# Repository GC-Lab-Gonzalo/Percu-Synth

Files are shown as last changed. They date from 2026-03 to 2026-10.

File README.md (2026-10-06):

# PercuSynth

**PercuSynth** es un laboratorio portátil de experimentación con electrónica, programación y síntesis de audio, desarrollado por **GC Lab Chile**.

La percusión y los sintetizadores son la excusa: el arte y la música son la puerta de entrada a un proceso de aprendizaje más amplio, donde explorar electrónica, código y tecnología se vuelve natural, entretenido y con sentido. Es un proyecto diseñado bajo la metodología **STEAM** — donde la ciencia, la tecnología, la ingeniería y las matemáticas se integran con el arte como motor creativo.

<p align="center">
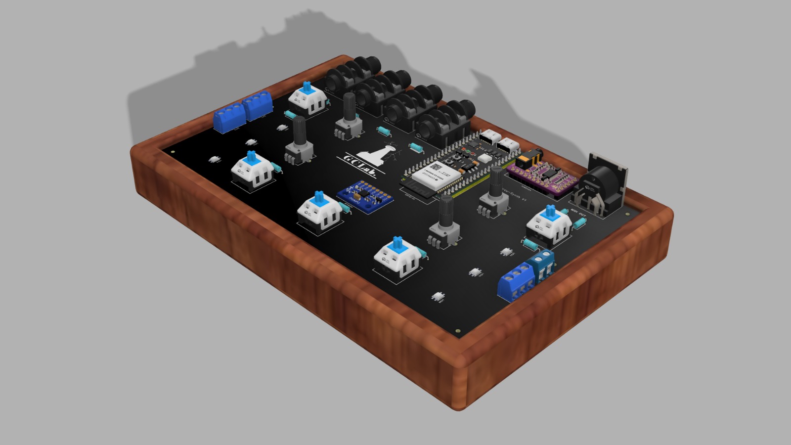
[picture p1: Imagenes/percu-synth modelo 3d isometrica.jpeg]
PercuSynth - modelo 3D
  
</p>

El hardware es compacto, portátil y basado en el microcontrolador **ESP32-S3**. Desde él se puede experimentar con síntesis de sonido, secuenciadores, controladores MIDI, sensores de movimiento, sampleo, luces reactivas y mucho más. Los firmwares y las herramientas web disponibles son solo el punto de partida — **el proyecto está en desarrollo activo** y las posibilidades son abiertas.

---

## ¿Qué se puede hacer con PercuSynth?

El laboratorio permite explorar una amplia variedad de ideas, por ejemplo:

- Sintetizadores y máquinas de ritmo con síntesis de audio en tiempo real
- Controladores MIDI para software de producción musical
- Secuenciadores de pasos con patrones grabables
- Detección de golpes y gestos con sensores piezoeléctricos e IMU
- Instrumentos por impacto y drones por vibración (el equipo apoyado en el piso)
- Reproducción de samples y loops cargados desde el navegador
- Experimentos con filtros, osciladores, envolventes y efectos digitales
- Visuales reactivas en tira o matriz LED WS2812 sincronizadas con sonido o gesto
- Síntesis audiovisual de video y videojuegos controlados por el hardware
- Máquinas generativas que componen solas: canciones, paisajes sonoros y ambientes de película
- Conexión con servicios de IA desde la propia placa: pedir un sonido o una canción hablando
- Integración con software como Ableton, GarageBand, Pure Data, etc.

Los firmwares y herramientas del repositorio son ejemplos concretos de estas posibilidades. El proyecto crece con cada experimento nuevo.

---

## Hardware

<p align="center">
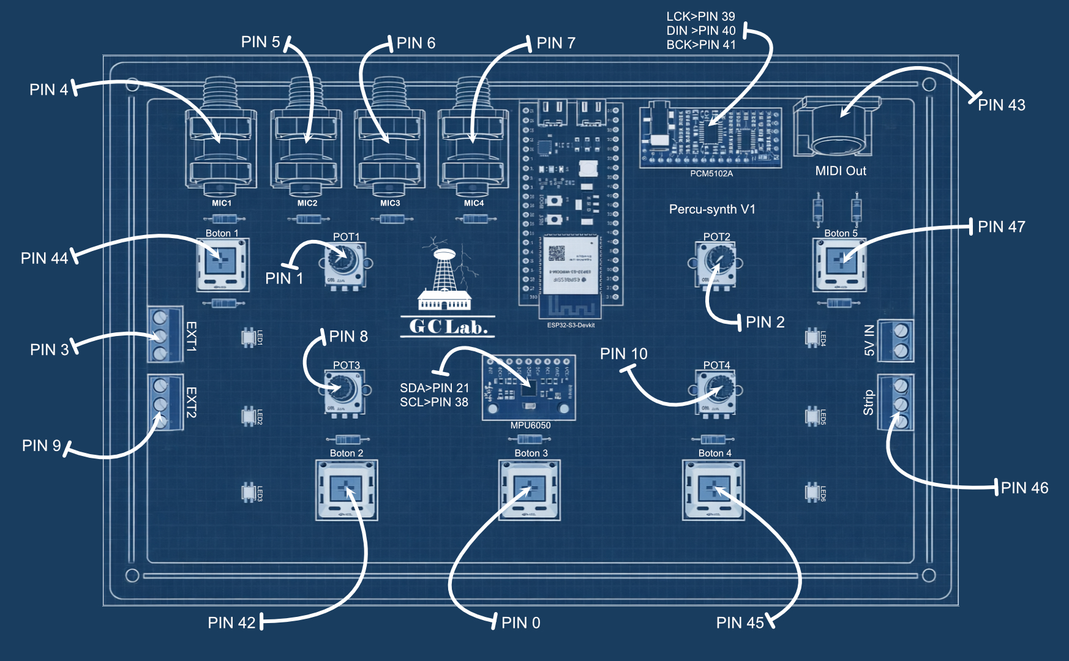
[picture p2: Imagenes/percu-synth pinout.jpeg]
PercuSynth - Pinout
  
</p>

> **Tip para usar con IA:** puedes subir directamente la imagen del pinout a cualquier asistente de IA (Claude, ChatGPT, Gemini, etc.) para que entienda el hardware y te ayude a crear nuevos firmwares. Mejor aún: pásale el [documento de contexto para IA](PROMPT_PARA_LA_IA.md) ([versión PDF](PROMPT_PARA_LA_IA.pdf)) — un documento madre con pinout, settings del Arduino IDE, librerías y patrones de código listos para que la IA genere firmware a la primera.

### Componentes principales

- **Microcontrolador:** ESP32-S3 (USB nativo, WiFi, Bluetooth)
- **DAC de audio:** PCM5102 vía I2S — salida estéreo 44.1 kHz · 16-bit
- **IMU:** MPU6050 — acelerómetro + giroscopio para control gestual (I2C)
- **Entradas:** 5 botones, 4 potenciómetros, 4 sensores piezoeléctricos, 2 sensores analógicos externos
- **Salidas:** Audio I2S · tira/matriz LED WS2812 · MIDI USB nativo · MIDI DIN-5

> **¿Quieres armar el tuyo?** La [lista de materiales](MATERIALES.md) tiene cada componente con su término de búsqueda, los tres caminos para armarlo (PCB fabricada, protoboard o placa perforada) y cómo pedir la placa en JLCPCB. Comprar la PCB es opcional.

### Pinout

| Señal | Pin ESP32-S3 |
|---|---|
| I2S LRCK | 39 |
| I2S DATA | 40 |
| I2S BCLK | 41 |
| Botones | 44, 42, 0, 45, 47 |
| Potenciómetros | ADC 1, 2, 8, 10 |
| Piezos | ADC 4, 5, 6, 7 |
| LED WS2812 (datos) | 46 |
| MIDI DIN-5 TX | 43 |
| I2C SDA (MPU6050) | 21 |
| I2C SCL (MPU6050) | 38 |
| Sensor externo A | ADC 3 |
| Sensor externo B | ADC 9 |

Todos los firmwares de audio generan señal a **44.1 kHz, 16-bit estéreo** a través del DAC PCM5102, con buffers DMA de 128 muestras.

### Archivos de circuito (`Hardware/`)

El diseño electrónico está abierto para que puedas fabricar tu propia placa o estudiar las conexiones:

La versión vigente es la **V2.0** (septiembre 2026): cada entrada de piezo lleva ahora diodo Schottky 1N5817 + 10 nF + 100 kΩ, y la placa trae sitio para el micrófono INMP441 y un conector OLED opcional. La lista de materiales completa está en [`MATERIALES.md`](MATERIALES.md).

- [`Schematic_Percu-synth_V2.0.pdf`](Hardware/Schematic_Percu-synth_V2.0.pdf) — esquemático completo
- [`PCB_1-PCB_PCB_Percu-synth_V2.0.pdf`](Hardware/PCB_1-PCB_PCB_Percu-synth_V2.0.pdf) — vista del PCB (top y bottom) para ubicar componentes
- [`Gerber_Percu-synth_1-PCB_PCB_Percu-synth_V2.0.zip`](Hardware/Gerber_Percu-synth_1-PCB_PCB_Percu-synth_V2.0.zip) — gerbers listos para enviar a fabricar

Los archivos `V1.1` siguen en `Hardware/` sólo como referencia de las placas antiguas.

- [`base_3d/`](Hardware/base_3d/) — **base imprimible en 3D** que reemplaza el marco de madera (STL y 3MF listos, más `generar_base.py` para ajustarla)
- [`LISTA_ALIEXPRESS_Percusynth.txt`](Hardware/LISTA_ALIEXPRESS_Percusynth.txt) — la lista de materiales de la V2.0 con los **links de compra** en AliExpress

---

## Firmwares disponibles

Cada firmware es un sketch Arduino independiente (`.ino`). Se compila y se carga por separado — no hay sistema de build centralizado. Los siguientes son los firmwares desarrollados hasta la fecha; el proyecto está en desarrollo activo y se irán sumando más experimentos con el tiempo.

### Síntesis y secuenciadores de audio

#### `drum_machine_basic` — Drum Machine con Secuenciador
- 10 voces polifónicas: kick, snare, hi-hat, crash, click
- Síntesis por osciladores + ruido LCG + filtros biquad bandpass en cascada
- Secuenciador de 4 pistas × 16 pasos con grabación en tiempo real
- Control de tempo y timbre por potenciómetros

#### `drum_ruido` — Drum machine de timbres ruidosos, salida limpia
- **Ruidoso no es distorsionado:** la suciedad se hace con *síntesis* (parciales inarmónicos, dos envolventes por golpe, saturación por bandas), nunca rompiendo el audio — nada de bit-crush ni diezmado, que solo producen aliasing
- **Los patrones son aleatorios:** no hay ritmos de fábrica. Cada BTN1 sortea 32 pasos nuevos con el "feel" del kit activo
- 5 kits (CYBER · DUBSTEP half-time · GLITCH · INDUSTRIAL · CAOS) y 7 pistas: kick, snare, hats, clank, metal, blast y bajo
- Un botón = una función: BTN1 patrón · BTN2 timbre · BTN3 tap tempo · BTN4 half-time · BTN5 fill. POT4 = beat repeat ×2/×4/×8/×16 sobre un reloj maestro que nunca se desfasa
- No hay play/stop: la máquina siempre corre, POT1 a cero es el mute. Requiere **FastLED**

#### `drum_poder` — Drum machine con peso + reloj MIDI por el DIN-5
- Hermana de `drum_ruido` con el signo cambiado: **acá no hay ruido como estética**. Bombos redondos con pegada de mazo, cajas grandes y afinadas, toms cantados, platos con brillo controlado
- **12 grooves escritos a mano** en el idioma de Sleep Token, Tool y Dream Theater, con compases impares de verdad: 7/8 (3+2+2), 5/8+7/8, 9/8, 13/8, 5/4, 12/8, doble bombo y 4/4 desplazado (3+3+3+3+2+2). Los patrones se escriben **como texto**, un carácter por semicorchea
- **Por el MIDI DIN-5 sale el RELOJ, no notas** (GPIO 43, 31250 baud): MIDI Clock a 24 PPQN + Start, y Stop+Start cada vez que se reubica el "1". La melodía la pone el sinte que lo recibe. Hubo tres versiones con bajo adentro (línea escrita por groove, tabla de ritmos sobre una grilla, patrones derivados del bombo) y las tres se descartaron: elegir el sonido y la secuencia en el sinte es más expresivo que cualquier tabla metida en el firmware, y el único trabajo real de la máquina es dar un pulso que no se mueva. Verificado: el tempo del reloj cae dentro del **0.04 %** del BPM en los 12 grooves
- **Es percusión y nada más**: la melodía la hacen las notas MIDI. Sólo el SUB (abajo de 60 Hz) sigue el acorde; todo lo que vive arriba de 1 kHz es **ruido filtrado** — no tiene nota, así que no puede hacer melodía —, y el decay tiene presupuesto por banda: el peso abajo es largo (sub 2.1 s, bombo 1.3 s) y arriba todo es corto (hat 0.13 s, tick 0.07 s)
- 8 pistas con **su propia banda** cada una (sub, bombo, toms, caja, clap, tick, hats, metal) y cadena de master fija: sidechain → sala corta → saturación de cuerpo → filtro → compresor de bus → limitador **con lookahead** → techo de 13 kHz
- **Exactamente los controles de `drum_ruido`, uno por uno**: BTN1 groove · BTN2 kit · BTN3 tap tempo · BTN4 medio tiempo · BTN5 redoble; POT1 volumen · POT2 filtro · POT3 cuerpo · POT4 beat repeat. Sin paneles, sin combos y sin pots congelados: todo eso existió mientras el firmware generaba las notas del bajo
- **El SUB lleva 2º y 3er armónico**: su fundamental vive en 33–45 Hz, así que en un parlante chico lo que se oye son los armónicos y el oído reconstruye la que falta
- **El audio corre en su propia tarea en el core 1** y los controles en el core 0. El ADC y `FastLED.show()` compartiendo `loop()` con el render eran lo que hacía que el DMA se quedara sin datos en los patrones densos y en los fills: eso era el chasquido. Y por lo mismo **no hay ni un `Serial.print`**. Requiere **FastLED**

#### `synth_basico` — Sintetizador Polifónico
- 5 voces con morphing de forma de onda (senoidal → cuadrada → diente de sierra)
- Vibrato LFO (±1.2%, 0.2–8.2 Hz) y filtro pasa-bajos one-pole controlados por potenciómetro
- Notas mapeadas a los botones: C4, D4, E4, F4, G4

#### `trance_imu` — Secuenciador de Trance Polifónico (IMU)
- Port del secuenciador de trance del **Proto-Synth v2** a I2S 44.1 kHz / 16-bit estéreo (audio de otra liga, buffers DMA no bloqueantes)
- **Polifónico:** cada paso dispara un acorde de 4 voces sobre un pool de 16 voces → textura "pluck de trance" con cola
- Osciladores sierra anti-aliasing (PolyBLEP) + filtro pasa-bajos resonante biquad **controlado en vivo por el IMU** (eje X → cutoff, eje Y → resonancia)
- 3 paneles de control (combos de botones): normal / notas-tonalidad / timbre-síntesis. Sin LEDs ni Serial: todo el CPU va al audio

#### `trance_imu_leds` — Trance Polifónico + 6 LEDs de placa
- Igual que `trance_imu`, pero usa los **6 LEDs WS2812 SMD internos** de la placa como visualizador (VU polifónico + flash al beat + color según el filtro IMU + paleta por panel)

#### `pads_imu` — Pads ambient profundos (sin secuenciador)
- Hermano ambient de `trance_imu`: **mismo motor de audio, pero sin patrones**. Los 5 botones latchean **acordes sostenidos** (attack → sustain → release sobre un pool de 32 voces, estéreo con detune y paneo por voz)
- **5 bancos de 6 acordes** + capa opcional de **arpegio** (6 tipos) sobre el acorde activo
- **Modo AUTO:** progresión diatónica generativa que se repite en 4/4, para dejarlo sonando solo
- 3 paneles de control; el IMU barre el filtro

#### `pads_imu_leds` — pads_imu + 6 LEDs de placa
- Igual que `pads_imu`, con los 6 LEDs SMD como visualizador: paleta por panel, barra de energía del pad y un **punto que avanza con cada nota del arpegio**. También maneja el LED RGB del módulo (GPIO48). Requiere **FastLED**

#### `cancion_aleatoria_leds` — Máquina de canciones aleatorias
- **Autónoma:** un botón de Play/Stop y tres perillas de volumen (pad / melodía / percusión). Nada más
- Cada Play genera **una canción entera y coherente**: sortea tonalidad, modo (7 escalas), progresión diatónica, BPM, voicing, síntesis y ritmo del pad
- Encima corre una **melodía monofónica generativa** organizada en frases (cada frase sortea su propio ritmo, timbre, registro y envolvente) que siempre cae en la escala
- Y una **percusión sintetizada aleatoria** (kick, snare-rim, hats — sin samples) con acentos, ghost notes y un mini-fill cada 4 compases
- 5 arquetipos (AMBIENT / CINEMATIC / PULSE / PLUCK / DRIVE) fijan el carácter global, así que las canciones suenan **categóricamente distintas** entre sí. Stop → Play = canción nueva. Requiere **FastLED**

#### `paisajes_relax_leds` — Paisajes sonoros para relajar
- **10 capas sintetizadas en tiempo real** (sin samples) que se combinan libremente: viento, olas, campanitas, gotas de agua, grillos, fogata, lluvia, cuenco tibetano, arroyo y pájaros
- Cada botón enciende una capa (toque = principal, mantener >0.6 s = alterna). Todo **seco y natural**, sin delay ni reverb
- Dos anillos WS2812 de 30 LEDs (afuera = eventos, adentro = ambiente). Arranca en silencio. Requiere **FastLED**

#### `cyber_kit` — Secuenciador de texturas, FX y leads
- **No es una drum machine:** 4 bancos × 5 sonidos (LEADS / TEXTURAS / FX / BAJOS) — leads neón, campanas FM, hoovers, risers, nubes granulares, drones oscuros, zaps, glitches, reeses, subs
- Los sonidos afinados viven **dentro de una escala seleccionable** (10 escalas, tónica variable)
- **Disparo instantáneo:** los botones suenan en el flanco de presión, y los combos de dos botones *deshacen* la acción individual con un fade de 4 ms. Se toca al tiro y los combos igual funcionan
- 2 modos: PERC (los botones disparan) y SEQ con transporte completo (play/stop, reversa, beat repeat, velocidad, caos)
- 4 paneles de pots, incluido uno de **macros de síntesis** (attack 0.5 ms–0.8 s, decay, textura, pitch global ±12). Requiere **FastLED**

#### `oscilador_escalas` — 4 pots = 4 osciladores por escala
- Port del sketch `Oscilador_4_escalas` del **Proto-Synth v2**, **sin Mozzi**, al motor I2S estéreo de 44.1 kHz del PercuSynth
- La idea original intacta — cada pot es un oscilador cuantizado a la escala activa — pero por debajo: stack de **3 voces en unísono** paneadas + sub-oscilador, formas de onda **PolyBLEP**, portamento de 40 ms y cuantización **con histéresis** (el ruido del ADC ya no hace saltar la nota)
- Controles directos, sin paneles ni combos: BTN1 escala (10) · BTN2 octava · BTN3 intermitencia · BTN4 mantenido + POT1 = tempo · BTN2+BTN4 = menú de 5 modos · BTN5 forma de onda
- Filtro resonante barrido por el eje X del IMU + **delay ping-pong** cuyo tiempo lo fija el tap tempo. Requiere **FastLED**
- Audio en su propia tarea en el **core 1** y controles en el core 0: así los 4 osciladores en cuadrada o pulso ya no vacían el DMA (era el ruido que aparecía al cambiar de onda)

#### `oscilador_escalas_clock` — El mismo dron + reloj MIDI por el DIN-5
- `oscilador_escalas` con **MIDI Clock por el DIN-5** (24 PPQN, sólo reloj, nada de notas) al tempo del tap: **Start al activar la intermitencia, Stop al apagarla, Stop+Start en cada tap** para que el "1" del sinte externo caiga en el mismo corte
- El clock se **cuenta en el audio** con el mismo contador que el corte (cero deriva) y se **manda desde la tarea de control** a 1 kHz. Los ticks salen siempre, aun parado, para que el sinte ya tenga el tempo cuando llegue el Start
- Los **6 LEDs prenden al ritmo de la intermitencia** (siguen la envolvente que corta el audio) y el **LED RGB del módulo muestra el color de la nota** que suena, pasando al siguiente oscilador activo en cada pulso. Requiere **FastLED**

#### `bajo_8_pasos` — Secuenciador de bajo de 8 pasos
- **8 pasos** de un **bajo monofónico lleno de armónicos**: dos sierras PolyBLEP desafinadas + cuadrada una octava abajo, saturación suave y filtro pasa-bajos resonante con **envolvente de filtro**
- Creado en conjunto con los participantes del **taller abierto en Hive Espacios**
- Todas las notas en **La pentatónica menor** (11 notas por pot, 2 octavas; pot al mínimo = paso en silencio)
- BTN1 **play/stop** · BTN2 **panel A** (notas de los pasos 1–4) · BTN3 **panel B** (pasos 5–8) · BTN4 **panel C** (volumen · velocidad · decay · cutoff) · BTN5 **octava**
- Al cambiar de panel un pot **sólo toma el control cuando lo mueves**: saltar de panel nunca pisa las notas del otro
- **Tira WS2812 de 121 LEDs** encadenada a la placa: cada paso dispara una **bala de luz multicolor** que avanza por la tira al ritmo del tempo. Requiere **FastLED**

#### `bajo_8_pasos_fsr_clock` — El bajo de 8 pasos con FSR al filtro y reloj MIDI
- `bajo_8_pasos` con **dos cosas encima y nada más**: el motor de sonido, los controles y las balas de luz son idénticos
- **FSR (sensor de presión) en EXT1 (GPIO 3)**: apretar **abre el filtro** hasta 3 octavas por encima de donde dejó el POT4 — el pot sigue mandando el reposo y la resonancia, el FSR es expresión en vivo encima (como el IMU en `espacio_modular`). Suelto suena **exactamente igual que el original**
- Los dos extremos (`FSR_SUELTO` / `FSR_APRETADO`) son **lecturas medidas, no constantes mágicas**, y el mapeo es una recta entre ellas: la **polaridad del divisor da lo mismo**. Se calibra con `MOSTRAR_ESTADO` en 1 y el monitor serie
- **MIDI Clock por el DIN-5** (24 PPQN, sólo reloj) al tempo del secuenciador: **Start al Play con el "1" en el paso 1**, Stop al parar, y los ticks salen siempre, aun parado. Contado en el audio con el mismo contador de muestras que los pasos (cero deriva) y mandado desde la tarea de control a 1 kHz
- **La tira de 121 LEDs cambió**: en vez de sólo las balas, **8 efectos que se sortean solos** (balas · ondas · VU · chispas · arcoíris · plasma · bandas · serpiente), uno nuevo cada 4 compases y en cada Play, nunca el que estaba, y con paleta/dirección/parámetro sorteados también. Los ocho reaccionan al golpe del paso, a la nota, a la **envolvente real del bajo** (la publica la tarea de audio) y a la **presión del FSR**
- La tira lleva **su propio limitador de corriente** (`TIRA_MAX_MA`, 300 mA): con la tira colgada del 5 V de la placa, un efecto que prende los 121 LEDs pide ~2 A, hunde el riel y **corta el audio**. Está escrito como un limitador de audio — baja al instante y sube despacio, porque lo que hunde el riel es el *escalón* de corriente. Con fuente propia para la tira se sube ese número y vuelven a brillo completo. Requiere **FastLED**

#### `industrial_matriz` — Base de bombo y bajo + fábrica en paralelo + matriz 32×8
- **Base**: bombo de tres bandas a negras y el bajo de `bajo_8_pasos` siguiendo una progresión de 4 acordes en La menor, con 6 líneas escritas para caer siempre entre los bombos; un **arpegiador** recorre el acorde y un **pluck** toca una de 8 melodías escritas en grados del acorde
- **Percusión industrial en paralelo**: 6 pistas (hat · martillo · pistón · clap · hat abierto · tom), sin metales afinados. Cada ciclo dura de 10 a 32 pasos y forma un **polirritmo** contra los 16 de la base, que se realinea cada 4 compases
- BTN1 play/stop · BTN2 patrón industrial · BTN3 tema nuevo (acordes + bajo + melodía) · BTN4 mantenido + POT1 = tempo · BTN2+BTN4 = menú de 5 modos · BTN5 break mientras se mantiene · POT1 volumen · POT2 mezcla base↔fábrica · POT3 corte del bajo · POT4 densidad industrial
- **Matriz WS2812 de 32×8** encadenada a la placa: 8 escenas psicodélicas (túnel · plasma · caleidoscopio · espiral · figuras · moiré · ondas · damero) amarradas al tempo, que se sortean cada 4 compases, prueba de orientación al encender y limitador de corriente propio. Requiere **FastLED**

#### `secuenciador_melodico` — 16 pasos en modos griegos *(por Nicolás Martínez)*
- Secuenciador **monofónico** de 16 pasos: cada paso es un **grado de la escala** o un silencio, en uno de los **7 modos griegos** (BTN2 los recorre)
- BTN1 play/stop · BTN3 reversa · BTN4 al azar · BTN5 borrar; POT1 volumen · POT2 tempo · POT3 transposición ±12 · POT4 envolvente
- Trae una **webapp por Web Serial** para editar los pasos en pantalla. Requiere **ESP32Synth** y **FastLED**

#### `secuenciador_melodico_cromatico` — 16 pasos polifónicos, 12 notas *(por Nicolás Martínez)*
- Secuenciador **polifónico** sobre una octava cromática: cada paso puede tener cualquier combinación de las 12 notas (acordes incluidos), 12 voces
- BTN2 cambia la onda (pulso / sierra / triángulo / seno); el resto de los controles como `secuenciador_melodico`
- Webapp por Web Serial con la grilla de 16 × 12. Requiere **ESP32Synth** y **FastLED**

#### `la_partida` — "La partida" de Víctor Jara en 3 pistas MIDI
- Toca el arreglo desde sus **3 pistas MIDI** a los tiempos exactos del archivo (80 BPM, preciso a la muestra): **melodía** con un lead filtrado con vibrato, **bajo** en sierra + cuadrada levemente desafinadas (una octava abajo) y **arpegio** con un pluck electrónico de filtro que se cierra
- BTN1 **play/stop + panel general** (volumen · velocidad) · BTN2 **melodía** (volumen · vibrato · filtro · resonancia) · BTN3 **bajo** (volumen · filtro · resonancia) · BTN4 **arpegio** (volumen · ataque · decay)
- Diseñado para no hacer clicks: una voz de arpegio por altura, ataques que suben desde donde está la envolvente, stop con cierre de 40 ms. Las notas salen del proyecto de Ableton con `extraer_cancion.py`. Requiere **FastLED**

#### `espacio_modular` — Ambientes de película (monofónico)
- **24 patrones que son TEMAS, no figuras:** un tema se define tanto por su ritmo largo-corto como por sus notas, y **cada nota dura hasta la siguiente** — el espaciado *es* la duración. Por eso suena a música de película y no a un arpegio
- Debajo, un **dron continuo** en la tónica y una **progresión no funcional** de un acorde por ciclo de 4 compases (9–38 s por acorde): eso es lo que lo vuelve ambiente en vez de canción
- 8 modos de paleta cinematográfica (eólico, frigio, NÓRDICO, mixolidio, lidio, ÁRABE, BIZANTINO, menor armónica), todos con tríadas consonantes
- Un solo panel: 5 botones y 4 pots, una función cada uno, sin combos ni páginas escondidas. Play sortea el modo, BTN2 sortea el tema
- Imprime modo/tema/tonalidad por Serial en cada botón, para que puedas identificar un sonido que te gustó

#### `impact_chimes` — Campanas por golpe en el piso
- Instrumento por **impacto**: se apoya el equipo en el piso y el **acelerómetro detecta los golpes** → dispara notas de una escala tipo campanas (eólica por defecto)
- Una escala distinta por cada botón; los potenciómetros controlan la síntesis

#### `impact_chimes_leds` — Campanas por impacto + show de luces
- Hermano de `impact_chimes` con **show WS2812 de 68 LEDs** y **3 timbres** (campana / marimba / guitarra eléctrica), en una sola escala mágica: **C lidio**
- Cada golpe en el piso dispara una nota (caminata melódica) y un efecto de luz reactivo. BTN1/BTN5 recorren 5 efectos (onda, cometa, pulso, chispas, arcoíris); BTN2/3/4 eligen el timbre
- Umbral dinámico anti-doble-disparo; FastLED por RMT para no chocar con el I2S. Requiere **FastLED**

#### `laser_chimes` — Campanas al cortar el haz de un láser
- Hermano de `impact_chimes` con el **sensor de entrada cambiado**: un **LDR + 220 Ω en el sensor externo A (EXT1, GPIO 3)** vigila un **haz de láser**; cada vez que algo lo cruza se dispara una nota de la escala
- Mismo motor de sonido y mismos controles que `impact_chimes` (una escala por botón, pots = ataque/decay/brillo/timbre). El corte más profundo suena más fuerte
- El LDR se muestrea a **1 kHz en el core 0** (el audio se queda con el core 1) y la cola de DMA es corta (≈12 ms): la nota se oye en el acto
- Los **límites de lectura del LDR** (`LDR_LASER` / `LDR_TAPADO`) son variables en el `.ino`; con `MOSTRAR_ESTADO 1` el Monitor Serie imprime `raw` y los `min`/`max` vistos para copiarlos directo. Sin librerías externas

#### `grabador_campo` — Grabadora de campo con efectos en las perillas
- El micrófono INMP441 pasa por **ganancia, filtro (pasa-bajos ↔ pasa-altos en un pot), EQ de color y un efecto** (eco ping-pong, catedral, chorus, flanger, phaser) y se graba a una **microSD** (SPI en GPIO 14–17)
- Cada toma deja dos WAV alineados muestra a muestra: el **procesado** (estéreo 24 bit) y el **crudo** del micrófono (mono 24 bit, sin tocar)
- BTN3 **congela** los últimos ~3 s como una nube de granos que el filtro y el efecto siguen moldeando. Colchón de 8 s en PSRAM: la tarjeta nunca corta el audio. Requiere **PSRAM** y **FastLED**

#### `voz_fx` — Procesador de voz en tiempo real
- Hablas o cantas al **micrófono INMP441** y la voz sale transformada por el DAC, sin grabar (~12 ms de latencia)
- **11 efectos** en BTN1: voz limpia, electro con trémolo al tempo, autotune + vocoder, robot, vocoder de 12 bandas, pitch, armonizador, eco de cinta, catedral y más. POT1–3 modifican el efecto, **POT4 es siempre el volumen**; BTN2 prende/apaga la puerta de ruido
- Usa **audífonos**: con parlante el micro escucha la salida y los efectos largos se acoplan. Requiere **FastLED**

#### `mezclador_pistas` — Una canción en 4 pistas desde la microSD, con visuales
- Toca **batería, bajo, voz y otros** desde un solo WAV intercalado en la microSD (SPI en GPIO 14–17), sincronizados a la muestra y en loop. El audio lo mezcla la placa: el computador no lo toca
- Por **bancos**: BTN1 = banco general (POT1–4 = volumen de bajo, voz, batería y otros; mantener = play/stop, 2,5 s = siguiente canción); BTN2–5 = banco de cada pista (POT1 filtro pasa-bajos ↔ pasa-altos · POT2 resonancia · POT3 efecto rítmico gate/repeat al pulso · POT4 intensidad)
- Detecta los golpes de cada pista (y bombo/caja/platillo en la batería) y los manda por USB a **Resonancia**, donde cada pista mueve su capa visual. `preparar_cancion.py` convierte las pistas de Moises/Demucs. Requiere **PSRAM** y **FastLED**

#### `trance_pistas` — Trance sintetizado en 4 pistas, con visuales (sin microSD)
- El hermano sintetizado de `mezclador_pistas`: **trance con peso** (referencia: Chemical Brothers) con la batería de `drum_poder`, el bajo de `bajo_8_pasos`, un riff que sólo toca notas del acorde y un pad que crece por secciones con stabs rave. 6 temas de 32 compases con ruptura y drop, 128–140 BPM; BTN1 mantenido 2,5 s = siguiente tema
- Los mismos bancos y la misma salida serial que `mezclador_pistas`: Resonancia lo trata igual. Se instala **desde Resonancia** (ESP Web Tools), sin Arduino IDE. Requiere **FastLED**; la PSRAM es opcional

#### `oled_video_techno` — Video vertical en la OLED + techno con bombo
- Un **video vertical** (un short) corre en la **pantalla OLED SSD1306 puesta de lado** (64×128), **amarrado al tempo**: al subir el BPM el video se acelera, con Stop se congela, cada Play lo reinicia con el "1" y en cada bombo la pantalla late (contraste)
- Debajo, un **secuenciador techno**: bombo de tres bandas en negras, línea ácida de 16 pasos (acentos y ligados a la 303) y hats. POT1–4 = corte / resonancia / envolvente / decay del filtro; BTN1 play/stop, BTN2 patrón nuevo, BTN3 tap tempo, BTN4 bombo sí/no, **BTN5 graba a la microSD lo que sale por los audífonos** (WAV estéreo 16 bit, sin micrófono; mismo cableado SPI que `grabador_campo`)
- El video se convierte con `convertir_video.py` (ffmpeg → cuadros de 1 bit ya en el orden de memoria de la SSD1306 → `video.h`). Requiere **FastLED** (LED de estado de la grabación)

#### `seismic_drone` — Drones épicos por vibración de la tierra
- Hermano grave de `impact_chimes`: el MPU6050 en **±2g** detecta la vibración del suelo → genera un **dron épico** (sierra estéreo desafinada + sub-oscilador, filtro resonante que "respira")
- Escalas épicas; los potenciómetros controlan la textura

#### `dub_siren` — *(en desarrollo)*
- Sintetizador "sirena dub" con 3 samples polifónicos + oscilador siren con LFO + delay tape con feedback
- Generación del firmware (con samples embebidos) vía `tools/dub_siren_generator/`
- Plan completo y arquitectura en [`firmwares/dub_siren/PLAN.md`](firmwares/dub_siren/PLAN.md)

### Firmwares con IA (requieren WiFi y claves de API)

Estos seis firmwares llaman a servicios externos (OpenAI, NagaAI, ElevenLabs) desde el propio
ESP32-S3. Necesitan además un **micrófono INMP441** por I2S y, salvo los dos asistentes simples
(`asistente_ia` y `asistente_naga`), un módulo **con PSRAM**.

> **Las claves no están en el repositorio.** Cada uno de estos sketches trae un
> `secretos.example.h`: cópialo a `secretos.h` **en la misma carpeta** y escribe ahí tu WiFi y tus
> API keys. `secretos.h` está en el `.gitignore`, así que nunca se sube por accidente. Si falta,
> el sketch no compila y te avisa con un `#error` claro en vez de fallar recién al encender.

#### `asistente_ia` — Asistente de voz (Whisper → GPT → TTS)
- Mantienes BTN1, hablas, y te responde por el parlante. El más simple de la familia: el que conviene leer primero para entender cómo se conecta el hardware a una API
- Micrófono INMP441 (16 kHz mono) → Whisper → GPT-4o-mini → TTS (PCM 24 kHz) → DAC PCM5102, sin resamplear
- Los 6 LEDs SMD indican el estado: verde listo, rojo grabando, ámbar procesando, cian hablando

#### `asistente_naga` — El mismo asistente, sobre NagaAI (una sola clave, modelos gratis)
- [NagaAI](https://naga.ac/) es un **agregador**: una API compatible con OpenAI que enruta a muchos proveedores con **una sola clave y un solo saldo**. Los endpoints son idénticos; lo que cambia es el host, los **nombres de modelo** y un parámetro
- Ojo con eso último: **`whisper-1`, `tts-1` y `gpt-4o-mini` no existen en Naga** (hay `whisper-large-v3`, `gpt-4o-mini-tts`, `llama-3.3-70b-instruct:free`, voces de ElevenLabs…), y el límite de respuesta es `max_completion_tokens`, no `max_tokens`. Copiar los nombres de OpenAI tal cual da 404 y silencio
- Viene con los tres modelos **`:free`** puestos por defecto: funciona **sin gastar saldo**, que es lo que hace falta en un taller con diez placas
- La reproducción **lee la cabecera WAV** en vez de asumir 24 kHz: frecuencia, canales y bits vienen en el archivo y el I2S se reconfigura en caliente, así cambiar de voz no obliga a tocar ninguna constante. Si llega un MP3 lo detecta y **lo avisa por Serial** en vez de reproducir ruido
- `MOSTRAR_ESTADO` imprime todo el recorrido a 115200: lo que entendió, lo que respondió, los códigos HTTP con el cuerpo del error y el formato de audio recibido

#### `asistente_musical` — Conversas con GPT sobre música que nunca se detiene
- Cruce de la cadena de red de `asistente_ia` con el motor de voces de `pads_imu`: **hablas con GPT mientras un fondo armónico generativo sigue sonando**
- El cambio de arquitectura que lo hace posible: un **único mixer de 44.1 kHz** dueño del I2S corriendo en el **core 1**, y el asistente en el **core 0** junto al stack de WiFi — así los segundos que bloquea el TLS no cortan la música
- El TTS llega a 24 kHz y se **resamplea a 44.1 kHz**, pasa por un pasa-altos con cutoff en un pot (limpio → megáfono) y se suma **después** del filtro del pad
- **Ducking sidechain** real: la voz baja la música. Y BTN1 apaga el pad mientras grabas, porque el micrófono escucha al parlante y Whisper transcribiría la música

#### `sampler_ia` — Pides un sample hablando y lo disparas
- Dices el sonido que quieres → Whisper transcribe → GPT lo convierte en un prompt de efecto en inglés → **ElevenLabs** lo genera → se recorta, normaliza y carga en un slot de PSRAM
- 3 slots: BTN2/3/4 disparan en el flanco de presión; **manteniendo >0.6 s** ese slot pasa a loop sostenido. BTN5 corre un secuenciador de 16 pasos donde puedes **hacer overdub** tocando en vivo
- Los slots vacíos **prestan el último sample transpuesto** (+3 y +7 semitonos = una tríada menor de un solo sonido)
- Pots: BPM, volumen, pitch en vivo (±12) y **stutter granular**; el IMU barre el filtro. Tira de 80 LEDs encadenada a los 6 internos
- El formato `pcm_22050` requiere plan Pro de ElevenLabs: en Starter **cae solo a `ulaw_8000`**, decodificado en línea

#### `oscilador_ia` — El sample de IA *es* el oscilador
- Pides un **sonido** por voz y ese sample se vuelve el oscilador del instrumento. A ElevenLabs se le manda solo el sonido traducido al inglés: **no entiende de notas ni de Hz**, y las coletillas musicales lo confunden
- Al cargar, el firmware **mide la fundamental real por autocorrelación** (con guarda de error de octava y refinamiento parabólico), así que queda afinado al centésimo *donde sea* que haya caído el sample
- Un **loop de sustain con crossfade horneado** deja que las notas suenen para siempre: drones infinitos con el sample como oscilador continuo
- 10 escalas con vocabulario de progresiones por modo. 6 modos: teclado, 4 arpegiadores y una secuencia generativa de 4 compases. Cambiar la escala reinterpreta los mismos grados = recoloreado modal instantáneo

#### `compositor_ia` — Le pides una canción con la voz
- Fusión de `asistente_ia` (mic → Whisper → GPT) con el motor de `cancion_aleatoria_leds`: **GPT responde un JSON de canción** y el PercuSynth la toca
- Bajo con 5 patrones, comping por golpes, 5 gramáticas de melodía, forma con secciones (intro → verso → coro) y **swing real** en todo el grid
- El prompt completo vive en `COMPOSER_PROMPT` dentro del sketch: puedes pedirle el JSON a cualquier IA en el PC y **pegarlo por el Monitor Serie, sin WiFi**

### Controladores MIDI y máquinas audiovisuales

#### `MIDI_Drum` — Controlador MIDI de Percusión
- Convierte golpes físicos y gestos en mensajes MIDI USB (canal 10 / GM drums)
- Tres modalidades de entrada: botones (cola circular), sensores piezoeléctricos (peak-detection 15 ms) e IMU (ventana 20 ms)
- Debounce de 50 ms por piezo y 25 ms por botón
- Compatible con cualquier software o hardware que reciba MIDI

#### `drum_midi_leds` — Drum Machine + MIDI + Luces
- Secuenciador de 16 pasos × 4 drums (kick, snare, hi-hat, crash) sincronizado con efectos full-strip cinematográficos en la tira WS2812
- Salida MIDI USB en canal 10 (notas 36, 38, 42, 49) — el PercuSynth queda como controlador de un DAW
- BTN5 alterna entre modo **GRAB** (grabación en tiempo real) y **PLAYBACK**
- Potes para brillo, tempo (60–240 BPM), color base del fondo y velocity MIDI (60–127)
- Cola de NoteOff diferidos para mantener los gates MIDI limpios

#### `trance_midi_leds` — Trance melódico MIDI + matriz 20×20
- El mismo motor de secuenciador de `trance_imu` pero **monofónico y melódico**: cada paso envía **una sola nota** por MIDI USB a tu DAW/sinte (true mono, sin notas solapadas)
- El IMU se traduce a **MIDI CC** (CC74 filtro / CC71 resonancia) para barrer el filtro del sinte moviendo el aparato
- En paralelo, la matriz 20×20 corre un show estilo **fiesta electrónica** reactivo al beat

#### `laser_midi_wifi` — Nodo sensor que manda MIDI por WiFi *(ESP32-C3)*
- Nació experimentando con **malabarismo**: detectar las **clavas en el aire** y que sus pasos generen música. El sensor va lejos del computador, así que el MIDI viaja por **WiFi con RTP-MIDI**
- Por ahora es la **prueba de enlace**: manda un Do por segundo para comprobar la cadena ESP32-C3 → WiFi → sesión RTP-MIDI → computador o iPhone. Crea su propia red o se une a la tuya
- Las redes y claves van en `secretos.h` (ver *Credenciales*). Requiere la librería **AppleMIDI** (lathoub)

#### `matrix_midi_anyma` — Máquina audiovisual electro (matriz 20×20)
- Máquina **estilo Anyma** que combina tres cosas: **secuenciador interno** de 16 pasos (drums ch10 + bajo *acid* ch1 por USB MIDI), **MIDI Clock Master** (24 PPQ) y un **motor visual 2D** de 5 escenas sobre la matriz WS2812 20×20
- Las visuales reaccionan tanto al secuenciador interno como a **notas MIDI entrantes** (un secuenciador externo también pinta la matriz)
- No genera audio: es controlador MIDI + visualizador

### Pruebas de hardware

Sketches mínimos de diagnóstico para verificar cada periférico. Varios evitan el USB/Serial a propósito (el CDC puede provocar reinicios durante las pruebas):

- **`test_system`** — **Empieza por aquí con una placa recién armada.** Vuelca por el Monitor Serie el estado en vivo de *todos* los componentes en una sola pantalla, y acepta comandos para lanzar auto-tests de audio y de luces
- **`test_leds`** — Test de la tira LED WS2812: 6 modos de animación (sólido, chase, rainbow, twinkle, pulso, meteor). LEDs 0-5 (SMD internos) siempre apagados; del 6 en adelante activos. Requiere **FastLED**
- **`test_imu`** — Comprobación mínima del IMU por **Monitor Serie**: WHO_AM_I, aceleración (g) y giro (°/s) de los 3 ejes
- **`test_imu_led`** — Comprueba el IMU **sin USB ni Serial**; el resultado se ve en la **tira LED**
- **`test_imu_sound`** — Comprueba el IMU por **sonido** (DAC), sin LEDs, USB ni Serial

---

## Herramientas web (`tools/`)

Páginas HTML standalone (sin build, sin npm) que cumplen distintos roles según la herramienta:

1. **Generadores de firmware** — drag & drop de audios → la webapp produce un `.ino` con los samples embebidos en flash como arrays `PROGMEM`. Lo flasheas con Arduino IDE y la web no se usa más hasta que cambies los samples. (`sample_loader`, `loop_loader`, `dub_siren_generator`, `loops/bpm_mono_44100`)
2. **Flasheo desde el navegador** — instala el firmware compilado directo al ESP32-S3 vía **ESP Web Tools**, sin abrir Arduino IDE. (`percu_control`)
3. **Control remoto en vivo** — se conecta al PercuSynth ya flasheado vía **Web MIDI** y edita patrón / FX / transport en tiempo real. (`step_sequencer_loader`)
4. **Instrumento en el navegador** — lee un controlador MIDI USB (**Web MIDI**) y suena al instante con **Web Audio**, además de generar su `.ino`. (`midi_sampler`)
5. **Síntesis audiovisual** — usa la PercuSynth (vía **Web Serial**) como controlador de visuales/sonido en el navegador. (`video_synth`)
6. **Instrumentos y secuenciadores en el navegador** — el PercuSynth como controlador de un motor que suena en la página. (`arp_matrix`, `scale_osc`, `generador_estilos`)

La mayoría requiere **Chrome o Edge** (Firefox/Safari no soportan Web Serial ni Web MIDI). Cada herramienta tiene su propio `README.md` con detalles:

### [`percu_control/`](tools/percu_control/) — Panel de control universal + flasheo
Interfaz visual completa para configurar el PercuSynth: osciladores con 5 formas de onda, octave shift, mixer, ruido (white/pink), drive multimodo (off/soft/fold/bit), filtro, LFO y master. **Incluye un botón "⚡ FLASH FW" que instala el firmware directo al ESP32-S3 desde el navegador** usando ESP Web Tools — no requiere Arduino IDE para usuarios finales.

### [`sample_loader/`](tools/sample_loader/) — Cargador de samples one-shot
Drag & drop de hasta 5 archivos de audio (máx 2 s c/u). **Genera un `.ino` con los samples embebidos en flash como arrays `PROGMEM`**. El firmware generado convierte al PercuSynth en un sampler polifónico con pitch shift cuantizado a escala frigia.

### [`loop_loader/`](tools/loop_loader/) — Cargador de loops + hits con preview
Genera firmware con 3 loops (hasta 8 s, wrap sin click) + 6 hits one-shot (hasta 3 s, polifonía 3 voces). Preview en navegador con sliders que simulan los pots y el IMU.

### [`step_sequencer_loader/`](tools/step_sequencer_loader/) — Secuenciador remoto en vivo
Doble personalidad: **(1)** genera firmware con 6 samples embebidos y secuenciador 6×16; **(2)** una vez flasheado, controla el PercuSynth en vivo vía **Web MIDI** — editar patrón, FX y transport sin re-flashear. El PercuSynth queda como MIDI Clock Master.

### [`dub_siren_generator/`](tools/dub_siren_generator/) — Generador de dub siren
Genera firmware con 3 samples polifónicos + oscilador siren con LFO modulado por POT + delay tape con feedback (hasta auto-oscilación) + pitch global por IMU. Sample rate seleccionable (44.1 kHz / 22 kHz lo-fi).

### [`midi_sampler/`](tools/midi_sampler/) — Sampler MIDI USB (1 sample · 4 pots)
Lee un controlador MIDI USB vía **Web MIDI** y reproduce **un solo sample** (ej. una campana) según la nota MIDI que entra, transpuesto desde una nota base configurable. 4 potenciómetros: volumen/attack/decay/cutoff (también por CC MIDI). Suena en el navegador con **Web Audio** (testeable sin hardware: teclado en pantalla + teclas del PC) y, sin sample cargado, usa un seno afinado. Pestaña aparte para **generar el `.ino`** que convierte al PercuSynth en un sampler MIDI físico de 1 sample.

### [`video_synth/`](tools/video_synth/) — Sintetizador audiovisual de video
Webapp de una página que **importa un video y lo sintetiza en imagen Y sonido** en tiempo real, controlado por la PercuSynth vía **Web Serial** (o el micrófono del PC). Minimalista: cada control hace una sola cosa obvia.

### [`arp_matrix/`](tools/arp_matrix/) — Arpegiador polifónico + matriz 64×32
Proyecto colectivo nacido en el taller del PercuSynth. Arpegiador polifónico con una **matriz LED horizontal de 64×32** reactiva al sonido: 8 modos griegos, 6 patrones, ADSR y 3 paneles de control. Suena en el navegador (**Web Audio**), se controla con el hardware (**Web Serial**) y también **genera el `.ino`**.

### [`scale_osc/`](tools/scale_osc/) — Motor de tono cuantizado
Cada potenciómetro es un **oscilador cuantizado a una escala**: la versión de navegador del firmware `oscilador_escalas`. Sirve para probar el concepto sin flashear nada, o como instrumento en vivo con el PercuSynth de controlador (**Web Serial** + **Web MIDI**, con el TILT del IMU barriendo el filtro).

### [`generador_estilos/`](tools/generador_estilos/) — Motor de estilos musicales *(en desarrollo)*
Un estilo musical entendido como **datos, no como código**: blues, techno, synthwave y grunge descritos en JSON que el motor toca con Web Audio. El diseño completo está en [`PLAN.md`](tools/generador_estilos/PLAN.md) y el prompt para pedirle canciones a una IA en [`PROMPT_IA.md`](tools/generador_estilos/PROMPT_IA.md).

### [`loops/bpm_mono_44100/`](tools/loops/bpm_mono_44100/) — Editor BPM-aware de loops
Variante avanzada de `loop_loader` con tap-tempo, transporte master con beat dots, snap a compás y mono-switcher (un solo loop activo a la vez) + sampler polifónico paralelo. Para sesiones donde los loops tienen que estar sincronizados en BPM.

---

## Videojuegos (`videogame/`)

Los tres se controlan con el PercuSynth vía **Web Serial** (mismo protocolo y mismo firmware de control) y los tres son **totalmente jugables con mouse y teclado** cuando no hay hardware conectado.

### [`cyber_flight/`](videogame/cyber_flight/) — NEON STRIKE
**Shooter cyberpunk en primera persona** sobre una megaciudad distópica: pilotas un caza y derribas naves enemigas. Los **2 ejes del IMU** apuntan la mira, **BTN5/BTN1** disparan desde cada lado y **BTN2+BTN4** juntos sueltan una bomba. Canvas 2D synthwave con efectos de sonido en Web Audio y sistema de oleadas, puntaje y multiplicador.

### [`nebula_gp/`](videogame/nebula_gp/) — NEBULA GP
**Simulador de carreras FPV de drones:** 3 vueltas contra 4 bots en un circuito neón cerrado con lomas y 16 puertas, bajo un cielo galáctico. Proyección 3D hecha a mano sobre Canvas 2D, sin WebGL. El **IMU** da giro y cabeceo, **BTN5** acelera, **BTN1** frena, **BTN2/BTN4** desplazan de lado y **BTN3** recentra el IMU.

### [`tilt_maze/`](videogame/tilt_maze/) — Tilt Maze
Laberinto de bola que se controla **inclinando el PercuSynth**, como los juguetes de madera pero con 10 niveles curados (todos resolubles), vidas, portales, hoyos y zonas mortales.

---

## Samples (`samples/`)

Esta carpeta es una **biblioteca viva de firmwares generados por las webapps de `tools/`**. Cada subcarpeta tiene un `.ino` que ya viene con samples reales embebidos, listos para abrir en Arduino IDE y flashear como ejemplo de qué se puede armar:

- **`Industrial/` · `industrial_dos/`** — kits industriales (generados con `bpm_mono_44100`)
- **`percusynth_samples/` · `percusynth_samples2/`** — bancos propios (generados con `sample_loader`)
- **`percusynth_loop_player/`** — set dub/dance (generado con `loop_loader`)
- **`sonidos/`** — archivos de audio crudos (WAV) listos para alimentar las webapps

> Estos `.ino` son **artefactos generados**, no escritos a mano. Para hacer tus propios kits, abre la webapp correspondiente, carga tus audios y genera un nuevo `.ino`.

---

## Cómo cargar un firmware

### Opción A — Desde el navegador (sin Arduino IDE)

Sirve `tools/percu_control/` con un mini-servidor HTTP y abre la página en Chrome o Edge:

```bash
cd tools/percu_control
python -m http.server 8000
```

Luego abre <http://localhost:8000>, conecta el PercuSynth por USB y aprieta **⚡ FLASH FW**.

### Opción B — Desde Arduino IDE

1. Abrir el archivo `.ino` en **Arduino IDE**
2. Seleccionar placa: **ESP32S3 Dev Module** (o variante equivalente)
3. Configurar: **USB CDC On Boot: Enabled**, **Flash Mode: DIO** (crítico — OPI rompe I2S), **PSRAM: OPI PSRAM**
4. Compilar y cargar al microcontrolador
5. Monitor serie a **115200 baud** para diagnóstico

### Bibliotecas requeridas

- ESP32 Arduino core ≥ 3.x (incluye `driver/i2s_std.h`)
- `Wire.h` — I2C para el MPU6050 *(incluida en el core; la mayoría de los firmwares con IMU leen el sensor por registros crudos, sin librería extra)*
- `USB.h` / `USBMIDI.h` — MIDI USB *(incluidas en el core; MIDI_Drum, drum_midi_leds, trance_midi_leds, matrix_midi_anyma)*
- **FastLED** — la única librería que hay que instalar a mano. La usa todo firmware con LEDs: `test_leds`, `drum_ruido`, `drum_poder`, `drum_midi_leds`, `trance_imu_leds`, `pads_imu_leds`, `cancion_aleatoria_leds`, `paisajes_relax_leds`, `cyber_kit`, `oscilador_escalas`, `oscilador_escalas_clock`, `bajo_8_pasos`, `bajo_8_pasos_fsr_clock`, `industrial_matriz`, `la_partida`, `impact_chimes_leds`, `trance_midi_leds`, `matrix_midi_anyma` y los seis firmwares con IA
- Biblioteca `MPU6050` *(solo MIDI_Drum)*
- **ESP32Synth** *(sólo `secuenciador_melodico` y `secuenciador_melodico_cromatico`)*
- **Arduino AppleMIDI Library** de lathoub *(sólo `laser_midi_wifi`, que corre en un ESP32-C3)*

Los firmwares con IA piden además **PSRAM** (`sampler_ia`, `oscilador_ia`, `asistente_musical`,
`compositor_ia`) y un **micrófono INMP441** por I2S.

---

## Estructura del repositorio

```
percusynth/
├── firmwares/                      # Sketches Arduino escritos a mano
│   ├── drum_machine_basic/         #   Drum machine con secuenciador de pasos
│   ├── drum_ruido/                 #   Drum machine de timbres ruidosos, salida limpia
│   ├── drum_poder/                 #   Drum machine con peso + reloj MIDI por el DIN-5 (12 grooves, compases impares)
│   ├── synth_basico/               #   Sintetizador polifónico con morphing
│   ├── trance_imu/                 #   Secuenciador de trance polifónico (IMU→filtro)
│   ├── trance_imu_leds/            #   trance_imu + 6 LEDs SMD internos como visualizador
│   ├── pads_imu/                   #   Pads ambient sostenidos, sin secuenciador
│   ├── pads_imu_leds/              #   pads_imu + 6 LEDs SMD como visualizador
│   ├── cancion_aleatoria_leds/     #   Máquina de canciones aleatorias (Play = canción nueva)
│   ├── paisajes_relax_leds/        #   10 capas de paisaje sonoro + 2 anillos de LEDs
│   ├── cyber_kit/                  #   Secuenciador de texturas, FX y leads cyber
│   ├── oscilador_escalas/          #   4 pots = 4 osciladores por escala (port sin Mozzi)
│   ├── oscilador_escalas_clock/    #   oscilador_escalas + MIDI Clock por el DIN-5 + LEDs al ritmo de la intermitencia
│   ├── bajo_8_pasos/               #   Secuenciador de bajo en sierra de 8 pasos (pentatónica menor, 3 paneles) — hecho en el taller abierto de Hive
│   ├── bajo_8_pasos_fsr_clock/     #   bajo_8_pasos + FSR en EXT1 que abre el filtro + MIDI Clock por el DIN-5
│   ├── industrial_matriz/          #   Bombo + bajo con secuenciador industrial en paralelo + oscilador continuo + visuales en matriz 32×8
│   ├── secuenciador_melodico/      #   16 pasos monofónicos en modos griegos + webapp Web Serial (Nicolás Martínez)
│   ├── secuenciador_melodico_cromatico/ # 16 pasos polifónicos sobre 12 notas + webapp Web Serial (Nicolás Martínez)
│   ├── la_partida/                 #   "La partida" (Víctor Jara) desde sus 3 pistas MIDI: lead / bajo / pluck electrónico
│   ├── espacio_modular/            #   Ambientes de película: 24 temas sobre dron continuo
│   ├── impact_chimes/              #   Campanas por golpe en el piso (acelerómetro)
│   ├── impact_chimes_leds/         #   impact_chimes + 68 LEDs y 3 timbres (C lidio)
│   ├── laser_chimes/               #   Campanas al cortar un haz de láser (LDR en EXT1)
│   ├── grabador_campo/             #   Grabadora de campo a microSD: filtro/EQ/efectos en vivo + pista cruda
│   ├── voz_fx/                     #   Procesador de voz en tiempo real: micrófono INMP441 → 11 efectos → DAC
│   ├── mezclador_pistas/           #   4 pistas de una canción desde la microSD, volumen/filtro por pista + datos para Resonancia
│   ├── trance_pistas/              #   Trance sintetizado en 4 pistas (sin microSD), mismos bancos y datos para Resonancia
│   ├── oled_video_techno/          #   Video vertical en la OLED girada, amarrado al tempo + techno con bombo y filtro en los pots
│   ├── seismic_drone/              #   Drones graves por vibración de la tierra
│   ├── dub_siren/                  #   Dub siren (en desarrollo · PLAN.md)
│   ├── asistente_ia/               #   Asistente de voz (Whisper → GPT → TTS)
│   ├── asistente_naga/             #   El mismo asistente sobre NagaAI: una sola clave y modelos gratis
│   ├── asistente_musical/          #   Hablas con GPT sobre música que nunca se detiene
│   ├── sampler_ia/                 #   Pides un sample hablando (→ ElevenLabs) y lo disparas
│   ├── oscilador_ia/               #   El sample de IA es el oscilador (afinado por autocorrelación)
│   ├── compositor_ia/              #   Le pides una canción con la voz (GPT → JSON → motor)
│   ├── MIDI_Drum/                  #   Controlador MIDI (piezo + IMU + botones)
│   ├── drum_midi_leds/             #   Drum machine + MIDI + LEDs sincronizadas
│   ├── trance_midi_leds/           #   Trance melódico mono por MIDI + matriz 20×20
│   ├── laser_midi_wifi/            #   Nodo ESP32-C3 que manda MIDI por WiFi (RTP-MIDI): base para sensar clavas de malabarismo
│   ├── matrix_midi_anyma/          #   Máquina audiovisual electro + MIDI Clock Master (matriz 20×20)
│   ├── test_system/                #   Monitor de sistema: estado de todo por Serie + auto-tests
│   ├── test_leds/                  #   Test de tira LED WS2812 — 6 modos
│   ├── test_imu/                   #   Test del IMU por Monitor Serie
│   ├── test_imu_led/               #   Test del IMU sin USB → resultado en LEDs
│   └── test_imu_sound/             #   Test del IMU sin USB → resultado por sonido
├── tools/                          # Webapps standalone (Chrome/Edge)
│   ├── percu_control/              #   Panel universal + flasheo desde el navegador
│   ├── sample_loader/              #   Genera .ino con samples one-shot
│   ├── loop_loader/                #   Genera .ino con loops + hits
│   ├── step_sequencer_loader/      #   Genera .ino + control remoto vía Web MIDI
│   ├── dub_siren_generator/        #   Genera .ino dub siren con samples
│   ├── midi_sampler/               #   Sampler MIDI USB de 1 sample + 4 pots (Web Audio + genera .ino)
│   ├── arp_matrix/                 #   Arpegiador polifónico + matriz 64×32 (Web Audio + Serial)
│   ├── scale_osc/                  #   Motor de tono cuantizado a escala en el navegador
│   ├── generador_estilos/          #   Motor de estilos musicales por JSON (en desarrollo)
│   ├── video_synth/                #   Sintetizador audiovisual de video (Web Serial)
│   └── loops/
│       └── bpm_mono_44100/         #   Editor BPM-aware de loops sincronizados
├── videogame/
│   ├── cyber_flight/               # NEON STRIKE — shooter cyberpunk (Web Serial)
│   ├── nebula_gp/                  # NEBULA GP — carreras FPV de drones contra 4 bots
│   └── tilt_maze/                  # Tilt Maze — laberinto de bola por inclinación del IMU
├── samples/                        # Firmwares generados por las webapps (ejemplos vivos)
├── Hardware/                       # Esquemático, PCB y gerbers del circuito + base 3D + lista de compra
├── Imagenes/                       # Renders 3D y diagrama de pinout
├── Documentos/                     # Informe técnico (PDF)
├── PROMPT_PARA_LA_IA.md            # Documento de contexto para IA (+ versión .pdf)
└── Percu-Synth.mp4                 # Video del proyecto
```

¿Dónde está el detalle de cada uno? La mayoría de las subcarpetas de `firmwares/` y `tools/` traen
su propio `README.md` (o un `PLAN.md`, si todavía es un diseño). Los sketches más directos
—`drum_machine_basic`, `synth_basico`, `MIDI_Drum`, `drum_midi_leds`, `trance_midi_leds` y los
`test_*`— se documentan en el **encabezado del propio `.ino`**: ahí está el hardware, los ajustes
del IDE, las librerías y el funcionamiento.

---

## Usar el repositorio con IA

El PercuSynth está pensado para que puedas inventarle firmwares nuevos apoyándote en un asistente
de IA. Hay tres niveles, de menos a más:

1. **Sube la imagen del pinout** ([`Imagenes/percu-synth pinout.jpeg`](Imagenes/)) a cualquier
   asistente (Claude, ChatGPT, Gemini) para que entienda el hardware.
2. **Pásale [`PROMPT_PARA_LA_IA.md`](PROMPT_PARA_LA_IA.md)** ([PDF](PROMPT_PARA_LA_IA.pdf)) — el
   documento madre con el pinout, los ajustes del Arduino IDE, las librerías, las constantes de
   audio y los patrones de código listos para copiar. Con esto la IA genera firmware que compila
   a la primera mucho más seguido.
3. **Usa el repo como skill de Claude Code.** El repositorio incluye
   [`.claude/skills/percusynth/SKILL.md`](.claude/skills/percusynth/SKILL.md): clona el repo, abre
   Claude Code dentro y la skill se carga sola. Además del pinout, le enseña las convenciones del
   proyecto, las reglas de diseño de controles que salieron de los talleres y el checklist de
   calidad de audio.

```bash
git clone https://github.com/GC-Lab-Gonzalo/Percu-Synth.git
```

---

## Proyecto hermano

Este laboratorio es parte del mismo ecosistema que el **[Proto-Synth v2](https://github.com/GC-Lab-Gonzalo/proto-synth-v2)**, otra plataforma de experimentación de GC Lab Chile, con hardware diferente y una colección más amplia de firmwares de ejemplo.

---

Desarrollado por **GC Lab Chile** — electrónica, arte y tecnología abierta.

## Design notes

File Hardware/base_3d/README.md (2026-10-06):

# Base imprimible para la PercuSynth V2.0

Reemplazo en plástico del marco de madera, pensado para quien arma el PercuSynth
fuera de Chile. Es un marco de pared ancha, con las esquinas y el canto superior
redondeados. Va abierto por debajo y sin travesaños, con seis postes donde se
atornilla la placa.

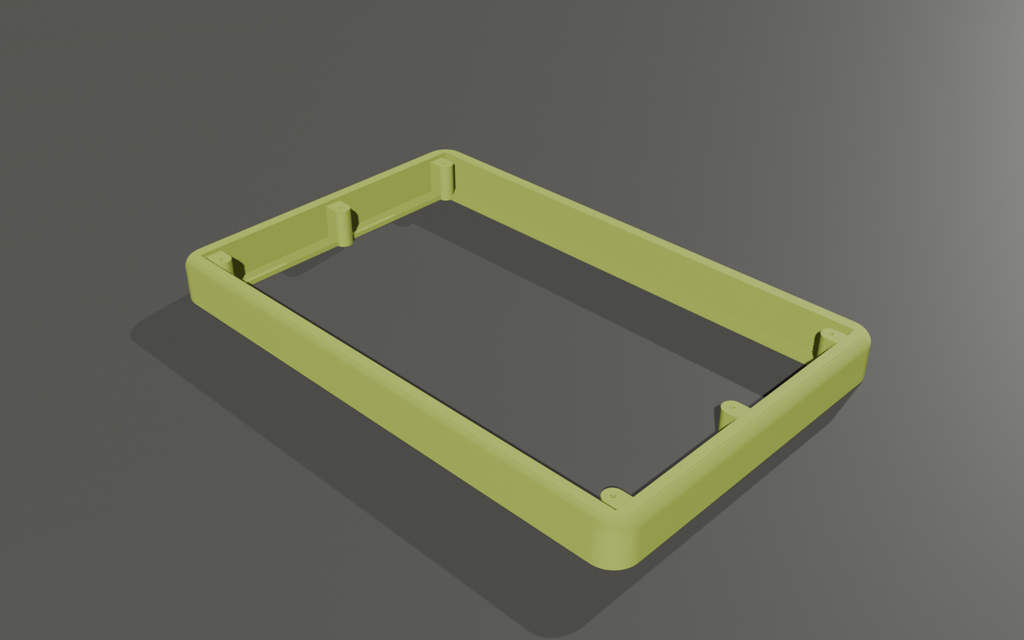
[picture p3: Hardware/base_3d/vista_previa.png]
Vista previa


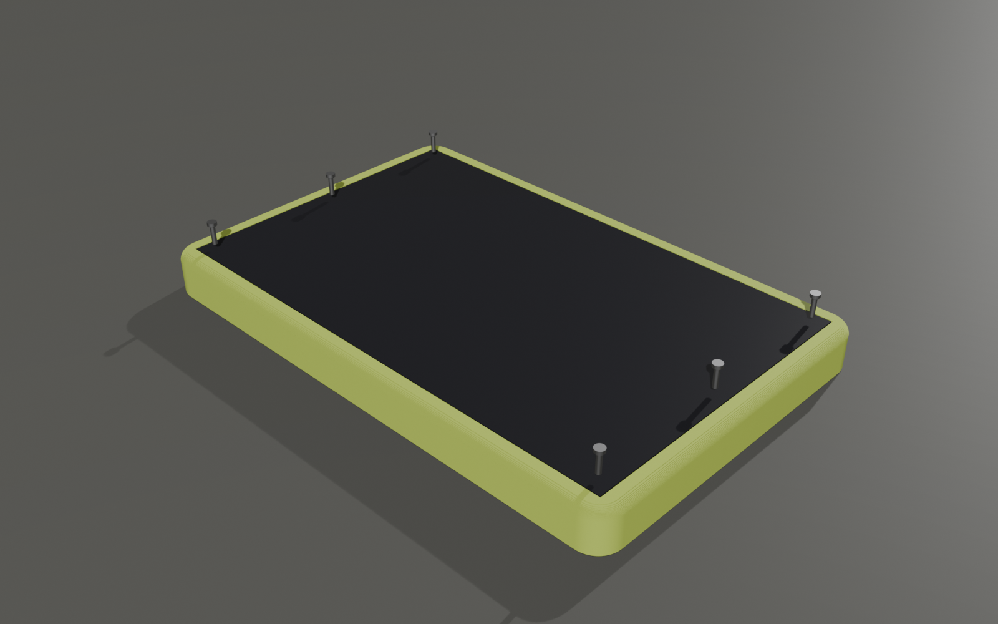
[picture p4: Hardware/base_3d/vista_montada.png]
Con la placa montada


## Archivos

| Archivo | Para qué |
|---|---|
| `base_percusynth_v2.stl` | Listo para el slicer |
| `base_percusynth_v2.3mf` | Lo mismo, en 3MF (Bambu Studio / PrusaSlicer / Cura) |
| `generar_base.py` | La fuente: todas las medidas son parámetros al inicio del archivo |

## Medidas

- Exterior: **215,8 × 139,2 × 17,6 mm**. Necesita una cama de **220 × 220 mm** o más.
- Pared de 7 mm. Esquinas con radio de 10 mm y canto superior con radio de 4 mm.
- Material: 93 cm³ si se imprimiera maciza. Con 15–20 % de relleno, el slicer da bastante menos.
- Placa: 201,0 × 124,4 × 1,6 mm, sacada del contorno de los gerbers V2.0.

## Imprimir

- **Posición:** tal como viene, con la cara plana sobre la cama. No necesita soportes.
- **Material:** PLA o PETG.
- **Capa:** 0,2 mm.
- **Relleno:** 15–20 %. Casi todo son paredes, así que el relleno influye poco.
- **Perímetros:** 3 o más, para que los postes queden sólidos alrededor del tornillo.

## Montar

1. Coloca la placa encima de manera que los seis agujeros coincidan con los postes.
2. Atornilla la placa con **6 tornillos autorroscantes M2 × 6 mm**. Con M2 × 8 también sirve: el agujero guía mide 1,7 mm y es ciego, así que la punta no sale por abajo.

La pared llega exactamente al ras de la cara superior de la PCB, a propósito. Los jacks, el USB-C, el MIDI, la salida del DAC y las borneras enchufan desde el borde de la placa, y una pared más alta los taparía.

Bajo la placa quedan 16 mm de aire. Ahí van los 6 LEDs WS2812, montados por la cara inferior, y las patas de los componentes.

## Ajustar

Todo se cambia en `generar_base.py`:

| Parámetro | Valor | Qué controla |
|---|---|---|
| `PARED` | 7 mm | Grosor de la pared. |
| `RADIO_ESQUINA` / `RADIO_CANTO` | 10 / 4 mm | Redondeo de las esquinas y del canto superior. |
| `HOLGURA` | 0,4 mm | Juego por lado entre la placa y la pared. Súbelo si la placa entra muy apretada. |
| `PILOTO_D` | 1,7 mm | Agujero guía del tornillo. Usa 3,2 mm si vas a poner insertos térmicos M2. |
| `AIRE` | 16 mm | Distancia de la mesa a la cara inferior de la placa. |
| `BORDE` | 0 mm | Cuánto sube la pared por encima de la placa. Sobre 1 mm empieza a estorbar a los plugs. |

Para volver a generar el modelo:

```bash
pip install manifold3d trimesh numpy
python generar_base.py
```

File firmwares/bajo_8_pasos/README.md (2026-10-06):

# bajo_8_pasos — Secuenciador de bajo de 8 pasos (sierra, pentatónica menor)

Secuenciador de **8 pasos** que toca un **bajo monofónico lleno de armónicos**: dos
sierras PolyBLEP desafinadas + una cuadrada una octava abajo, saturación suave y un
filtro pasa-bajos resonante con **envolvente de filtro** (cada nota abre el filtro y
se cierra con el decay). Todas las notas caen en **La pentatónica menor**.

Creado en conjunto con los participantes del **taller abierto de GC Lab en Hive Espacios**.

## Controles

| Control | Qué hace |
|---|---|
| **BTN1** | **Play / Stop**. Play arranca siempre desde el paso 1 y suena en el acto |
| **BTN2** | **Panel A** — POT1..POT4 = nota de los pasos **1..4** |
| **BTN3** | **Panel B** — POT1..POT4 = nota de los pasos **5..8** |
| **BTN4** | **Panel C** — POT1 **volumen** · POT2 **velocidad** · POT3 **decay** · POT4 **cutoff** |
| **BTN5** | **Octava** siguiente (ciclo de 3: La1 · La2 · La3). Cambia también la nota que está sonando |

- **Notas:** cada pot recorre 11 notas de la pentatónica menor (La · Do · Re · Mi · Sol,
  dos octavas más la tónica de arriba). Con el pot **al mínimo** (< 3 %) el paso queda
  **en silencio**.
- **Velocidad:** 60–200 BPM, cada paso es una semicorchea. Arranca en 120.
- **Decay:** 30 ms – 1.2 s. El filtro se cierra un poco antes que el volumen.
- **Cutoff:** 50 Hz – 6 kHz. La resonancia va atada al corte (más resonante abajo).

### Cómo se comportan los pots al cambiar de panel

Al entrar a un panel, **ningún pot cambia nada hasta que lo muevas** (unos 5 % de
recorrido). Desde ese momento la posición física del pot es el valor. Así saltar de
panel A a B o C nunca pisa las notas que ya dejaste en el otro panel.

## LEDs

| LED | Muestra |
|---|---|
| 0–3 | Panel A/B: los 4 pasos del panel (color = nota, apagado = silencio, **blanco = paso sonando**) · Panel C: nivel de cada parámetro |
| 4 | Panel activo: A cian · B violeta · C naranjo |
| 5 | Octava (brillo) + pulso en cada paso mientras suena (fuerte en los pasos 1 y 5). Rojo tenue = detenido |

## Tira externa de 121 LEDs — balas de luz

La tira WS2812 va **encadenada después de los 6 LEDs SMD de la placa, en el mismo pin
(GPIO 46)**: índices 6..126. Aliméntala con 5 V propios y GND común con la placa
(el firmware limita el consumo a 2 A con `LED_MAX_MA`).

- **Cada paso que suena dispara una bala** desde el inicio de la tira que avanza hacia
  el final con una estela que se apaga. Un paso en silencio no dispara.
- **Multicolor:** cada paso tiene su color (arcoíris de 8) y la nota lo corre un poco,
  así que al cambiar notas cambian los colores. La punta sale casi blanca.
- Los **pasos 1 y 5** salen más brillantes y con estela más larga (marcan el compás).
- **La velocidad sigue al tempo:** siempre quedan 15 LEDs entre bala y bala
  (`ESPACIO_BALAS`), o sea la secuencia entera de 8 pasos cabe volando en la tira.
- Movimiento con sub-píxel a ~60 fps, en la tarea de control (core 0): no le quita
  tiempo al audio.

Se ajusta en el `.ino`: `TIRA_LEDS`, `ESPACIO_BALAS`, `HUE_PASO[]` (colores por paso),
`LED_MAX_MA`.

## Cadena de audio

`sierra + sierra (+9 cents) + cuadrada −1 oct → saturación suave → SVF pasa-bajos
(cutoff pot × envolvente de filtro, Q atado al corte) → VCA (ataque 2 ms + decay) →
bloqueador de continua → volumen → limitador suave`

El timbre que no está en un pot vive en el bloque **TIMBRE (fijo)** del `.ino`:
desafinación, nivel de la sub, drive, cuánto abre la envolvente de filtro
(`ENV_FILTRO_OCT`), rango de resonancia.

## Notas de implementación

- **Dos núcleos**: audio en su tarea fijada al core 1, botones/pots/LEDs en el core 0
  a 1 kHz. El control sólo deja pedidos (notas, parámetros, play) que el audio lee en
  el borde del buffer o al disparar cada paso. Sin `Serial`.
- **Secuenciador preciso a la muestra**, y el largo de cada paso se fija al empezarlo:
  girar la velocidad a mitad de un paso no dispara notas de más.
- **Sin clics al encadenar notas**: la fase de los osciladores no se reinicia y el
  ataque sube desde donde esté la envolvente. Paso en silencio y Stop cierran la nota
  con un tau de 25 ms.
- **Filtro SVF (TPT de Zavalishin)**: estable aunque la envolvente mueva el corte muy
  rápido; los coeficientes se recalculan cada 8 muestras.
- DMA corto (4 × 128 ≈ 12 ms) para que Play responda al instante.
- Verificado en simulación en PC: 32 pasos en 4 s a 120 BPM, 53 a 200 BPM, sin NaN ni
  saturación (pico máx. −2.6 dBFS con todo al máximo).

## Hardware

- ESP32-S3 + DAC **PCM5102** vía I2S (`LCK 39 · DIN 40 · BCK 41`)
- **6 LEDs WS2812** internos (`DATA 46`) + **tira WS2812 de 121 LEDs** encadenada después (mismo pin)
- 5 botones con pull-up (`44 · 42 · 0 · 45 · 47`) · 4 potenciómetros (`ADC 1 · 2 · 8 · 10`)

## Compilar y flashear (Arduino IDE)

- Board: **ESP32S3 Dev Module**
- USB CDC On Boot: **Enabled**
- **Flash Mode: DIO** (¡OPI rompe el I2S!)
- Librerías: **FastLED** (el driver I2S viene en el core ESP32 ≥ 3.x)

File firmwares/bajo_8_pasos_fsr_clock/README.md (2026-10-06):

# bajo_8_pasos_fsr_clock — Bajo de 8 pasos + FSR al filtro + reloj MIDI

Es **`bajo_8_pasos` con dos cosas encima, y nada más**: un **FSR (sensor de presión) en
EXT1 que abre el filtro** y un **MIDI Clock por el DIN-5**. El motor de sonido, los
controles, los paneles y las balas de luz de la tira son idénticos al original — con el
FSR suelto suena exactamente igual.

## Lo nuevo

### FSR → filtro (EXT1, GPIO 3)

Aprieta y el filtro se abre: hasta **3 octavas (`FSR_OCT`) por encima de donde dejaste el
POT4**. El pot sigue poniendo el punto de reposo y la resonancia, como siempre; el FSR es
una expresión en vivo encima, igual que el IMU en `espacio_modular`. Suelto no hace nada
(hay una zona muerta del 6 % que se come el ruido del ADC), así que **el sonido de reposo
es el del `bajo_8_pasos` original**.

Si lo prefieres al revés — que el FSR **sea** todo el cutoff y el POT4 deje de hacer
nada — pon `FSR_REEMPLAZA_POT` en 1 y vuelve a flashear.

Se muestrea a **1 kHz en la tarea de control (core 0)**, una lectura cruda por pasada: el
promediado lo hace el filtro de un polo (`FSR_SUAVIZADO`), que además es lo que evita que
el ruido del ADC se oiga como un temblor. En el audio entra por un suavizado más, por
muestra, así que un golpe de presión no produce escalones.

**El brillo del LED 4 sigue al FSR**, o sea que se ve si el sensor responde sin abrir el
monitor serie.

#### Cableado

Divisor de tensión con una resistencia de **10 kΩ**. Las dos formas sirven:

```
3.3V ── FSR ──┬── EXT1 (GPIO 3)        apretado = lectura ALTA
             10 kΩ
              │
             GND

3.3V ── 10 kΩ ──┬── EXT1 (GPIO 3)      apretado = lectura BAJA
                FSR
                 │
                GND
```

**La polaridad no importa**: el mapeo es una recta entre las dos lecturas medidas
(`FSR_SUELTO` y `FSR_APRETADO`), así que si te queda al revés basta con que `FSR_SUELTO`
sea el número más grande.

#### Calibrar (una vez, al armarlo)

1. Pon `MOSTRAR_ESTADO` en **1** y flashea. Monitor serie a **115200**.
2. Con el FSR **suelto**, mira `raw` → ese número va en `FSR_SUELTO`.
3. **Apriétalo lo que lo vayas a apretar tocando**, mira `raw` → va en `FSR_APRETADO`.
4. Vuelve `MOSTRAR_ESTADO` a **0** y flashea de nuevo.

El punto 4 no es opcional: un print por USB CDC **bloquea el core que lo hace** hasta que
el PC lea, y eso vacía el DMA del audio — se oye como un clic. En 0 no se compila ni una
línea de `Serial`.

### Reloj MIDI por el DIN-5 (GPIO 43)

**Sólo reloj, nunca notas**: MIDI Clock a **24 PPQN** al tempo del secuenciador (POT2 del
panel C), **Start** al dar Play y **Stop** al parar. Como cada paso es una semicorchea,
van **6 ticks por paso** y 24 por negra.

- El **"1" del Start cae en el paso 1**: al dar Play se descartan los ticks anteriores y
  el Start sale justo antes del tick del "1", así la secuencia del sinte externo no queda
  corrida contra el bajo.
- **Los ticks salen siempre, aun parado**, para que el sinte ya tenga el tempo cuando
  llegue el Start y no arranque buscando el pulso.
- El reloj se **cuenta en la tarea de audio con el mismo contador de muestras que los
  pasos** (acumulador entero: no hay dos relojes, hay uno) pero se **manda desde la tarea
  de control a 1 kHz**. Mandarlo desde el render le metería al clock los ±2,9 ms de
  fluctuación del buffer, que a 120 BPM es un 14 % de un tick y se oye como un arpegio
  que se tambalea.
- `ENVIAR_MIDI_CLOCK` en `false` lo apaga, por si tu sinte se vuelve loco con clock
  entrante.

El MIDI sale por **`Serial1` enrutado al GPIO 43**, no por `Serial0`: `Serial0` comparte
ese TX con el DIN-5 y su RX cae en el GPIO 44, que acá es el BTN1. Por eso los prints de
calibración van sólo por el **USB CDC** (`Serial`).

## Controles

| Control | Qué hace |
|---|---|
| **BTN1** | **Play / Stop**. Play arranca desde el paso 1 y manda **MIDI Start**; Stop manda **MIDI Stop** |
| **BTN2** | **Panel A** — POT1..POT4 = nota de los pasos **1..4** |
| **BTN3** | **Panel B** — POT1..POT4 = nota de los pasos **5..8** |
| **BTN4** | **Panel C** — POT1 **volumen** · POT2 **velocidad** · POT3 **decay** · POT4 **cutoff** |
| **BTN5** | **Octava** siguiente (ciclo de 3: La1 · La2 · La3). Cambia también la nota que está sonando |
| **FSR** | **Abre el filtro** por encima del POT4 (hasta 3 octavas) |

- **Notas:** cada pot recorre 11 notas de la pentatónica menor (La · Do · Re · Mi · Sol,
  dos octavas más la tónica de arriba). Con el pot **al mínimo** (< 3 %) el paso queda
  **en silencio**.
- **Velocidad:** 60–200 BPM, cada paso es una semicorchea. Arranca en 120. **Es también
  el tempo del MIDI Clock.**
- **Decay:** 30 ms – 1.2 s. El filtro se cierra un poco antes que el volumen.
- **Cutoff:** 50 Hz – 6 kHz (reposo). La resonancia va atada al corte.
- Al entrar a un panel, **ningún pot cambia nada hasta que lo muevas** (unos 5 %).

## LEDs

| LED | Muestra |
|---|---|
| 0–3 | Panel A/B: los 4 pasos del panel (color = nota, apagado = silencio, **blanco = paso sonando**) · Panel C: nivel de cada parámetro |
| 4 | Panel activo: A cian · B violeta · C naranjo — **el brillo sigue al FSR** |
| 5 | Octava (brillo) + pulso en cada paso mientras suena (fuerte en los pasos 1 y 5). Rojo tenue = detenido |

## Tira externa de 121 LEDs — 8 efectos que se sortean solos

La tira va **encadenada después de los 6 LEDs SMD de la placa, en el mismo pin (GPIO 46)**:
índices 6..126.

| Efecto | Qué hace |
|---|---|
| **BALAS** | Un proyectil con estela por cada paso, volando al tempo (el de `bajo_8_pasos`) |
| **ONDAS** | Anillos que se abren hacia los dos lados desde un punto al azar |
| **VU** | Barra que crece desde el centro con la envolvente, con punta blanca en el golpe |
| **CHISPAS** | Puñados de píxeles que se encienden en el golpe y se apagan solos |
| **ARCOÍRIS** | El espectro entero corriendo al tempo |
| **PLASMA** | Campo de ruido que respira |
| **BANDAS** | La tira partida en 8 bloques, uno por paso, en orden barajado |
| **SERPIENTE** | Una cabeza blanca que va y vuelve al tempo, con su cola |

**Se sortean solos**: uno nuevo cada **4 compases** y en cada **Play**, y nunca sale el que
estaba sonando. Con el efecto se sortean su paleta, su dirección y un parámetro propio, así
que el mismo efecto **no se ve igual dos veces**. No hay botón para cambiarlo — los cinco ya
tienen su función y acá no se inventan combos.

**Los ocho son reactivos a lo mismo**, así que da igual cuál salga:

- el **golpe** de cada paso (más fuerte en los pasos 1 y 5, que marcan el compás),
- la **nota** que suena, que define el color,
- la **envolvente real del bajo** — la tarea de audio publica su envolvente en `g_env` una
  vez por buffer, así que la tira sigue al sonido de verdad y no a una imitación calculada
  aparte en el core 0,
- la **presión del FSR**, que deforma el efecto en vivo (alarga estelas y colas, ensancha
  anillos y bloques, comprime el arcoíris, calienta y acelera el plasma, llena de polvo las
  chispas),
- y el **tempo**, que fija cuántos LEDs se recorren por paso (`LEDS_POR_PASO`, 15: los
  8 pasos caben justo en la tira).

Un paso en silencio no dispara nada. Todo el dibujo corre en la **tarea de control (core 0)**
a ~60 fps con movimiento sub-píxel; el audio no se entera.

Se ajusta en el `.ino`: `TIRA_LEDS`, `LEDS_POR_PASO`, `PASOS_POR_SORTEO`, `HUE_PASO[]`.

### Alimentación y el limitador de corriente — léelo antes de subir el brillo

**Si la tira cuelga del 5 V de la placa (o del USB), un efecto que prende los 121 LEDs a la
vez pide del orden de 2 A, el riel se hunde y se corta el audio.** Las balas nunca lo
provocaban porque encienden ~50 LEDs con una estela que se apaga; ARCOÍRIS y PLASMA
encienden los 121 siempre, y BANDAS también cuando aprietas el FSR.

Ojo con el diagnóstico, porque se parece al otro: **esto no es el problema de tiempo** que
hay documentado en `drum_poder` y `la_partida`. Los ocho efectos juntos no llegan a 0,5 ms
de los 16 que hay entre frames, y el audio corre en el otro núcleo. Es eléctrico.

Por eso la tira tiene **su propio limitador**, que mide lo que el frame va a consumir y lo
baja si se pasa. Está escrito como un limitador de audio y por el mismo motivo: **baja al
instante** (pasarse aunque sea un frame ya es el bajón) y **sube despacio**, porque un
escalón de corriente hacia arriba es justo lo que hace caer el riel. No toca los 6 LEDs de
estado.

| Constante | Para qué |
|---|---|
| `TIRA_MAX_MA` | **El número a tocar.** 300 mA por defecto, pensado para un puerto USB de 500 mA con la placa consumiendo ~150 |
| `LED_MAX_MA` | Tope duro de FastLED (600 mA), como red de seguridad |

**Si le pones fuente propia a la tira** (5 V, 2 A o más, GND común con la placa), sube
`TIRA_MAX_MA` a 1500 y `LED_MAX_MA` a 2000 y los efectos vuelven a brillo completo. Y aunque
tenga fuente propia, conviene un **condensador de 1000 µF** en la entrada de la tira: lo que
hunde el riel no es la corriente alta, es el **escalón** de corriente.

Consecuencia de tener el limitador puesto: con poco presupuesto, apretar el FSR ya no hace
que la tira brille *más* — **redistribuye** la luz (colas más largas, bloques que desbordan,
el arcoíris que se comprime) manteniendo la energía total. Con fuente propia vuelve a ser
las dos cosas.

## Cadena de audio

`sierra + sierra (+9 cents) + cuadrada −1 oct → saturación suave → SVF pasa-bajos
(cutoff pot × envolvente de filtro × FSR, Q atado al corte) → VCA (ataque 2 ms + decay) →
bloqueador de continua → volumen → limitador suave`

El FSR viaja en **el mismo exponente** que la envolvente de filtro, así que no cuesta ni
un `powf` extra (y `powf` en el S3 se paga caro — ver la lección de `la_partida`).

## Verificado

Compila para ESP32-S3 (30 % de flash, 6 % de RAM) con `MOSTRAR_ESTADO` en 0 y en 1, y
corrido en simulación en el PC contra mocks de `Arduino.h` / `i2s_std.h` / `FastLED.h`:

- **Reloj al tempo**: 24,00 tick/s a 60 BPM, 48,10 a 120,2, 80,01 a 200 → error **< 0,06 %**.
- **Cero deriva**: 60 s tocando a 60 / 120 / 200 BPM → **6,000 ticks por paso** (esperado 6).
- **Transporte**: Start al Play sin ningún clock antes del "1", el primer tick tras el
  Start es el paso 1, un solo Stop al parar, y los ticks siguen saliendo detenido.
- **FSR**: apertura monótona del filtro con la presión (×2,3 de agudos de suelto a fondo),
  **0 muestras saturadas** y 0 NaN en los 11 puntos del barrido y en 40 golpes bruscos de
  0 % a 100 % con el secuenciador tocando; pico máximo −7,9 dBFS.
- **FSR suelto = original**: la aportación al filtro es exactamente 0, y un 4 % de
  presión (zona muerta) tampoco mueve nada.
- **Tira**: los 8 efectos encienden la tira (de 53 a 121 píxeles de media según el efecto)
  y **ninguno apaga los 6 LEDs de estado** de la placa; el sorteo **nunca repite** el efecto
  anterior y en 4000 tiradas salieron los 8; `faseFx` nunca queda en NaN.
- **Reactividad al FSR de los 8**, medida como cambio de brillo total y de "dibujo" (la
  suma de diferencias entre píxeles vecinos, que es lo que se mueve cuando el efecto se
  comprime o se corre de color en vez de encenderse más). Hacen falta las dos medidas: el
  ARCOÍRIS y el PLASMA responden a energía casi constante y, midiendo sólo brillo, parecían
  muertos sin estarlo — y con el limitador de corriente puesto eso pasa a ser lo normal,
  porque la energía total queda acotada.
- **Presupuesto de corriente**: con el FSR a fondo, ningún frame de ninguno de los 8 efectos
  pasa de los 300 mA (picos de 286 a 297 mA, medias de 185 a 282), y al soltar un efecto
  caro la corriente sube como mucho 70 mA entre frame y frame en vez de dar un escalón.

## Hardware

- ESP32-S3 + DAC **PCM5102** vía I2S (`LCK 39 · DIN 40 · BCK 41`)
- **6 LEDs WS2812** internos (`DATA 46`) + **tira WS2812 de 121 LEDs** encadenada después (mismo pin)
- 5 botones con pull-up (`44 · 42 · 0 · 45 · 47`) · 4 potenciómetros (`ADC 1 · 2 · 8 · 10`)
- **FSR + 10 kΩ** en el sensor externo A (`EXT1 → GPIO 3`)
- **MIDI DIN-5** (`TX → 43`, 31250 baud)

## Compilar y flashear (Arduino IDE)

- Board: **ESP32S3 Dev Module**
- USB CDC On Boot: **Enabled**
- **Flash Mode: DIO** (¡OPI rompe el I2S!)
- Librerías: **FastLED** (el driver I2S viene en el core ESP32 ≥ 3.x)

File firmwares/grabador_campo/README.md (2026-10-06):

# grabador_campo — grabadora de campo con efectos en las perillas

El micrófono INMP441 pasa por ganancia, filtro, ecualizador y un efecto, todo en tiempo real, y
se graba a una **microSD**. Lo que oyes en los audífonos es exactamente lo que se graba. Pensado
para salir a terreno (un cerro, un río, un bosque), filmar la placa con el teléfono y que en el
video se vea mover una perilla y cambiar el ambiente.

Cada toma deja **dos archivos que empiezan en la misma muestra**:

| Archivo | Qué es |
|---|---|
| `CAMPO_0001.WAV` | El sonido **procesado**: estéreo, 24 bit / 44.1 kHz |
| `CAMPO_0001_CRUDO.WAV` | El micrófono: mono, 24 bit / 44.1 kHz, sin ganancia, efectos ni limitador; sólo pasa por el techo de agudos de 15.5 kHz (`FILTRAR_CRUDO 0` lo deja intacto). Es la calidad real del micrófono, y te deja reprocesar la toma si el efecto no quedó como querías |

En el editor se ponen uno encima del otro y calzan muestra a muestra. Para sincronizar con el
video: **un aplauso frente al micrófono al empezar**. La numeración sigue la que ya haya en la
tarjeta.

## Controles

| Control | Qué hace |
|---|---|
| BTN1 | **Grabar / parar** |
| BTN2 | **Efecto** siguiente: NATURAL → ECO → CATEDRAL → CHORUS → FLANGER → PHASER. El sonido directo nunca se corta al cambiar |
| BTN3 | **Congelar** on/off: toma los últimos ~3 s del ambiente y los sostiene como una nube continua. El filtro, el EQ y el efecto siguen actuando sobre ella |
| BTN4, BTN5 | Libres |
| POT1 | **Ganancia** +6 … +60 dB |
| POT2 | **Filtro**. Centro = abierto · izquierda pasa-bajos (20 kHz → 120 Hz) · derecha pasa-altos (20 Hz → 5 kHz) |
| POT3 | **Color** (EQ de inclinación). Centro = plano · izquierda cálido · derecha brillante (±8/10 dB) |
| POT4 | **Cantidad** del efecto. ECO: nivel y repeticiones · CATEDRAL: mezcla y tamaño · CHORUS: mezcla · FLANGER: mezcla y realimentación (de suave a metálico) · PHASER: profundidad de las muescas y realimentación |

| LED | Significado |
|---|---|
| 0 | verde tenue = lista · **rojo parpadeando = grabando** · naranjo = se perdió audio (la tarjeta no alcanzó) · amarillo rápido = cerrando, no apagues · magenta = sin tarjeta o error |
| 1 | efecto: blanco NATURAL · celeste ECO · azul CATEDRAL · verde CHORUS · violeta FLANGER · ámbar PHASER |
| 2 | cian = congelado |
| 3–5 | nivel de entrada: verde > −40 dBFS · amarillo > −18 · rojo > −3 (baja el POT1) |

## Conexión de la microSD

| Módulo | ESP32-S3 |
|---|---|
| SCK | GPIO 14 |
| MOSI | GPIO 15 |
| MISO | GPIO 16 |
| CS | GPIO 17 |
| VCC | 5 V (módulo azul con regulador) o 3.3 V (módulo sin regulador) |
| GND | GND |

Tarjeta **FAT32** (hasta 32 GB viene así; una de 64 GB hay que formatearla FAT32). Clase 10 / A1
o mejor. Cada hora de grabación ocupa ~1.4 GB (procesado 24 bit + crudo). Los pines están en
`#define SD_*` al inicio del `.ino`.

El micrófono va en WS 11 · SCK 12 · SD 13 (el mismo cableado que `voz_fx`).

## En terreno

- **Viento**: el INMP441 es diminuto y cualquier brisa lo satura. Una espuma como mínimo; una
  "peluda" (dead cat) de verdad. El pasa-altos fijo de 30 Hz del procesado ayuda, pero no salva
  una toma soplada (y el crudo no lo lleva).
- **Ruido de las perillas**: si el micrófono va soldado en la misma placa que los pots, el roce
  al girarlos se graba. Sácalo con un cable de 20–30 cm.
- **Ruido propio**: el INMP441 tiene 61 dB de relación señal/ruido. En un lugar muy callado su
  soplido se oye. Es un límite del micrófono, no del grabador: el crudo lo muestra tal cual.
- **Energía**: un power bank por USB. Sin tira de LEDs la placa consume poco.
- **Batería o tarjeta que se cae a mitad de toma**: las cabeceras de los WAV se reescriben cada
  5 s, así que el archivo se abre igual y se pierden a lo más los últimos segundos.

## Decisiones

- **El micro corre a 44.1 kHz con la misma fuente de reloj que el DAC** (como en `voz_fx`): no
  derivan y no hay que remuestrear.
- **La tarjeta nunca toca el audio.** El audio (core 1) deja cada bloque en un colchón de **8 s en
  PSRAM**, y una tarea del core 0 lo vacía a la tarjeta en escrituras de ~24 KB. Una microSD a
  veces se toma 100–300 ms en una escritura; con el colchón eso no se oye ni se pierde. Si la
  tarjeta se traba más de 8 s, se pierden bloques enteros (los dos archivos igual, así siguen
  alineados) y el LED 0 se pone naranjo.
- **Al cambiar de efecto sólo entra y sale la parte húmeda** (fundido de 20 ms): el ambiente
  directo nunca se corta, así que en la grabación no hay huecos.
- **El eco tiene tiempo fijo** (420 ms, `ECO_MS`): moverlo con un pot desafina las repeticiones.
  Es ping-pong: las repeticiones alternan izquierda y derecha.
- **Modulaciones con velocidad fija** (`CHORUS_HZ` 0.35, `FLANGER_HZ` 0.12, `PHASER_HZ` 0.20): un
  pot, una función, y el POT4 ya es la cantidad. Las tres son estéreo:
  - **CHORUS**: tres copias con retardo que se mece (13/17/23 ms ± 2.2 ms), a velocidades que no
    se alinean nunca (×1, ×1.31, ×0.77); una a cada lado y la tercera al centro.
  - **FLANGER**: peine con realimentación de 0.8 a 7 ms, izquierda y derecha en cuadratura (el
    barrido gira en el estéreo). Saturación suave dentro del lazo y el nivel compensado por la
    realimentación.
  - **PHASER**: 6 pasa-todo de 1er orden por canal barridos entre 200 Hz y 3 kHz. El coeficiente
    se calcula al borde del bloque y se interpola por muestra: un `tanf` por muestra y canal sería
    caro en el S3. Mezcla 0.5·(directo + pasa-todo), así con POT4 al máximo las muescas son
    completas y los picos quedan en 0 dB.
  - El shimmer (reverb con octava arriba) se probó y se sacó.
- **Congelar** son 6 granos Hann de 350 ms desfasados, que leen posiciones al azar de los últimos
  ~3 s, con un fundido de igual potencia de 250 ms. Un grano nunca cruza el punto donde el
  anillo junta lo más nuevo con lo más viejo (sería un salto).
- **Techo de agudos en 15.5 kHz** (Butterworth de 8º orden, 4 biquads: plano hasta 14 kHz, −7 dB
  en 16, −37 dB en 18). La primera versión no tenía techo, para no cortarle agudos a los pájaros,
  y en las tomas apareció un soplido fino: medido, el piso de ruido del INMP441 sube 4–7 dB entre
  16 y 20 kHz, justo donde el micro ya no capta nada útil. `voz_fx` no lo tenía porque su
  pasa-bajos de 13 kHz se lo comía. Va ANTES del limitador: un Butterworth de 8º orden rebota un
  poco en los picos, y puesto después llegaba a tope sin que nadie lo atajara (medido en
  simulación). También va sobre el crudo (`FILTRAR_CRUDO`). Limitador con lookahead a −1 dBFS.
- Ajustes en constantes al inicio del `.ino`: `BITS_PROCESADO` (24, o 16 si la tarjeta no da
  abasto), `GRABAR_CRUDO`, `GANANCIA_MIN_DB`/`GANANCIA_MAX_DB`, `ECO_MS`, `CHORUS_HZ`, `FLANGER_HZ`, `PHASER_HZ`.

## Verificado en simulación

Compilado en el PC con un ambiente sintético (ruido rosa a −62 dBFS, pájaros, un aplauso, 5 s de
viento) y un guion de 85 s que recorre los efectos, congela mientras barre el filtro y
después cambia efecto, congelar y los cuatro pots a la vez cada 0.7 s:

- 0 NaN, 0 muestras en tope con ganancias normales; pico 0.93 con el limitador a 0.89.
- Los cinco efectos al máximo con ruido fuerte y después silencio: todos se apagan solos.
- Nivel de cada efecto con POT4 al máximo, contra NATURAL: todos dentro de ±3 dB (el eco un poco
  más fuerte, porque suma repeticiones), así cambiar de efecto no pega saltos de volumen.
- La tarjeta trabándose 400 ms cada 5 s: 0 bloques perdidos. Trabada 10 s: se pierden 2.0 s (lo
  que no cabe en el colchón de 8 s) y los dos archivos siguen del mismo largo.
- Los WAV se abren con cabecera y tamaño correctos. Con `FILTRAR_CRUDO 0` el **crudo es bit a bit**
  lo que entró por el micrófono; con el techo puesto, coincide con la entrada filtrada por el mismo
  Butterworth calculado aparte.
- Tarjeta que deja de aceptar datos a mitad de toma: se cierra, el LED queda en magenta y el
  audio sigue sonando.

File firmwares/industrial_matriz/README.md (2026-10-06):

# industrial_matriz

Dos máquinas al mismo reloj. La **base** es un bombo a negras y un bajo potente. La **fábrica**
son 5 pistas de sonidos industriales que corren en paralelo con su propio largo. Los visuales
salen en una **matriz WS2812 de 32×8**.

## Conexión

- La matriz va **encadenada después de los 6 LEDs de la placa**, en el mismo pin (GPIO 46): el
  DIN de la matriz se conecta a la salida de datos de la placa.
- **Aliméntala aparte** con 5 V (4 A o más), con GND común con la placa y un condensador de
  1000 µF en su entrada. Con 256 LEDs colgados del 5 V de la placa se hunde el riel y se corta
  el audio. El firmware trae un limitador de corriente (`MATRIZ_MAX_MA`, 450 mA por defecto,
  seguro para USB). Con fuente propia súbelo a 2500.

## Prueba de orientación (los primeros 3 s)

| Debería verse | Si no |
|---|---|
| ROJO arriba a la izquierda, VERDE arriba a la derecha, AZUL abajo a la izquierda | `MATRIZ_ESPEJO_X` / `MATRIZ_ESPEJO_Y` |
| Una columna blanca que barre de izquierda a derecha | Si se ve como puntos sueltos o una fila: `MATRIZ_POR_COLUMNAS` |
| La columna entera y recta | Si zigzaguea, columna por medio invertida: `MATRIZ_SERPENTINA` |

Las cuatro constantes están juntas, arriba del `.ino`.

## Controles

| | |
|---|---|
| BTN1 | Play / Stop (arranca en el "1") |
| BTN2 | Nuevo patrón de percusión industrial (golpes, largo del ciclo y afinación) |
| BTN3 | Línea de bajo y figura del arpegio nuevas (los acordes y el keys van en el menú) |
| BTN4 (mantener) + POT1 | **Tempo** (70–170 BPM). Cambia desde donde estaba, sin saltos: el recorrido entero del pot son 120 BPM. Al soltar BTN4, el volumen se queda donde estaba hasta que el POT1 vuelva a pasar por esa posición |
| BTN5 | **Break**: mientras lo mantienes se callan bombo y bajo y lo demás sigue; al soltar vuelven a tiempo. Mantenido **más de 2 s** empieza la **subida** (ver abajo) |
| **BTN2 + BTN4** | Entra y sale del **menú de bancos** (ver abajo) |
| POT1 | Volumen |
| POT2 | Mezcla base ↔ resto (al centro suena todo a pleno) |
| POT3 | Corte del filtro del bajo (la resonancia va atada al corte) |
| POT4 | Densidad de la percusión: al subirlo se agregan golpes y los que ya sonaban se quedan |

### Menú de bancos

BTN2 + BTN4 entra al menú: el LED 5 parpadea ámbar. Adentro:

| Botón | Banco | Escala |
|---|---|---|
| BTN1 | Em – C | Mi eólico |
| BTN2 | Cm – B♭ | Do eólico |
| BTN3 | Bm – G | Si eólico |
| BTN4 | E – F | Mi frigio dominante |
| BTN5 | El siguiente patrón del keys (5) | |

Dentro del menú, POT1 es el **ataque del bajo** (1 ms – 150 ms), POT2 su **caída** (40 ms – 1.2 s)
POT3 la **variación del patrón de acordes** y POT4 el **oscilador continuo**: dos sierras con un
detune leve (±6 cents) y reverb, para tocar melodías encima. La posición del pot es la altura, sin
escalones (primero fue cuantizado a la escala y Gonzalo lo prefirió continuo): barre dos octavas
cuyas dos puntas son la tónica del banco (en la octava 3 y dos más arriba), así la nota más grave y
la más aguda caen en la escala. Cada punta tiene un 2 % de tope donde la nota es la tónica exacta.
El timbre se mueve con un **pasa-bajos resonante modulado** por un LFO libre de velocidad
aleatoria: cada 1,5 a 6 s sortea una velocidad nueva entre 0,08 Hz (un barrido de 12 s) y 9 Hz (un
trino rápido) y se desliza hacia ella en ~1 s, así pasa de muy lento a muy rápido sin saltos. Primero
fue amarrado al tempo y Gonzalo lo prefirió suelto. La resonancia va atada al corte (alta cerrado,
baja abierto) para que no quede un pico chillón arriba; ajustes en `OSC_CORTE_MIN`, `OSC_LFO_*` y
`OSC_Q_*`. Para que suene espacial, cada sierra va cargada a un lado (el batido del detune se abre en
estéreo), pasa por un **chorus estéreo** propio (12 ± 4 ms, LFO de 0,35 Hz, una lectura por lado) y
tiene un envío fuerte al **delay ping-pong** del keys, a corchea con puntillo (~0,5 dB bajo el seco).
Antes tenía reverb; Gonzalo la cambió por delay + chorus, y `OSC_REVERB` quedó en 0 por si se quiere
volver a probar. El primer 5 % del recorrido es silencio. La lectura del pot va suavizada y con una zona muerta de
~6 cents, para que el ruido del ADC no haga vibrar la nota. Fuera
del menú sigue sonando la última nota que dejaste, como el resto del panel: para callarlo, entra y
baja el POT4 del todo. Los ajustes están en las constantes `OSC_*` y `NIVEL_OSC`.

**Variaciones del POT3** (8 zonas; P = acorde principal del banco, S = su segundo acorde). Todas
mantienen la escala y el estilo: cambia cuánto dura cada acorde y entran acordes nuevos de la
escala. Si un acorde nuevo no existe limpio en la escala del banco, o repetiría a otro, se usa el
vecino consonante.

| POT3 | Patrón | Ciclo | En Em–C |
|---|---|---|---|
| 1 | P·6 S·2 (la de siempre) | 8 | Em … C |
| 2 | P·4 S·4 | 8 | Em … C … |
| 3 | P·3 S·1 | 4 | Em Em Em C |
| 4 | P·6 iv·1 S·1 | 8 | Em … Am C |
| 5 | P·4 S·2 VII·2 | 8 | Em … C C D D |
| 6 | P·2 S·2 P·2 iv·2 | 8 | Em Em C C Em Em Am Am |
| 7 | P·5 III·1 S·2 | 8 | Em … G C C |
| 8 | P·8 S·4 iv·2 S·2 | 16 | Em ×8 C ×4 Am Am C C | Lo que dejes ahí se queda al salir. Al entrar o salir,
cada pot no cambia nada hasta que lo muevas un poco, así ni el volumen ni el bajo saltan.

### La subida (BTN5 mantenido más de 2 s)

1. Bombo y bajo se callan; percusión, keys y arpegio siguen.
2. Durante **16 compases** crecen un **ruido blanco** y un **oscilador agresivo** (dos sierras
   desafinadas y saturadas) que parte en la tónica grave del banco y sube 4 octavas.
3. Desde el **compás 9** se les suma un **trémolo rítmico** en semicorcheas, amarrado a la grilla
   de la música, hasta el final (frenarlo le quitaba el efecto), y entra una **caja** que crece:
   negras (9–10) → corcheas (11–12) → semicorcheas (13–16), cada vez más fuerte y más corta.
4. Termina en el **"1"** de un compás con un **golpe** (boom grave que cae + crash de ruido) que
   deja una **cola de reverb corta** (~1.5 s) sobre el silencio: todo lo demás se corta de golpe.
5. El próximo toque de BTN5 es el **drop**: todo vuelve desde el "1" con bombo y bajo. Si lo
   tocas antes de que termine la subida, el drop entra en ese momento.

LEDs 0 y 1: rojo parpadeando durante la subida, rojo fijo esperando el drop. Los ajustes están en
las constantes `SUBIDA_*`.

El acorde principal manda y el segundo aparece para evitar la monotonía; cuánto dura cada uno lo
elige la variación del POT3 (abajo). Los LEDs 0 a 3 muestran el banco
y el LED 4 el patrón del keys, con un color por patrón. La música no se detiene mientras eliges.
Se sale con BTN2 + BTN4, y el combo deshace lo que alcanzó a hacer el primero de los dos botones.

## Sonido

- **Bombo**: el de tres bandas de `trance_pistas`/`drum_poder`.
- **Armonía**: los 4 bancos de dos acordes del menú. La tonalidad cambia con el banco y el bajo,
  el arpegio y el keys la siguen.
- **Bajo**: el de `bajo_8_pasos`, con más drive. Sigue la fundamental de cada acorde y ninguna de
  sus 6 líneas toca en una negra. Su séptima es siempre menor; si el acorde trae séptima mayor,
  toca la quinta (la séptima mayor quedaba medio tono bajo la fundamental y sonaba desafinada).
- **Keys**: monofónico (nunca suenan dos notas a la vez). Un oscilador de **pulso con PWM**: un
  LFO lento le va cambiando el ancho y el timbre respira. Pasa por un pasa-bajos con envolvente,
  después por un **chorus estéreo** (retardo corto modulado en cuadratura, uno a cada lado) y por
  un **eco ping-pong a corchea con puntillo** que sigue al tempo. Cada repetición del eco se
  oscurece y cruza de lado; si el tempo cambia, el eco pasa al largo nuevo con un cruce de 50 ms en
  vez de deslizar el cabezal, que desafinaría las repeticiones. La tónica queda siempre entre Do4 y
  Si4. Toca uno de 5 patrones escritos, hipnóticos y oscuros, con ritmo y notas juntos y relativos
  al acorde: pulso con la sexta que cae a la quinta, la tercera insistente, descenso lento,
  semicorcheas y una nota larga con respuesta. Gonzalo los eligió en la placa; descartó el
  arpegio a contratiempo, la síncopa 3-3-4-3-3 y el dub. Los
  ajustes del timbre y de los efectos están en un bloque de constantes (`KEYS_*`, `CHORUS_*`,
  `ECO_*`).
- **Arpegio**: notas del acorde con el ritmo de los hats que suenan; la figura sólo pone el orden.
- **Percusión industrial**: HAT · MARTILLO (golpe sobre plancha) · PISTÓN (golpe hidráulico grave
  con escape) · CLAP (un solo golpe) · HAT ABIERTO · TOM. El ciclo dura 16 o 32 pasos y su posición
  se calcula siempre desde el paso de la base, así que cambiar de patrón nunca lo corre de tiempo.
  Antes había ciclos de 10, 12, 14, 20 y 24 pasos (un polirritmo): como 64 no es múltiplo de ellos,
  el ciclo se cortaba a la mitad cada 4 compases y cada patrón nuevo arrancaba en una fase
  cualquiera. Se oía como bajo y batería que no calzaban.
- **Descartado por sonar mal**: parciales metálicos afinados (sonaban a olla y a balón de gas),
  ráfagas de clics de ruido (sonaban a clipeo) y ráfagas de ruido que crecen (sonaban a ola).
- El bombo agacha al bajo, al pluck, al arpegio y a la percusión (sidechain). El master pasa por un bloqueador
  de DC, un limitador con lookahead y un pasa-bajos de 13 kHz.

## Matriz

Hay 8 escenas psicodélicas. Cada 4 compases (y en cada Play) se sortea una, nunca la misma dos
veces seguidas, y con ella se sortean la paleta, el sentido de giro y la forma, así que la misma
escena nunca se ve igual:

TÚNEL · PLASMA · CALEIDOSCOPIO · ESPIRAL · FIGURAS · MOIRÉ · ONDAS · DAMERO

Todo se mueve en tiempo musical, amarrado a la negra. El bombo ensancha las líneas, agranda las
figuras e invierte el damero. La envolvente real del bajo abre los contornos del plasma, y cada
golpe industrial suelta su figura (círculo, cuadrado, rombo o triángulo) o mueve su onda. Con la
máquina detenida la escena sigue, tenue y lenta.

Estas escenas encienden muchos LEDs a la vez. Con el tope de 450 mA el limitador las deja entre el
20 y el 40 % del brillo. Con fuente propia para la matriz, sube `MATRIZ_MAX_MA` y se ven a pleno.

## LEDs de la placa

0 bombo · 1 bajo · 2 hats · 3 martillo/pistón/clap/tom · 4 pluck/arpegio · 5 verde con el pulso de
cada negra. Durante el break, 0 y 1 quedan en rojo. Si el LED 5 se pone **magenta**, un bloque de
audio usó más del 80 % de su tiempo. En ese caso el problema es de CPU y no de señal.

## Tiempo de CPU (medido en la placa)

Un "clipeo" que aparece al sumar capas casi nunca es de nivel: es el audio que no alcanza a
calcular su bloque, el DMA se vacía y el DAC suelta ceros. Para separar las dos cosas está
`MEDIR`. Compilando con `-DMEDIR=1` la placa arranca tocando sola en el peor caso (densidad al
máximo, ruido y sirena encendidos) y cada 2 s imprime por el conector UART (115200) el uso de CPU,
lo que cuesta cada sección y cuánto trabaja el limitador.

Lo que más ayudó:

- **`#pragma GCC optimize ("O2")`**: el core de Arduino compila con `-Os` (tamaño). Con O2 el
  mismo código pasó de 65 % de promedio y picos de 95 % a **42 % / 58 %**.
- **FastLED se inicializa en la tarea de LEDs (core 0)**: hecho en `setup()` quedaba en el core 1
  y sus interrupciones le robaban tiempo al audio.
- Voces justas: el keys es monofónico, el arpegio usa 2 voces, la percusión sólo calcula los
  parciales que usa y los efectos que cambian lento se calculan cada 16 o 32 muestras.

## Verificado

- Compila con `arduino-cli` para ESP32-S3: 395 KB.
- Simulado en el PC con mocks durante 160 s de uso: play/stop, patrones, líneas, break, tap,
  barrido de los 4 pots y el peor caso (todo al máximo).
- Resultados: 0 NaN, 0 muestras al tope (pico 0.97 en el peor caso), ninguna voz trabada
  después del stop, tempo dentro del 0.07 %, las 4 escenas aparecen, ningún frame de la matriz
  pasa de 450 mA y el mapeo de la matriz cubre los 256 LEDs una vez cada uno.
- **Falta probarlo en la placa con la matriz.**

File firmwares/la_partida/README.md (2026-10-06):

# la_partida — "La partida" de Víctor Jara en 3 pistas MIDI

El PercuSynth toca el arreglo de **"La partida"** (Víctor Jara) desde sus tres pistas MIDI,
cada una con su propio motor de síntesis, a los tiempos exactos del archivo.

| Pista | Motor |
|---|---|
| **Melodía** (57 notas) | **Lead**: dos sierras PolyBLEP desafinadas ±7 cents + cuadrada → filtro pasa-bajos resonante (SVF) con envolvente de filtro. Glide corto entre notas ligadas y vibrato que entra ~180 ms después del ataque |
| **Bajo** (18 notas) | Una octava abajo del archivo (`TRANSP_BAJO = -12`), y las notas que igual quedan sobre La2 bajan otra octava (`BAJO_NOTA_MAX`): toda la línea vive en La1–La2. **Sierra + cuadrada** con un leve desafine entre ellas (−4 / +4 cents): el batido lento llena de armónicos. Saturación suave → SVF pasa-bajos con un toque de envolvente de filtro |
| **Arpegio** (127 notas) | **Pluck electrónico**: sierra + pulso 25 % desafinados 6 cents, cada nota con su propio filtro pasa-bajos que se abre de golpe (3.8 octavas) y se cierra 4× más rápido que el volumen. El piso del filtro sigue a la nota (1.8 × la fundamental), así que las colas quedan oscuras y afinadas. Paneo fijo por altura |

## Controles

| Botón | Panel | POT1 | POT2 | POT3 | POT4 |
|---|---|---|---|---|---|
| **BTN1** | **Play / Stop** + panel **general** | volumen general | velocidad (×0.5 … ×2) | — | — |
| **BTN2** | **melodía** | volumen | vibrato | filtro LPF | resonancia |
| **BTN3** | **bajo** | volumen | filtro LPF | resonancia | — |
| **BTN4** | **arpegio** | volumen | ataque (3–300 ms) | decay (0.08–1.2 s) | — |

- Play parte siempre desde el comienzo. Al terminar, la canción se detiene sola y deja sonar
  las colas (`REPETIR_CANCION = true` para que vuelva a empezar).
- **Velocidad:** el centro del pot tiene una zona muerta que deja exactamente los 80 BPM
  originales.
- **Pots por panel:** al entrar a un panel ningún pot cambia nada hasta que lo mueves (~5 %).
  Desde ahí la posición física es el valor, y cambiar de panel nunca pisa lo del otro.
- **LEDs de la placa:** 0 melodía · 1 bajo · 2 arpegio (destellan con cada nota) · 3 pulso de
  negra (fuerte en el 1) · 4 panel (general blanco, melodía cian, bajo violeta, arpegio naranjo)
  · 5 verde tocando / rojo tenue detenido / **magenta = sobrecarga de CPU** (ver abajo).

## De dónde salen las notas

El `.mid` exportado (`GC Lab Chile/la partida-victor jara.mid`) trae **una sola pista**: la del
arpegio. Las tres pistas se sacaron del proyecto de Ableton `la partida victor jara.als` con
`extraer_cancion.py`, que respeta lo que suena en el arreglo: posición de cada clip, su ventana,
el loop y el offset interno (el clip de la melodía arranca en la negra 28 de su loop), y corta
las notas que pasan del final del clip. El arpegio extraído coincide nota por nota con el `.mid`.

```bash
python extraer_cancion.py "ruta/a/la partida victor jara.als"
```

Sirve para cualquier otro proyecto con tres pistas MIDI en el orden melodía · bajo · arpegio.
La transposición de cada pista se ajusta con `TRANSP_MELODIA` / `TRANSP_BAJO` / `TRANSP_ARPEGIO`
en el `.ino` (0 = las notas del archivo; la melodía queda en Mi5–Sol6, tal como está en el arreglo).

## Tiempo exacto

480 ticks por negra, 80 BPM, 4/4, 68 negras = **51.00 s**. La posición se cuenta con un
acumulador de 64 bits (32.32) que avanza **una vez por muestra**, así que cada nota cae en la
muestra que le corresponde. Error acumulado del reloj en toda la canción: **0.12 µs**.

## Por qué no hace clicks

- Ninguna fase se reinicia y ningún ataque parte de cero: sube desde donde esté la envolvente.
- El arpegio tiene **una voz por altura**: re-tocar una nota re-dispara esa voz desde donde
  está (amplitud y filtro suben linealmente desde su nivel actual). Nunca se roba una voz, y se
  apaga en dos etapas: a −60 dB pasa a un cierre de 1.5 ms y se libera a −82 dB.
- **Por qué se cambiaron las campanitas:** con decay largo sonaban muchas a la vez y sus parciales
  inarmónicos (2.76 y 5.40) se sumaban en una bruma disonante que se oía como ruido. El pluck
  tiene armónicos afinados y el filtro se cierra con la cola: con decay largo se suma sin ensuciar
  (peor caso medido, todo al máximo: 11 voces, el limitador baja apenas 0.7 dB).
- Pots suavizados por muestra (12 ms); SVF de Zavalishin, estable con el corte en movimiento.
- Resonancia atada al corte: sobre 3 kHz el Q máximo se achica.
- Stop cierra todo con un tau de 40 ms. Ataque mínimo del arpegio: 3 ms.
- Bloqueador de continua, limitador con ganancia suavizada y saturación suave al final.
- Audio en su propia tarea en el **core 1**; botones, pots y LEDs en el **core 0** a 1 kHz. Sin Serial.

## Ruido con el decay del arpegio alto: casi seguro, tiempo de CPU

El ruido siguió después de cambiar las campanitas por el pluck, y la simulación sale limpia en
ese mismo caso: la señal está bien, así que lo más probable es el tiempo. Con decay alto suenan
hasta ~11 notas del arpegio a la vez, y cada una recalculaba su filtro con `tanf`/`powf`, que en
el S3 cuestan cientos de ciclos. Si el render de 128 muestras no cabe en sus 2.9 ms, el DMA se
vacía y el driver manda ceros, y eso se oye como ruido. (En el PC esas funciones son baratas, por
eso la simulación no lo reproduce.) Arreglo: `tanRapido` (Padé), `exp2Rapido`/`log2Rapido` (polinomios, error
< 0.04 %), compensación de Q fija en el arpegio y coeficientes cada 32 muestras. Estimado en el
S3: de ~4300 a ~1700 ciclos por muestra de los ~5400 disponibles.

**Indicador:** si un buffer tarda más del 80 % de su tiempo, el LED 5 destella **magenta**. Si
vuelve a haber ruido y el LED destella, el problema sigue siendo de tiempo; si no destella, es
otra cosa.

**Verificado en simulación** (el `.ino` compilado en el PC con mocks): canción completa, stop y
play a mitad, barrido de todos los pots mientras suena, velocidad ×0.5 y ×2, ataque y decay en
los extremos, cada pista aislada y todos los volúmenes y el decay al máximo. **0 clicks**
(detector de transitorios en alta frecuencia, calibrado con un corte en seco y con un escalón de
−6 dB), **0 NaN, 0 muestras saturadas**, pico entre −14 y −1.4 dBFS según el volumen.

## Requisitos

ESP32 Arduino core ≥ 3.x · **FastLED** · placa *ESP32S3 Dev Module*, USB CDC On Boot *Enabled*,
Flash Mode **DIO**.

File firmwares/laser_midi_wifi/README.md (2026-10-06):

# laser_midi_wifi — Nodo sensor que manda MIDI por WiFi (prueba de enlace)

Este firmware nació experimentando con **malabarismo**: la idea es **detectar las clavas en el
aire y que sus pasos generen música**. El sensor tiene que ir lejos del computador (en el
espacio donde se lanza), así que el MIDI viaja **por WiFi** con **RTP-MIDI** (el "MIDI de red"
que Mac, iPhone y Windows ya entienden).

Por ahora **no hay sensor todavía**: el sketch manda **un Do cada segundo** para comprobar que la
cadena completa funciona:

```
ESP32-C3  →  WiFi  →  sesión RTP-MIDI  →  computador / iPhone
```

Cuando esto suena, lo único que falta es el sensor; lo demás ya está probado.

## Placa

**ESP32-C3** (una SuperMini, por ejemplo): **no es un PercuSynth**, es el nodo sensor que le va a
hablar a la música.

- Placa: **ESP32C3 Dev Module** · USB CDC On Boot: **Enabled** · Upload Speed: 921600
- Librería: **Arduino AppleMIDI Library** (lathoub), desde el gestor de librerías. Arrastra sola la
  librería MIDI de FortySevenEffects.

## Credenciales

El nombre y la clave de las redes **no van en el `.ino`**. Copia `secretos.example.h` como
`secretos.h` en esta misma carpeta y complétalo:

- `AP_SSID` / `AP_CLAVE`: la red que **crea el ESP32** (modo punto de acceso). La inventas tú; la
  clave tiene que tener **8 caracteres o más**.
- `WIFI_SSID` / `WIFI_CLAVE`: tu red de siempre, si usas el modo cliente. Tiene que ser de
  **2.4 GHz**.

`secretos.h` está en el `.gitignore`: nunca se sube. Si falta, el sketch no compila y te dice
qué hacer.

## Dos modos de red (`MODO_AP` en el `.ino`)

- **`true` (por defecto) — el ESP32 crea su propia red.** Es el modo para tocar: red vacía, un
  salto menos y no dependes del WiFi del lugar. El computador queda sin internet mientras está
  conectado ahí.
- **`false` — el ESP32 se une a tu red.** Más cómodo para desarrollar.

En una casa tranquila la diferencia de latencia es de pocos milisegundos; el punto de acceso
propio gana de verdad en lugares con WiFi saturado (un evento, una sala llena de celulares).

## Cómo probarlo

1. Completa `secretos.h`, carga el sketch y abre el monitor serie a 115200: te muestra la IP.
2. Conecta el computador a la red del ESP32 (va a decir "sin internet": es lo esperado).
3. Abre la app que **abre la sesión de red**: en iPhone/iPad "RTP-MIDI (Network MIDI)" o
   "NetMIDI"; en Windows **rtpMIDI** de Tobias Erichsen; en Mac **Configuración de Audio MIDI →
   ventana Red**. Busca **GCLab-Laser** y conéctate.
4. Elige esa entrada MIDI en cualquier sinte o DAW: debería sonar un Do cada segundo.

Ojo: **Synth One no abre sesiones** (sólo recibe MIDI que ya existe) y **midimittr sólo hace
Bluetooth**: ninguno de los dos sirve para el paso 3.

## Si no aparece en la lista

- En modo punto de acceso: revisa que el computador siga en la red del ESP32. Los sistemas
  tienden a volver solos a una red con internet.
- En modo cliente: el ESP32 y el computador deben estar en la misma red y la misma banda. Los
  routers que separan 2.4 y 5 GHz, o que bloquean el multicast entre clientes, rompen el
  descubrimiento.
- En Mac se puede agregar a mano por IP con el botón "+" del directorio.

## Decisiones

- **`WiFi.setSleep(false)` no es opcional.** Sin esa línea el ESP32 duerme entre paquetes y
  mete decenas de milisegundos de jitter — justo lo que se fue a buscar el WiFi para evitar.
- **El nombre de la sesión no lleva espacios ni tildes**: se usa como nombre de host en mDNS, y
  con espacios el anuncio falla y el aparato no aparece en ninguna app.
- `MIDI.read()` se llama siempre y sin bloquear: es lo que mantiene viva la sincronización de
  reloj de la sesión.

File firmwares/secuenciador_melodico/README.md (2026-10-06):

# secuenciador_melodico — Secuenciador melódico de 16 pasos en modos griegos

Autor: **Nicolás Martínez Contreras**.

Secuenciador **monofónico** de 16 pasos donde cada paso es un **grado de la escala** (o un
silencio), así todo lo que toca queda dentro del modo elegido. Los 7 **modos griegos** (jónico,
dórico, frigio, lidio, mixolidio, eólico, locrio) se recorren con un botón. Trae una
**webapp** (`secuenciador_melodico webapp/`) que se conecta por **Web Serial** para editar la
secuencia con el mouse y ver el paso que suena.

## Controles

| Control | Qué hace |
|---|---|
| BTN1 | Play / Stop |
| BTN2 | Modo griego siguiente (7) |
| BTN3 | Reversa (la secuencia corre hacia atrás) |
| BTN4 | Secuencia al azar |
| BTN5 | Borrar la secuencia |
| POT1 | Volumen |
| POT2 | Tempo (los pasos son semicorcheas) |
| POT3 | Transposición −12…+12 semitonos |
| POT4 | Envolvente (ataque / caída) |

Los 6 LEDs de la placa muestran el estado.

## Webapp

Abre `secuenciador_melodico webapp/secuenciador melodico.html` en Chrome o Edge, conecta el
PercuSynth por Web Serial (115200) y edita los pasos en la pantalla. La placa le manda su
estado (`SCALE`, `DIR`, `PITCH`, `VOL`, `BPM`, `ENV`, `STEP`, `SYNC`) y recibe la secuencia con
`SEQ`.

## Librerías

- **ESP32Synth** (motor de síntesis que maneja el I2S)
- **FastLED**

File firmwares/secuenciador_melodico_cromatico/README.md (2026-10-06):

# secuenciador_melodico_cromatico — Secuenciador polifónico de 16 pasos, 12 notas

Autor: **Nicolás Martínez Contreras**.

Secuenciador **polifónico** de 16 pasos sobre una **octava cromática** (12 notas, de Do a Si):
cada paso puede tener cualquier combinación de notas sonando a la vez, así se escriben acordes
además de melodías. Hay 12 voces, una por nota. Trae una **webapp**
(`secuenciador melodico cromatico webapp/`) que se conecta por **Web Serial** para editar la
grilla de 16 × 12 con el mouse.

## Controles

| Control | Qué hace |
|---|---|
| BTN1 | Play / Stop |
| BTN2 | Forma de onda siguiente: pulso → sierra → triángulo → seno |
| BTN3 | Reversa |
| BTN4 | Secuencia al azar |
| BTN5 | Borrar la secuencia |
| POT1 | Volumen |
| POT2 | Tempo (los pasos son semicorcheas) |
| POT3 | Transposición −12…+12 semitonos |
| POT4 | Envolvente (ataque / caída, desde el centro) |

Los 6 LEDs de la placa muestran el estado.

## Webapp

Abre `secuenciador melodico cromatico webapp/secuenciador melodico cromatico.html` en Chrome o
Edge y conecta el PercuSynth por Web Serial (115200). La placa le manda su estado (`PLAYING`,
`DIR`, `PITCH`, `WAVE`, `VOL`, `BPM`, `ENV`, `SYNC`) y recibe la secuencia con `SEQ`; desde la
webapp también se puede dar play y stop.

## Librerías

- **ESP32Synth** (motor de síntesis que maneja el I2S)
- **FastLED**

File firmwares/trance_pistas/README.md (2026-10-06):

# trance_pistas — Trance con peso, sintetizado en 4 pistas, con visuales

El hermano sintetizado de [`mezclador_pistas`](../mezclador_pistas/). Es la misma idea: cuatro pistas que suenan juntas, cada una con volumen, filtro, resonancia y efecto rítmico, y cada una mueve su capa en **Resonancia**. La diferencia es que la música la hace la placa, así que **no necesita el módulo microSD**.

La referencia es **"Hey Boy Hey Girl" de Chemical Brothers**: bombo y bajo pesados, un riff corto que se repite y calza con la armonía, stabs de acordes rave y builds hacia el drop. Se llegó acá tras cuatro rondas rechazadas:
- **Trance de acordes con arpegio:** plano.
- **Modos oscuros con notas de color:** "suena feliz, darkwave".
- **Cyber o industrial:** "le falta trance, le falta peso; las notas que no concuerdan con la armonía no me gustan; el pad se desaprovecha".

Los sonidos de batería y bajo **no se inventaron**: son los de dos firmwares que ya estaban aprobados.

| Pista | Qué suena |
|---|---|
| 0 · batería | **Las voces de [`drum_poder`](../drum_poder/)**, con el kit NEXO, el híbrido 808/909. El bombo tiene tres bandas: fundamental que aterriza en 46 Hz, 2.º armónico con saturación propia, mazo de ruido pasa-banda de 14 ms y click de 5 ms. La caja va afinada (dos parciales que caen un 15 %), con bordonera de ruido y crack de 3,4 kHz, sin saturación. El clap son tres palmadas a 0, 6,5 y 13 ms más la cola. Los hats y el plato son ruido pasa-banda. Cada pista va con **su pasa-altos de banda** (caja 150 Hz, clap 900, hats 2,5 k, plato 1,5 k), la mezcla fija de drum_poder. Dos instancias de bombo y caja: la que sonaba se apaga en 3 ms cuando entra la nueva |
| 1 · bajo | **El de [`bajo_8_pasos`](../bajo_8_pasos/)**: dos sierras PolyBLEP (una +9 cents) y una cuadrada una octava abajo, saturación suave, SVF pasa-bajos con envolvente de filtro de 3,2 octavas que cierra antes que el volumen. Se agacha un 30 % con el bombo para que no se embarren |
| 2 · riff | Un riff corto y sincopado que se repite y **solo toca notas del acorde** del momento. Es un pluck de dos sierras con filtro por nota y eco ping-pong a corchea con punto |
| 3 · acordes | Pad supersaw (2 sierras ±9 cents por nota) que **crece por secciones**: ausente en A, filtrado en A', **se abre durante toda la ruptura** (el build) y en el drop bombea con el bombo (−60 %). Encima van **stabs de acordes rave** y una subida de ruido antes del drop |

## Temas

La armonía es menor natural y consonante (i, iv, v, VI, VII): cero notas que choquen con el acorde. Cada tema es un viaje de **32 compases**:

| Compases | Sección | Qué suena |
|---|---|---|
| 1–8 | A | Batería, bajo y el riff A |
| 9–16 | A' | Entra el pad filtrado y los hats abiertos; en la segunda mitad, los stabs |
| 17–24 | Ruptura | Sin bombo ni bajo. El pad se abre de a poco, el riff B va a media densidad y en los compases 23–24 hay redoble y subida de ruido |
| 25–32 | Drop | Todo: pad bombeando, stabs, riff B y plato |

| # | Tema | BPM | Tónica | Progresión A | Progresión B |
|---|---|---|---|---|---|
| 1 | Fuego | 132 | La menor | i · i · VI · VII | VI · VII · i · i |
| 2 | Pulso | 136 | Mi menor | i · VII · VI · VII | i · VI · iv · v |
| 3 | Motor | 128 | Re menor (big beat) | i · iv · i · iv | VI · iv · VII · i |
| 4 | Trueno | 138 | Fa# menor | i · VI · iv · v | i · VI · VII · VII |
| 5 | Aurora | 140 | Si menor | i · i · iv · iv | VI · VII · iv · v |
| 6 | Vértigo | 134 | Sol menor | i · v · VI · iv | iv · v · i · i |

**BTN1 mantenido 2,5 s** pasa al siguiente tema.

Todo es dato:
- **Batería:** `X` acento, `x` normal, `.` fantasma.
- **Bajo:** `x` tónica, `o` octava, `5` quinta.
- **Riffs (`RIFFS[]`):** índices a las notas del acorde (0–2, y 3–5 una octava arriba).

## Controles

Son los mismos que los de `mezclador_pistas`, con bancos:

- **BTN1** toque = banco general: POT1 bajo · POT2 riff · POT3 batería · POT4 acordes (volúmenes). Mantener 0,5 s = play / stop. Mantener 2,5 s = siguiente tema.
- **BTN2** bajo · **BTN3** riff · **BTN4** batería · **BTN5** acordes. En cada banco: POT1 filtro (centro abierto, izquierda pasa-bajos, derecha pasa-altos) · POT2 resonancia · POT3 efecto rítmico (gate 1/8, 1/16 · repeat 1/2 … 1/16) · POT4 intensidad.
- Al cambiar de banco, una perilla toma el control recién cuando la mueves: nada salta.

## LEDs

- **LED 0:** verde sonando, ámbar en stop; parpadea en blanco con el banco general.
- **LEDs 1 a 4:** cada pista con su color, según su nivel.
- **LED 5:** el pulso. Parpadea en **magenta** si la CPU no alcanza, es decir, si un bloque de audio pasa el 80 % de sus 2,9 ms.

## Resonancia

La línea serial es idéntica a la de `mezclador_pistas` (`R,…` de 43 campos, 60 por segundo), así Resonancia no distingue una placa de la otra. La línea `I` suma un octavo campo con los nombres de las pistas (`batería|bajo|riff|acordes`), y Resonancia los usa en el panel de bancos y en el de capas.

Los golpes no se detectan: salen del secuenciador, así que son exactos.
- **Bajo:** un golpe por grupo de notas.
- **Arpegio:** un golpe por corchea.
- **Pad:** un golpe por cambio de acorde.

## Instalar sin Arduino IDE

Resonancia (`web/public_html/resonancia/`) trae el instalador: **Entrada → Instalar firmware Trance**, con ESP Web Tools. Funciona en Chrome o Edge y necesita https. La imagen está en `resonancia/firmware/trance.bin`. Para regenerarla después de tocar el `.ino`:

```bash
arduino-cli compile --fqbn "esp32:esp32:esp32s3:CDCOnBoot=cdc,FlashMode=dio,PSRAM=opi,USBMode=hwcdc" --build-path build trance_pistas
```

Después hay que copiar `build/trance_pistas.ino.merged.bin` a `resonancia/firmware/trance.bin`. Conviene quitarle antes el relleno de `0xFF` del final, redondeado a 4 KB: así baja de 4 MB a unos 480 KB.

Si el instalador no encuentra el puerto: desconecta el cable, mantén **BTN3** (es el GPIO 0, BOOT) y vuelve a conectarlo.

## Verificación

Antes de flashear, el `.ino` se compiló en el PC contra imitaciones de `Arduino.h`, `i2s_std.h`, `FastLED.h` y `Wire.h`, y se renderizó a WAV:
- **Los 6 temas completos:** pico 0,62–0,71, RMS −15 dBFS, 0 recortes, 0 NaN.
- **Cada pista sola y todas al 100 %:** pico 0,91 con el limitador.
- **Filtros a fondo con resonancia máxima, y barridos:** sin NaN.
- **Los 6 efectos rítmicos en todas las pistas, stop/play ×10 y volúmenes 0↔1 de golpe ×40:** 0 recortes.
- **Sin PSRAM:** suena igual; solo se apagan los repeat.
- **Espectro:** ningún pico tonal más de 14 dB sobre su tercio de octava entre 600 Hz y 16 kHz. Arriba de 16 kHz queda 52 dB abajo.

**Y lo que la simulación NO veía:** la primera versión calculaba todo muestra a muestra, recorriendo ~15 voces en cada muestra, con divisiones y `exp2f` adentro.
- **Medido en la placa con el contador de ciclos:** 7.400 ciclos por muestra, de los 5.442 que hay a 240 MHz; el 136 % de la CPU.
- **Por voz:** arpegio 2.330, pad hasta 1.660, batería 870, bajo 500, cadena 2.200.
- **Lo que se escuchaba:** el DMA se quedaba sin datos y metía silencio. Eran cortes como clipeos, el tempo arrastrado y todo "desafinado".

El motor actual va **por bloques**:
- Cada voz se calcula de corrido para las 128 muestras, con su estado en variables locales.
- No hay divisiones por muestra: el PolyBLEP usa `1/inc` precalculado y la saturación es cúbica.
- Los coeficientes de los filtros se recalculan cada 16 muestras, con `exp2Rapido` y `tanRapido`.
- Lo que corre 44.100 veces por segundo va en `IRAM_ATTR`.
- El eco está en RAM interna.

Medido en la placa así: **46 % de CPU en promedio, 59 % de máximo**. Con los 4 repeat activos, filtros y resonancia al máximo: **56 % y 66 %**. 344 bloques por segundo, ningún bloque sobre el 80 %.

Con la batería de drum_poder, el bajo de bajo_8_pasos, el pad y los stabs, medido **en el drop** con los 4 repeat y la resonancia al máximo: **60 % de promedio y 75 % de máximo**, 0 bloques atrasados. Con los efectos apagados queda ~15 puntos más abajo. Para llegar ahí:
- Las voces de bombo y caja se liberan a −70 dB, no a −80; si no, seguían calculando la cola casi 3 s después de dejar de oírse.
- Las capas de ruido se saltan cuando ya son inaudibles.
- El pad usa 2 sierras por nota.

La lección: **el PC no mide el costo en el S3**. Antes de dar por bueno un firmware con varias voces, mídelo en la placa con `ESP.getCycleCount()`.

Requiere **FastLED**. La PSRAM es opcional.

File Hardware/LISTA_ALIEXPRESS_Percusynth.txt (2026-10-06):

*PercuSynth · Lista de materiales (placa V2.0)*

Todo se compra en AliExpress. Pide lo antes posible, que el envío a Chile se demora.
Muchos componentes vienen en paquetes (10, 50, 100 unidades): con el paquete más chico te alcanza.
Donde un enlace tiene varias opciones, elige la que se indica.

*1. Módulos*

• ESP32-S3 DevKitC-1 *N16R8* × 1
Tiene que ser *S3* y variante *N16R8*
https://es.aliexpress.com/item/1005009330328373.html

• DAC PCM5102A × 1
https://es.aliexpress.com/item/1005012358077206.html

• IMU MPU6050 × 1
https://es.aliexpress.com/item/1005005617813897.html

• Micrófono INMP441 × 1
https://es.aliexpress.com/item/1005012097806013.html

*2. Conectores*

• Jack 6.3 mm hembra mono, para PCB × 4
https://es.aliexpress.com/item/32757640538.html

• Conector DIN-5 hembra para PCB × 1
https://es.aliexpress.com/item/1005010728587970.html

• Bornera de tornillo *3 vías* (paso 5.08 mm) × 3
• Bornera de tornillo *2 vías* (paso 5.08 mm) × 1
Las dos salen del mismo enlace
https://es.aliexpress.com/item/1005007145396958.html

*3. Controles y luces*

• Potenciómetro *1K*, vertical, eje 20 mm × 4
Es la primera opción del listado
https://es.aliexpress.com/item/4000665266312.html

• Switch mecánico × 5
https://es.aliexpress.com/item/1005007891400560.html

• Keycaps × 5
https://es.aliexpress.com/item/1005008404422530.html

• LED WS2812B *6028* × 6
https://es.aliexpress.com/item/1005008658792377.html

*4. Componentes*

• Resistencia 220 Ω × 2
• Resistencia 1 MΩ × 5
• Resistencia 100 kΩ × 4
Las tres salen del mismo enlace, eliges el valor
https://es.aliexpress.com/item/1005003923602966.html

• Diodo Schottky 1N5817 × 4
https://es.aliexpress.com/item/1005012949107224.html

• Condensador cerámico 10 nF (código 103) × 4
https://es.aliexpress.com/item/1005004787479555.html

• Condensador electrolítico 100 µF × 1
https://es.aliexpress.com/item/1005002524973878.html

*5. Tiras de pines hembra 2.54 mm*

Todas salen del mismo enlace, eliges el número de pines
https://es.aliexpress.com/item/1005009799089778.html

• 22 pines × 2 (ESP32-S3)
• 8 pines × 1 (MPU6050)
• 6 pines × 1 (DAC)
• 3 pines × 1 (DAC)
• 4 pines × 1 (pantalla OLED)

*6. Para tocar*

• Disco piezo × 4
https://es.aliexpress.com/item/1005006719344052.html

• Pantalla OLED 0.96" I2C × 1
https://es.aliexpress.com/item/1005006141235306.html

• Tira LED WS2812B × 1 (el largo que quieras)
https://es.aliexpress.com/item/1005006766819624.html

*Y además tienes que tener*
• Cable USB-C *de datos* (no sirve uno de sólo carga)
• Parlante amplificado, audífonos o interfaz de audio

¿Dudas con algún componente? Escríbeme antes de comprar.
GC Lab Chile

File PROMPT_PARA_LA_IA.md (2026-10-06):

# PROMPT PARA LA IA — PercuSynth (GC Lab Chile)

> **Cómo usar este documento:** Si tienes un **PercuSynth** y quieres que una IA (ChatGPT, Claude, Gemini, etc.) te genere código que **compile y funcione a la primera**, pega este archivo completo al inicio de tu conversación y luego escribe lo que quieres lograr. Este documento le da a la IA todo el contexto de hardware, configuración del Arduino IDE, librerías y patrones de código del proyecto.

---

## 0. Instrucciones para la IA (léelas primero)

Eres un asistente experto en firmware para el **PercuSynth**, un laboratorio portátil de electrónica musical basado en **ESP32-S3** creado por **GC Lab Chile**. Vas a generar **sketches de Arduino (`.ino`) en C++11** para esta placa.

Reglas que **debes** respetar siempre:

1. **El pinout es fijo y NO se puede cambiar** (está soldado en la placa). Usa exactamente los pines de la sección 2. Nunca inventes pines.
2. **El audio sale por I2S a un DAC PCM5102** (estéreo, 44.1 kHz, 16-bit). No uses `dacWrite()` ni el DAC interno: usa el driver `driver/i2s_std.h` con el patrón de la sección 6.1.
3. **Flash Mode debe ser DIO, nunca OPI** — OPI rompe el audio I2S en este hardware. Recuérdaselo siempre al usuario en los settings.
4. **Los LEDs 0–5 son SMD internos de la placa**: deben quedar siempre apagados. Empieza a dibujar desde el LED índice 6 (`START_LED`).
5. **Comentarios y nombres de variables en español** (convención del proyecto).
6. **Encabezado obligatorio formato proto-synth-v2** en todo `.ino` (ver sección 9): bloques HARDWARE / ARDUINO IDE / LIBRERÍAS / DESCRIPCIÓN / FUNCIONAMIENTO separados por líneas `====`.
7. **El loop de audio no debe bloquearse**: rellena buffers de 128 muestras y entrégalos con `i2s_channel_write()` (bloquea sólo lo justo por DMA). Nada de `delay()` dentro del render de audio.
8. Si el usuario pide algo ambiguo (qué botón hace qué, escala, etc.), **propón un mapeo razonable** basado en los firmwares existentes y dilo explícitamente, en vez de frenar.
9. Antes de entregar, **revisa mentalmente que el código compile** para `ESP32S3 Dev Module` con el core ESP32 ≥ 3.x.

---

## 1. Qué es el PercuSynth

Sintetizador/controlador de percusión electrónica portátil. Hardware único con varios firmwares intercambiables (drum machine, synth polifónico, controlador MIDI, secuenciadores, visualizadores de LED, juegos por Web Serial). El usuario **flashea** el `.ino` que quiera desde el Arduino IDE.

**Capacidades del hardware en una frase:** ESP32-S3 + DAC de audio estéreo (PCM5102) + 5 botones + 4 potenciómetros + acelerómetro (MPU6050) + tira/matriz de LEDs WS2812 + salida USB-MIDI + 4 entradas de piezo + 2 entradas de sensor externo.

---

## 2. Pinout (FIJO — no modificar)

| Señal | Pin / Canal | Notas |
|---|---|---|
| **I2S LCK / WS (LRCK)** | GPIO **39** | al PCM5102 |
| **I2S DIN / DOUT (DATA)** | GPIO **40** | al PCM5102 |
| **I2S BCK (BCLK)** | GPIO **41** | al PCM5102 |
| **BTN1** | GPIO **44** | `INPUT_PULLUP`, activo en LOW |
| **BTN2** | GPIO **42** | `INPUT_PULLUP`, activo en LOW |
| **BTN3** | GPIO **0** | `INPUT_PULLUP`, activo en LOW (es el boot button) |
| **BTN4** | GPIO **45** | `INPUT_PULLUP`, activo en LOW |
| **BTN5** | GPIO **47** | `INPUT_PULLUP`, activo en LOW |
| **POT1** | ADC **GPIO 1** | `analogRead(1)` |
| **POT2** | ADC **GPIO 2** | `analogRead(2)` |
| **POT3** | ADC **GPIO 8** | `analogRead(8)` |
| **POT4** | ADC **GPIO 10** | `analogRead(10)` |
| **Piezo 1–4** | ADC **GPIO 4, 5, 6, 7** | sensores de impacto |
| **Sensor externo A / B** | ADC **GPIO 3 / 9** | LDR, humedad, etc. |
| **LED WS2812 (data)** | GPIO **46** | tira o matriz; LEDs 0–5 son SMD internos → siempre apagados |
| **MIDI DIN-5 TX** | GPIO **43** | UART MIDI hardware (opcional; lo normal es USB-MIDI) |
| **I2C SDA (MPU6050)** | GPIO **21** | dirección I2C `0x68` (o `0x69` si AD0 alto) |
| **I2C SCL (MPU6050)** | GPIO **38** | |

- El audio I2S es **estéreo, 44.1 kHz, 16-bit**, hacia el **PCM5102**.
- Los pines ADC (pots/piezos/sensores) son **números de GPIO** que se pasan directo a `analogRead()`. "ADC1" aquí significa GPIO 1.
- **BTN3 = GPIO 0** es el botón de boot; funciona como botón normal en runtime, pero evita dejarlo presionado al energizar.

---

## 3. Configuración del Arduino IDE (menú Tools / Herramientas)

Selecciona la placa **ESP32S3 Dev Module** y ajusta:

| Opción del menú Tools | Valor | Por qué |
|---|---|---|
| **Board** | `ESP32S3 Dev Module` | |
| **USB CDC On Boot** | `Enabled` | para Serial por USB y USB-MIDI |
| **USB Mode** | `USB-OTG (TinyUSB)` | necesario para USB-MIDI |
| **Flash Mode** | **`DIO`** | ⚠️ **OPI rompe el audio I2S** en este hardware |
| **PSRAM** | `OPI PSRAM` | |
| **Partition Scheme** | `Huge APP (3MB No OTA/1MB SPIFFS)` | sólo si el sketch lleva samples grandes en PROGMEM (sequencers, samplers). Para firmwares chicos basta el default. |
| **Upload Speed** | `921600` (o baja a `115200` si falla) | |
| **CPU Frequency** | `240 MHz (WiFi)` | máximo, para tener cabeza de CPU en audio |

- **Monitor Serial: 115200 baud.**
- Core requerido: **ESP32 Arduino core ≥ 3.x** (es el que trae `driver/i2s_std.h`).

---

## 4. Librerías requeridas

Sólo incluye lo que el firmware use:

| Librería | Cuándo | Origen |
|---|---|---|
| `driver/i2s_std.h` | siempre que haya **audio** | incluida en el ESP32 core ≥ 3.x |
| `Wire.h` | para el **MPU6050 (IMU)** | incluida en el core |
| `USB.h` + `USBMIDI.h` | para **USB-MIDI** | incluidas en el core (TinyUSB) |
| `FastLED.h` | para los **LEDs WS2812** | instalar desde Library Manager (FastLED) |
| `ESP32Synth.h` | sólo los secuenciadores melódicos de Nicolás | instalar desde Library Manager |
| `AppleMIDI.h` | sólo `laser_midi_wifi` (MIDI por WiFi, ESP32-C3) | Library Manager: "Arduino AppleMIDI Library" de lathoub |
| `math.h`, `Arduino.h` | utilidades | estándar |

> Nota: el MPU6050 se lee normalmente **por registros crudos con `Wire`** (ver 6.4), así no hace falta ninguna librería externa de IMU. Es el estilo preferido del proyecto.

### 4.1 Credenciales: nunca dentro del `.ino`

Si el firmware necesita WiFi o una API key, **no las escribas en el sketch**. Van en un
`secretos.h` en la misma carpeta, que está en el `.gitignore` del repositorio:

```cpp
// En el .ino:
#if !__has_include("secretos.h")
  #error "Falta secretos.h: copia secretos.example.h a secretos.h y pon tus claves."
#endif
#include "secretos.h"
```

```cpp
// secretos.example.h  (esta plantilla SÍ se sube; secretos.h NO)
#pragma once
const char* WIFI_SSID      = "TU_RED_WIFI";
const char* WIFI_PASS      = "TU_PASSWORD_WIFI";
const char* OPENAI_API_KEY = "sk-proj-TU_API_KEY";
```

Deja siempre el `secretos.example.h` junto al sketch: es lo que le dice al que clona el repo
qué claves necesita. El `#error` hace que el problema aparezca al compilar y no al encender.

---

## 5. Constantes y convenciones de audio

```cpp
#define SAMPLE_RATE     44100   // Hz, estéreo
#define BUFFER_SAMPLES  128     // muestras por canal por bloque DMA
```

- El render llena un buffer de `int16_t buffer[BUFFER_SAMPLES * 2]` intercalado **L,R,L,R...** y lo entrega con `i2s_channel_write()`.
- Lectura de pots con **oversampling 8×** (sección 6.3).
- Coeficientes de filtros (biquad, one-pole) se recalculan por bloque a partir de los pots/IMU.
- Para evitar clicks al apagar voces, usa envolventes (attack/decay/release), nunca cortes secos.

---

## 6. Patrones de código canónicos (copia y adapta)

### 6.1 Inicialización I2S (DAC PCM5102)

```cpp
#include <driver/i2s_std.h>

#define I2S_LCK   39   // WS / LRCK
#define I2S_DIN   40   // DOUT / DATA
#define I2S_BCK   41   // BCLK
#define SAMPLE_RATE     44100
#define BUFFER_SAMPLES  128

i2s_chan_handle_t tx_chan;

void i2s_init() {
  i2s_chan_config_t chan_cfg = I2S_CHANNEL_DEFAULT_CONFIG(I2S_NUM_0, I2S_ROLE_MASTER);
  chan_cfg.auto_clear = true;
  ESP_ERROR_CHECK(i2s_new_channel(&chan_cfg, &tx_chan, NULL));

  i2s_std_config_t std_cfg = {
    .clk_cfg  = I2S_STD_CLK_DEFAULT_CONFIG(SAMPLE_RATE),
    .slot_cfg = I2S_STD_PHILIPS_SLOT_DEFAULT_CONFIG(I2S_DATA_BIT_WIDTH_16BIT, I2S_SLOT_MODE_STEREO),
    .gpio_cfg = {
      .mclk = I2S_GPIO_UNUSED,
      .bclk = (gpio_num_t)I2S_BCK,
      .ws   = (gpio_num_t)I2S_LCK,
      .dout = (gpio_num_t)I2S_DIN,
      .din  = I2S_GPIO_UNUSED,
      .invert_flags = { false, false, false },
    },
  };
  ESP_ERROR_CHECK(i2s_channel_init_std_mode(tx_chan, &std_cfg));
  ESP_ERROR_CHECK(i2s_channel_enable(tx_chan));
}
```

Entrega de un bloque de audio (en el `loop()`):

```cpp
int16_t buffer[BUFFER_SAMPLES * 2];   // intercalado L,R,L,R...
void renderAudioBlock() {
  for (int n = 0; n < BUFFER_SAMPLES; n++) {
    int16_t s = /* tu muestra mono o por canal */ 0;
    buffer[2*n]     = s;   // L
    buffer[2*n + 1] = s;   // R
  }
  size_t written;
  i2s_channel_write(tx_chan, buffer, sizeof(buffer), &written, portMAX_DELAY);
}
```

### 6.2 Botones (5, con `INPUT_PULLUP` + debounce y detección de flanco)

```cpp
const uint8_t BTN_PINS[5] = { 44, 42, 0, 45, 47 };   // BTN1..BTN5
bool     btnPrev[5]   = {};
uint32_t btnLastMs[5] = {};
#define  DEBOUNCE_MS 35

void botonesSetup() {
  for (int i = 0; i < 5; i++) pinMode(BTN_PINS[i], INPUT_PULLUP);
}

// devuelve true sólo en el flanco de PRESIÓN (con debounce)
bool botonFlanco(uint8_t i, uint32_t now) {
  bool pressed = (digitalRead(BTN_PINS[i]) == LOW);   // activo en LOW
  bool edge = false;
  if (pressed != btnPrev[i] && (now - btnLastMs[i]) > DEBOUNCE_MS) {
    btnLastMs[i] = now;
    btnPrev[i] = pressed;
    if (pressed) edge = true;
  }
  return edge;
}
```

> Combos: varios firmwares usan "dos botones a la vez" para cambiar de panel/modo (ej. BTN1+BTN5). Detecta combos leyendo `digitalRead()` de ambos en LOW.

### 6.3 Potenciómetros (oversampling 8×)

```cpp
const uint8_t POT_PINS[4] = { 1, 2, 8, 10 };   // POT1..POT4 (GPIO/ADC)

void potsSetup() {
  analogReadResolution(12);          // 0..4095
  analogSetAttenuation(ADC_11db);    // rango completo ~0..3.3V
}

int leerPot(uint8_t pin) {           // promedio de 8 lecturas
  uint32_t s = 0;
  for (int i = 0; i < 8; i++) s += analogRead(pin);
  return s >> 3;                     // 0..4095
}
```

> Para que un pot físico no "pelee" con un valor seteado por software (Web MIDI, cambio de panel), usa **histéresis**: sólo aplica el pot cuando se movió más de un umbral (`abs(p - lastP) > 20`).

### 6.4 IMU MPU6050 (I2C, lectura por registros crudos)

```cpp
#include <Wire.h>
#define SDA_PIN   21
#define SCL_PIN   38
uint8_t imuAddr = 0x68;   // 0x69 si AD0 está en alto

bool detectIMU(uint8_t a) {
  Wire.beginTransmission(a);
  return (Wire.endTransmission() == 0);
}

void initIMU() {
  Wire.begin(SDA_PIN, SCL_PIN);
  Wire.setClock(400000);
  if      (detectIMU(0x68)) imuAddr = 0x68;
  else if (detectIMU(0x69)) imuAddr = 0x69;
  // Despertar y configurar
  Wire.beginTransmission(imuAddr); Wire.write(0x6B); Wire.write(0x00); Wire.endTransmission(true); // wake
  Wire.beginTransmission(imuAddr); Wire.write(0x1A); Wire.write(0x00); Wire.endTransmission(true); // DLPF off
  Wire.beginTransmission(imuAddr); Wire.write(0x1C); Wire.write(0x00); Wire.endTransmission(true); // ACCEL ±2g
  delay(100);
}

// Lee aceleración en g. Divisor según el rango configurado en 0x1C:
//   ±2g → 16384 LSB/g   ±4g → 8192   ±8g → 4096   ±16g → 2048
void leerAccel(float &x, float &y, float &z) {
  Wire.beginTransmission(imuAddr);
  Wire.write(0x3B);                 // ACCEL_XOUT_H
  Wire.endTransmission(false);
  Wire.requestFrom((int)imuAddr, 6, true);
  int16_t ax = (Wire.read() << 8) | Wire.read();
  int16_t ay = (Wire.read() << 8) | Wire.read();
  int16_t az = (Wire.read() << 8) | Wire.read();
  x = ax / 16384.0f; y = ay / 16384.0f; z = az / 16384.0f;
}
```

> Uso típico: mapear `accelX → cutoff` del filtro y `accelY → resonancia (Q)`, o usar el **pico de aceleración** como disparo de golpe (impact_chimes, MIDI_Drum) y como velocidad MIDI.

> ⚠️ **Detección del IMU — la prueba real son los DATOS, no el `WHO_AM_I`.** Muchos MPU6050 **clones** devuelven un WHO_AM_I distinto de `0x68` (0x70/0x72/0x98…) y aun así funcionan perfecto. **NUNCA gatees la lectura ni muestres "no detectado" basándote en `WHO_AM_I == 0x68`.** Para saber si el IMU está vivo, intenta leer los 14 bytes desde `ACCEL_XOUT_H` (0x3B) y comprueba `Wire.available() >= 14`; trata el WHO_AM_I como **solo informativo** (acepta cualquier valor). Otros errores a evitar: (1) leer registros **antes** de despertarlo (`PWR_MGMT_1=0`); (2) guardar **una sola** lectura en un `bool imuOk` global y condicionar todo a él para siempre (reintenta en el `loop()` → auto-recuperación); (3) **revisar el retorno de `Wire.endTransmission(false)`** — en ESP32 ese repeated-start puede devolver `!= 0` aunque el IMU esté presente; `test_imu.ino` lo ignora, cópialo igual. Referencia que SÍ funciona: `firmwares/test_imu/test_imu.ino` muestra el acelerómetro en cada vuelta del loop sin mirar el WHO_AM_I. **Regla general: si ya existe un firmware de referencia para un periférico (test_imu, test_leds, impact_chimes…), copia su secuencia de init/lectura exacta en vez de reescribirla.**

### 6.5 USB-MIDI (salida)

```cpp
#include "USB.h"
#include "USBMIDI.h"
USBMIDI MIDI;

void midiSetup() {
  MIDI.begin();
  USB.begin();
}

// API de alto nivel (canal 1..16). Batería General MIDI = canal 10.
MIDI.noteOn (nota, velocidad, 10);
MIDI.noteOff(nota, 0,         10);
```

Para **MIDI Clock Master** (secuenciadores) se envían bytes de tiempo real crudos vía TinyUSB:

```cpp
inline void midiRT(uint8_t status) {
  uint8_t pkt[4] = { 0x0F, status, 0, 0 };
  tud_midi_n_packet_write(0, pkt);
}
midiRT(0xF8);  // Clock (24 PPQ)
midiRT(0xFA);  // Start
midiRT(0xFC);  // Stop
```

### 6.6 MIDI DIN-5 (salida por UART, GPIO 43)

El conector DIN-5 de la placa se alimenta del **GPIO 43** a **31250 baud**. Es MIDI serie crudo: se
escriben los bytes a mano, no hay librería.

```cpp
#define MIDI_TX_PIN  43
HardwareSerial &MIDIOUT = Serial1;          // Serial1, NO Serial0 (ver la trampa de abajo)

void midiSetup() {
  MIDIOUT.begin(31250, SERIAL_8N1, -1, MIDI_TX_PIN);   // RX en -1: sin receptor
}

inline void midiSend3(uint8_t st, uint8_t d1, uint8_t d2) {
  uint8_t b[3] = { st, d1, d2 };
  MIDIOUT.write(b, 3);
}
midiSend3(0x90, nota, velocidad);   // Note On  canal 1  (0x90 | (canal-1))
midiSend3(0x80, nota, 0);           // Note Off canal 1
MIDIOUT.write(0xF8);                // Clock (24 PPQ) · 0xFA Start · 0xFC Stop
```

> ⚠️ **Las dos trampas del DIN-5, las dos por el mismo motivo.** El **UART0** del ESP32-S3 sale
> por los **GPIO 43 (TX) y 44 (RX)** — o sea que el TX del DIN-5 es *el mismo pin* que usa
> `Serial0`, y el RX que le correspondería es **el BTN1**. Entonces:
> 1. **No imprimas nunca por `Serial0`** en un firmware con MIDI DIN: esos bytes saldrían por
>    el cable MIDI como basura. El diagnóstico va **sólo por `Serial`** (USB CDC, con *USB CDC
>    On Boot = Enabled*).
> 2. **Usa `Serial1` con `rxPin = -1`.** La matriz de GPIO enruta el TX de `Serial1` al 43 y
>    deja el 44 en paz; si abres el RX, te quedas sin BTN1.
>
> Firmware de referencia: `firmwares/drum_poder/` (saca líneas de bajo + MIDI Clock por el DIN-5).

### 6.7 LEDs WS2812 (FastLED) — ojo con los 6 internos

```cpp
#include <FastLED.h>
#define LED_PIN      46
#define START_LED     6          // LEDs 0..5 = SMD internos → SIEMPRE apagados
#define NUM_LEDS    300          // total real de tu tira/matriz (incluye los 6 internos)
#define MAX_BRIGHT   80          // sube de a poco: la tira consume mucho

CRGB leds[NUM_LEDS];

void ledsSetup() {
  FastLED.addLeds<WS2812, LED_PIN, GRB>(leds, NUM_LEDS);
  FastLED.setBrightness(MAX_BRIGHT);
  FastLED.clear(); FastLED.show();
}

// dibuja SIEMPRE desde START_LED:
// leds[START_LED + i] = CHSV(hue, 255, val);
// fadeToBlackBy(leds + START_LED, NUM_LEDS - START_LED, 20);
```

> Para la **matriz 20×20** (`matrix_midi_anyma`, `test_matrix_20x20`) hay un mapeo XY (serpentina) sobre el mismo arreglo, también empezando en `START_LED`.

### 6.8 Piezos (sensores de impacto)

```cpp
const uint8_t PIEZO_PINS[4] = { 4, 5, 6, 7 };   // ADC/GPIO
// Detección de golpe: ventana de pico (~15 ms) sobre analogRead, umbral mínimo,
// el pico → velocidad MIDI (40..127), con debounce ~50 ms para no retriggear.
```

---

## 7. Estrategias de código (cómo piensa este proyecto)

- **Estructura `Voice` para polifonía:** un arreglo de structs (5–16 voces) con acumulador de fase, envolvente y flags `activa/presionada`. `triggerVoz()` setea parámetros, `renderVoz()` produce 1 muestra.
- **Síntesis sin samples** (drum_machine, synth, trance): osciladores (sierra anti-alias PolyBLEP, cuadrada, triángulo, seno), ruido LCG, barridos de pitch, filtros biquad/one-pole. Todo se mezcla y se limita con un soft-limiter antes de enviar a I2S.
- **Síntesis con samples** (loaders/sequencers): los `.wav` se embeben como **arrays `PROGMEM`** (no hay carga en runtime). Estos `.ino` los **genera una webapp de `tools/`** — prefiere regenerarlos antes que editarlos a mano.
- **Secuenciador:** `bool patron[tracks][16]` recorrido por un acumulador de tempo derivado de un pot (BPM). El paso avanza contando muestras, no con `millis()`, para timing exacto.
- **Paneles/modos:** combos de 2 botones cambian de "panel"; los parámetros se **congelan** al cambiar de panel y cada pot retoma control sólo cuando se mueve (evita saltos).
- **IMU como modulador en vivo:** eje X → cutoff, eje Y → resonancia; o pico de aceleración → disparo + velocidad.
- **Sin `delay()` en el camino de audio.** Si necesitas temporizar UI, usa `millis()` fuera del render.

---

## 8. Errores comunes a evitar (checklist para la IA)

- ❌ Usar `dacWrite()` / DAC interno → ✅ usar I2S + PCM5102.
- ❌ Flash Mode **OPI** → ✅ **DIO** (si no, el audio se corta/cruje).
- ❌ Escribir en `leds[0..5]` → ✅ empezar en `START_LED (6)`.
- ❌ `delay()` dentro del render de audio → ✅ buffers DMA de 128 muestras.
- ❌ Inventar pines → ✅ usar la tabla de la sección 2.
- ❌ Olvidar `USB.begin()` con `USBMIDI` → ✅ `MIDI.begin(); USB.begin();`.
- ❌ Brillo de LEDs al máximo de entrada → ✅ subir gradual (consumo/brownout).
- ❌ Leer pots sin oversampling → ✅ promedio de 8 (ruido del ADC).
- ❌ Escribir el SSID, la contraseña del WiFi o una API key dentro del `.ino` → ✅ ponerlas en un `secretos.h` aparte (ver 4.1).
- ❌ Usar **ADC2** en un firmware con WiFi → ✅ los 4 pots ya están en ADC1 (1, 2, 8, 10); con el WiFi encendido el ADC2 no se puede leer.

---

## 9. Plantilla de encabezado obligatoria (formato proto-synth-v2)

Todo `.ino` debe empezar con un encabezado así (rellena los bloques según el firmware):

```cpp
// ==============================================================================================================================================
// PERCU-SYNTH — <NOMBRE DEL FIRMWARE> — GC Lab Chile
// ==============================================================================================================================================
// Desarrollado por: Gonzalo - GC Lab Chile
// Licencia de Software: MIT License (https://opensource.org/licenses/MIT)
// Licencia de Hardware: CERN Open Hardware Licence v2 - Permissive (CERN-OHL-P)
// REPOSITORIO: https://github.com/GC-Lab-Gonzalo/Percu-Synth
// ==============================================================================================================================================
// HARDWARE (usado por este firmware)
// ==============================================================================================================================================
// - Microcontrolador ESP32-S3
// - DAC PCM5102 vía I2S — estéreo 44.1 kHz · 16-bit |LCK -> 39, DIN -> 40, BCK -> 41|
// - IMU MPU6050 (I2C) |SDA -> 21, SCL -> 38|  (dirección 0x68)   [si se usa]
// - 5 Botones pull-up |BTN1 -> 44, BTN2 -> 42, BTN3 -> 0, BTN4 -> 45, BTN5 -> 47|
// - 4 Potenciómetros |POT1 -> ADC1, POT2 -> ADC2, POT3 -> ADC8, POT4 -> ADC10|
// - LEDs WS2812 en GPIO 46 (los LEDs 0–5 son SMD internos → siempre apagados)   [si se usa]
// ==============================================================================================================================================
// ARDUINO IDE — settings críticos
// ==============================================================================================================================================
// - Board              : ESP32S3 Dev Module
// - USB CDC On Boot    : Enabled
// - USB Mode           : USB-OTG (TinyUSB)        [si hay USB-MIDI]
// - Flash Mode         : DIO          (¡OPI rompe I2S!)
// - PSRAM              : OPI PSRAM
// - Partition Scheme   : Huge APP (3MB No OTA/1MB SPIFFS)   [si lleva samples PROGMEM]
// ==============================================================================================================================================
// LIBRERÍAS REQUERIDAS
// ==============================================================================================================================================
// - ESP32 Arduino core ≥ 3.x (incluye driver/i2s_std.h)
// - Wire.h (I2C, incluida)          [si se usa IMU]
// - USB.h + USBMIDI.h (incluidas)   [si hay USB-MIDI]
// - FastLED                          [si se usan LEDs]
// ==============================================================================================================================================
// DESCRIPCIÓN
// ==============================================================================================================================================
// <qué hace el firmware en 3–6 líneas>
// ==============================================================================================================================================
// FUNCIONAMIENTO
// ==============================================================================================================================================
// <qué hace cada botón, cada pot, el IMU, los LEDs; modo de uso paso a paso>
// ==============================================================================================================================================
```

---

## 10. Esqueleto mínimo de un firmware de audio

```cpp
// (encabezado proto-synth-v2 de la sección 9)
#include <Arduino.h>
#include <driver/i2s_std.h>
#include <math.h>

#define I2S_LCK 39
#define I2S_DIN 40
#define I2S_BCK 41
#define SAMPLE_RATE    44100
#define BUFFER_SAMPLES 128

const uint8_t BTN_PINS[5] = { 44, 42, 0, 45, 47 };
const uint8_t POT_PINS[4] = { 1, 2, 8, 10 };

i2s_chan_handle_t tx_chan;
int16_t buffer[BUFFER_SAMPLES * 2];

void i2s_init() { /* ver 6.1 */ }
int  leerPot(uint8_t pin) { uint32_t s=0; for(int i=0;i<8;i++) s+=analogRead(pin); return s>>3; }

void setup() {
  Serial.begin(115200);
  for (int i = 0; i < 5; i++) pinMode(BTN_PINS[i], INPUT_PULLUP);
  analogReadResolution(12); analogSetAttenuation(ADC_11db);
  i2s_init();
}

void loop() {
  // 1) leer botones/pots/IMU (sin bloquear)
  // 2) actualizar parámetros de síntesis
  // 3) rellenar 'buffer' con BUFFER_SAMPLES muestras estéreo
  for (int n = 0; n < BUFFER_SAMPLES; n++) {
    int16_t s = 0;              // <- tu síntesis aquí
    buffer[2*n] = s; buffer[2*n+1] = s;
  }
  size_t w;
  i2s_channel_write(tx_chan, buffer, sizeof(buffer), &w, portMAX_DELAY);
}
```

---

## 11. Firmwares de referencia que ya existen (para inspirarse)

| Firmware | Qué hace |
|---|---|
| `drum_machine_basic` | Drum machine 16 pasos con síntesis en tiempo real (sin samples) |
| `drum_poder` | Drum machine con peso, mezclada y masterizada: 12 grooves escritos a mano en compases impares (7/8, 5/8+7/8, 9/8, 13/8, 5/4, 12/8) + **reloj MIDI por el DIN-5** (Clock 24 PPQN + Start/Stop, sin notas: el bajo lo pone el sinte externo). Es la referencia para el DIN-5, para una cadena de master (sidechain → reverb → EQ tilt → compresor → limitador) y para el reparto en dos núcleos (audio en el core 1, controles en el core 0) |
| `oscilador_escalas_clock` | Dron de 4 osciladores por escala (4 pots = 4 notas, unísono + sub, IMU → filtro, intermitencia con tap tempo) + **MIDI Clock por el DIN-5** que sigue al tap y a la intermitencia (Start/Stop con BTN3, Stop+Start en cada tap). Referencia para un reloj MIDI contado en el audio y mandado desde el control, y para LEDs que siguen la envolvente del audio |
| `bajo_8_pasos` | Hecho en conjunto con los participantes del taller abierto de GC Lab en Hive Espacios. Secuenciador de bajo monofónico de 8 pasos en La pentatónica menor: 2 sierras + sub cuadrada → SVF con envolvente de filtro. Paneles A/B = notas de los pasos, panel C = volumen/velocidad/decay/cutoff, BTN5 octava. Referencia para pots por paneles que **sólo toman el control al moverse** (cambiar de panel no pisa valores) y para un secuenciador preciso a la muestra con el largo del paso fijado al empezarlo |
| `bajo_8_pasos_fsr_clock` | El mismo bajo con **un FSR en EXT1 (GPIO 3) que abre el filtro** y **MIDI Clock por el DIN-5**. Referencia para **meter un sensor externo a un parámetro** sin tocar nada de lo que ya existía: el pot sigue poniendo el reposo y el sensor viaja en el **mismo exponente** que la envolvente de filtro (cero `powf` extra), con zona muerta abajo para que soltar el sensor devuelva el sonido original. Los extremos del sensor son **lecturas medidas** y el mapeo es una recta entre ellas ⇒ la polaridad del divisor es irrelevante. El reloj se cuenta en el audio con el contador de muestras de los pasos (6 ticks por semicorchea) y se manda desde control a 1 kHz. Su tira de 121 LEDs es además la referencia de **efectos sorteados y reactivos**: 8 efectos, uno nuevo cada 4 compases y en cada Play, nunca el anterior, con paleta/dirección/parámetro sorteados; los 8 reaccionan al golpe del paso, la nota, la **envolvente real del audio** (publicada en una volátil, no imitada en el core 0) y el FSR. Al verificarlos: **el brillo total es la métrica equivocada** para "¿reacciona?" — un efecto que se comprime o se corre de color a energía constante parece muerto; hay que medir también el **gradiente espacial**. Y es la referencia de que **no todo corte de audio es presupuesto de tiempo**: acá los efectos costaban < 0,5 ms de los 16 entre frames y corrían en el otro núcleo, pero la tira cuelga del 5 V de la placa y un efecto que prende los 121 LEDs pide ~2 A y hunde el riel. Antes de buscar underrun de DMA, preguntar **cómo se alimentan los LEDs** y contar cuántos enciende el efecto a la vez; la solución es un **limitador de corriente** de la tira (`TIRA_MAX_MA`) con ataque instantáneo y recuperación lenta, porque lo que hunde el riel es el *escalón* |
| `industrial_matriz` | Base de bombo de tres bandas + bajo de `bajo_8_pasos` sobre una progresión de 4 acordes en La menor escrita en grados (el bajo sigue la fundamental; 6 líneas que no caen nunca en una negra), un pad y un pluck con **8 melodías escritas en grados del acorde** (las notas sorteadas por paso no hacían melodía), más un **secuenciador de percusión industrial en paralelo** de 6 pistas (hat, martillo, pistón, clap, hat abierto, tom; nada de ráfagas de ruido que crecen, suenan a ola; nada de ráfagas de clics de ruido, que suenan a clipeo; nada de parciales metálicos afinados: sonaban a olla) cuyo ciclo dura 16 o 32 pasos y se calcula siempre desde el paso de la base (los ciclos de 10–24 pasos que había antes se cortaban cada 4 compases y no calzaban con el bajo). En el POT4 del menú hay un oscilador continuo (dos sierras con detune leve + reverb) que barre dos octavas cuyas puntas son la tónica del banco. La densidad (POT4) usa una **prioridad por paso**: subir el pot agrega golpes sin cambiar los que ya estaban. Es la referencia para una **matriz WS2812 32×8** encadenada a los 6 LEDs de la placa, con el mapeo XY en 4 constantes (columnas/filas, serpentina, espejos), prueba de orientación al encender, 8 escenas psicodélicas en tiempo musical sorteadas con su paleta y limitador de corriente (`MATRIZ_MAX_MA`). Audio en el core 1, controles y matriz en dos tareas en el core 0 |
| `la_partida` | Toca "La partida" (Víctor Jara) desde sus 3 pistas MIDI (`cancion.h`, sacado del `.als` de Ableton con `extraer_cancion.py`): lead filtrado con vibrato / bajo sierra + cuadrada desafinadas / pluck electrónico con filtro por voz. BTN1 play/stop + panel general, BTN2/3/4 paneles de síntesis de cada pista. Referencia para **reproducir un MIDI preciso a la muestra** (acumulador 32.32 de ticks por muestra) y para **polifonía sin robo de voz** (una voz por altura) |
| `synth_basico` | Synth polifónico 5 voces con morphing seno→cuadrada→sierra |
| `trance_imu` / `trance_imu_leds` | Secuenciador de trance polifónico, filtro por IMU (+ LEDs internos como visualizador) |
| `MIDI_Drum` | Controlador USB-MIDI con botones + piezos + IMU (velocidad por movimiento) |
| `drum_midi_leds` | Drum MIDI + show de LEDs cinemático |
| `step_sequencer_midi` | Secuenciador de samples 6×16 + MIDI Clock Master + edición en vivo por Web MIDI |
| `matrix_midi_anyma` | Secuenciador electro + MIDI Clock Master + motor visual 2D para matriz 20×20 |
| `impact_chimes` / `seismic_drone` | El acelerómetro detecta golpes/vibración del piso → notas de escala / dron grave |
| `laser_chimes` | Mismo instrumento que `impact_chimes` pero disparado por un **LDR + láser** en el sensor externo A (GPIO 3): al cortar el haz suena una nota. Es la referencia para leer un sensor analógico externo (tarea a 1 kHz en el core 0, límites de lectura como variables) |
| `mezclador_pistas` | Canción en **4 pistas** desde un WAV intercalado en la **microSD** (mismo SPI que `grabador_campo`) → filtro y volumen por pista → DAC, y análisis por pista (golpes, nivel) por USB serial para las visuales de Resonancia. Referencia para **leer audio largo de la tarjeta sin cortes**: colchón de 4 s en PSRAM que llena una tarea del core 0 y vacía el audio en el core 1 |
| `trance_pistas` | El mismo instrumento que `mezclador_pistas` (bancos, filtro/resonancia/efecto rítmico por pista, misma línea serial para Resonancia) pero **sintetizado, sin microSD**: trance con peso: las voces de batería de `drum_poder`, el bajo de `bajo_8_pasos`, un riff que sólo toca notas del acorde y un pad que crece por secciones con stabs rave; 6 temas de 32 compases (A · A' · ruptura · drop) en menor natural consonante. Se instala desde Resonancia con ESP Web Tools. Referencia para **un secuenciador de 4 pistas con temas escritos como texto** y golpes exactos que salen del secuenciador, no de un detector |
| `oled_video_techno` | Un video vertical en la **OLED SSD1306 girada (64×128)**, amarrado al tempo de un secuenciador techno (bombo de tres bandas + línea ácida con el filtro en los 4 pots + hats). Referencia para **la pantalla OLED**: SSD1306 manejada directo por `Wire` (sin librerías) en SDA 21 / SCL 38, cuadros de 1024 bytes guardados ya en el orden de memoria de la pantalla (los genera `convertir_video.py`), giro de 180° por hardware (`0xA0/0xC0`), tarea de pantalla en el core 0 con prioridad más baja que el control, y **video sincronizado al audio**: el audio publica la posición en cuadros y la pantalla dibuja el que toque, saltándose los que no alcance |
| `voz_fx` | Procesador de voz en tiempo real: micrófono INMP441 a 44.1 kHz con el reloj del DAC (sin remuestrear, ~12 ms) → 11 efectos (vocoder, autotune, robot, pitch, armonizador, eco, catedral…). BTN1 efecto, POT4 siempre volumen. Referencia para la cadena de voz: pasa-altos → ganancia → **puerta antes del efecto** (las colas no se cortan) → limitador → 13 kHz |
| `secuenciador_melodico` / `secuenciador_melodico_cromatico` | Aporte de Nicolás Martínez: secuenciadores de 16 pasos sobre la librería **ESP32Synth** (no el motor I2S escrito a mano), uno monofónico en los 7 modos griegos y otro polifónico sobre 12 notas cromáticas, cada uno con su webapp por Web Serial para editar los pasos |
| `laser_midi_wifi` | **ESP32-C3** (no PercuSynth) que manda MIDI por **WiFi con RTP-MIDI**; nació experimentando con malabarismo (detectar clavas en el aire). Hoy es la prueba de enlace (una nota por segundo). Referencia para MIDI inalámbrico: `WiFi.setSleep(false)` obligatorio (si no, jitter), punto de acceso propio para tocar, redes en `secretos.h` |
| `grabador_campo` | Micrófono INMP441 → ganancia/filtro/EQ/efecto en vivo → **microSD** (SPI en GPIO 14 SCK · 15 MOSI · 16 MISO · 17 CS). Graba el procesado (estéreo 24 bit) y el crudo (mono 24 bit) alineados. Referencia para **grabar a tarjeta sin cortar el audio**: colchón en PSRAM lleno por la tarea de audio (core 1) y vaciado por otra tarea en el core 0, cabeceras WAV reescritas cada 5 s |
| `test_leds` / `test_imu` / `test_matrix_20x20` | Sketches de prueba de cada periférico |

> Las webapps de `tools/` (sample_loader, loop_loader, midi_sampler, etc.) **generan `.ino` con samples embebidos**; si necesitas samples, conviene usarlas en vez de pedir a la IA que invente arrays gigantes.

---

*Documento mantenido por GC Lab Chile. Pinout y settings válidos para el hardware PercuSynth (ESP32-S3 + PCM5102). Ante cualquier conflicto, manda la placa física: el pinout está soldado.*

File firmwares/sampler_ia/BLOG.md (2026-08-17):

# SAMPLER IA — material para el blog de GC Lab Chile

> **Para qué es este archivo:** insumo completo para escribir la página de blog en la web de
> GC Lab. Contiene la historia real del desarrollo (con los errores incluidos), las decisiones
> técnicas y por qué se tomaron, cifras verificadas, e ideas para el componente interactivo.
> Todo lo que está aquí ocurrió de verdad en la sesión de desarrollo — no inventar cifras ni
> agregar datos que no estén en este documento.

---

## 1. Qué es el proyecto (el pitch)

**Un sampler al que le pides los sonidos hablando.** Mantienes un botón, dices *"quiero un golpe
metálico oxidado con cola larga"*, y el PercuSynth lo genera con IA, lo carga en un slot y te lo
deja disparable al instante. Sin computador: el ESP32-S3 habla directo con las APIs.

La cadena completa:

```
BTN1 (mantener) → mic INMP441 → Whisper (transcribe el español)
                → GPT-4o-mini (lo convierte en prompt de efecto de sonido EN INGLÉS,
                               y decide duración y si conviene que loopee)
                → ElevenLabs /v1/sound-generation (genera el audio)
                → recorte de silencio + normalizado + micro-fades → slot en PSRAM
BTN2/3/4 → disparo instantáneo · mantener = loop/textura · BTN5 → secuenciador de 32 pasos
```

Es la fusión de tres piezas que ya existían en el ecosistema PercuSynth:
- **asistente_ia** — la cadena de voz (mic → Whisper → GPT por WiFi)
- **sample_loader** — el motor de disparo (resampleo por pitch, envolventes, pool de voces)
- **trance_imu** — el filtro biquad resonante controlado por el IMU

Moraleja para el blog: *casi nada se escribió desde cero; el valor estuvo en combinar piezas
probadas y resolver lo nuevo (la generación en vivo).*

## 2. La historia, en orden real (con los tropiezos)

Esto le da honestidad al blog. El proceso NO fue lineal.

### 2.1 La pregunta equivocada que llevó a la respuesta correcta
La idea nació preguntando si se podía usar la **API de música** de ElevenLabs. Resultó ser la
herramienta equivocada: devuelve canciones enteras (mínimo 3 s, hasta 10 min, archivos de MB,
cerradas, sin control musical posterior). El descubrimiento clave fue que el endpoint correcto
para un sampler era otro: **`/v1/sound-generation`** (Text-to-Sound Effects) — de 0.5 a 30 s,
con flag de `loop` para texturas sin costura y salida en **PCM crudo** que entra casi directo al
I2S del ESP32, sin decodificar MP3.

### 2.2 El plan Starter y el fallback µ-law
El formato limpio (`pcm_22050`) exige plan Pro de ElevenLabs, y el plan disponible era
**Starter**. La solución: *fallback automático* a **`ulaw_8000`**, disponible en todos los
planes. µ-law es un formato telefónico de 8 bits que se decodifica en ~10 líneas de C, sin
librerías. Suena lo-fi (8 kHz), pero para percusión y texturas ese carácter hasta suma.
El firmware intenta PCM primero y cae solo a µ-law si la key lo rechaza.

### 2.3 Primer bug: el preprocesador de Arduino
Primer intento de compilar: `'SfxSpec' does not name a type`. Arduino genera los prototipos de
todas las funciones **al inicio del archivo**, antes de donde estaban declaradas las structs.
Solución: declarar las structs arriba del todo. Clásico de Arduino que todo maker se topa alguna
vez.
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

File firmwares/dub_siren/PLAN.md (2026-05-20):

# dub_siren — Plan de implementación

Sintetizador "sirena dub" para PercuSynth (ESP32-S3). El sample se embebe en el firmware en **compile-time** mediante una **app web generadora de .ino** (patrón establecido por `synth_studio` y `loop_loader`). Una vez flasheado, el ESP32 corre standalone: la web app no se vuelve a usar hasta querer un nuevo sample.
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

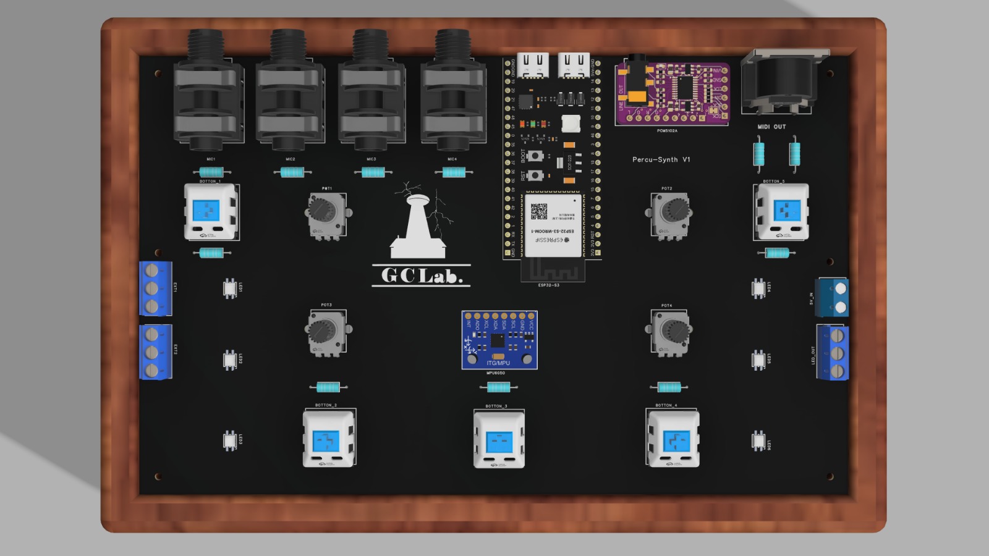
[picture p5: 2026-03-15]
Imagenes/percu-synth modelo 3d.jpeg

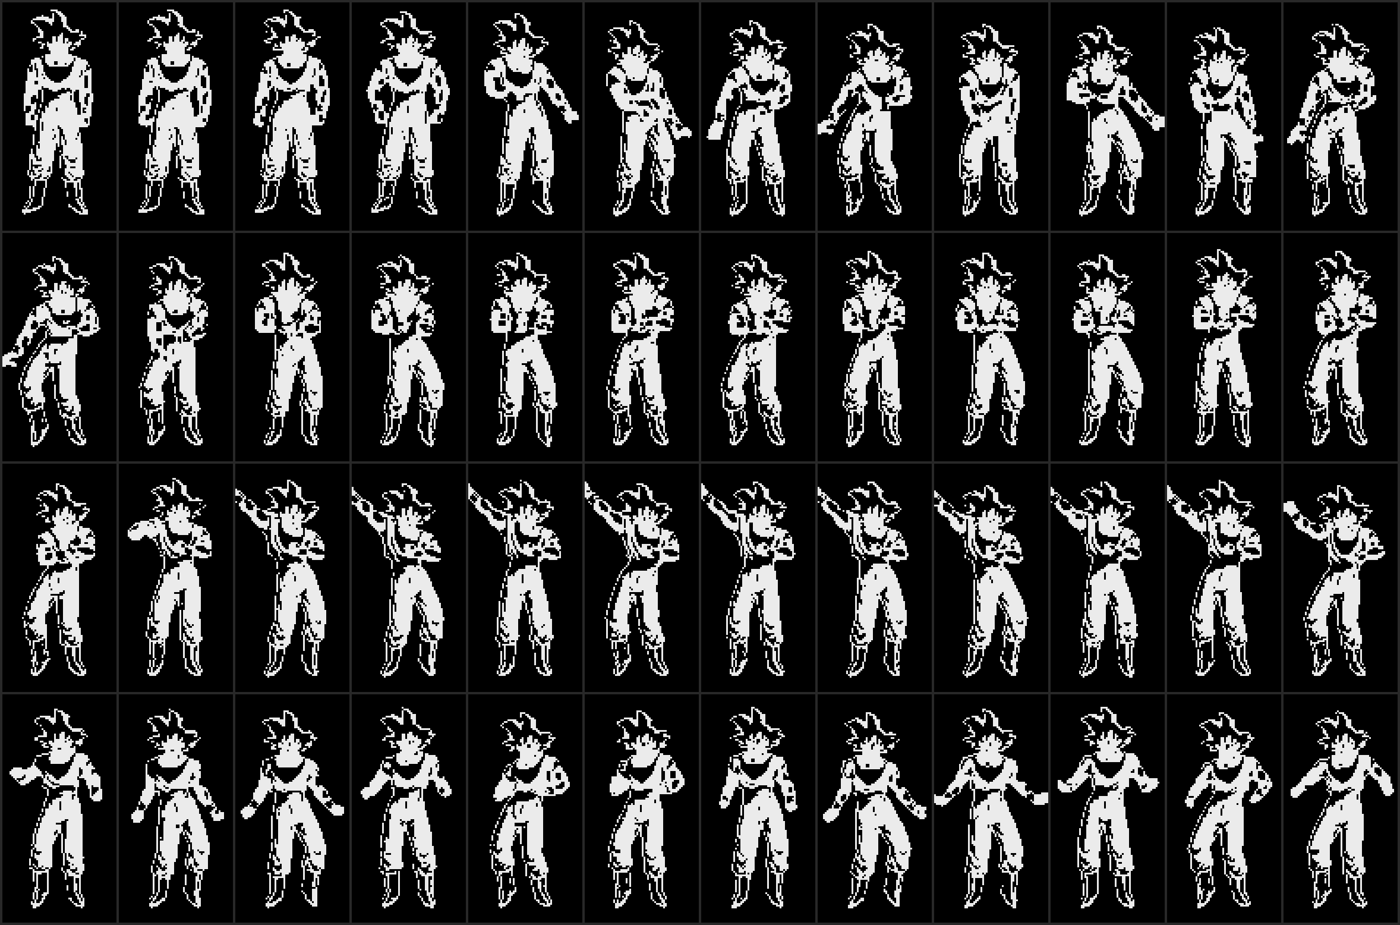
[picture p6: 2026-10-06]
firmwares/oled_video_techno/video_vista_previa.png

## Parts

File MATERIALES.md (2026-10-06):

# PercuSynth — Lista de materiales

Todo lo necesario para armar un PercuSynth con la **placa V2.0**. La PCB fabricada es **opcional**: el
mismo circuito se puede armar en protoboard o en placa perforada, y corre exactamente el mismo firmware.

> Los componentes se listan con su **término de búsqueda** en vez de un enlace, porque los enlaces
> de tienda mueren y el término de búsqueda no. Con ese texto los encuentras en AliExpress,
> Mouser, o la tienda de electrónica de tu ciudad. Si igual quieres los enlaces que usamos para
> comprar la V2.0 en AliExpress, están en [`Hardware/LISTA_ALIEXPRESS_Percusynth.txt`](Hardware/LISTA_ALIEXPRESS_Percusynth.txt).

> **Qué cambió de la V1.1 a la V2.0 (septiembre 2026):** cada entrada de piezo lleva ahora un
> **diodo Schottky 1N5817**, un **condensador de 10 nF** y una resistencia de **100 kΩ** (antes era
> sólo una de 1 MΩ). Además la placa trae sitio para el **micrófono INMP441** y un conector para
> una **pantalla OLED** opcional. Si tienes una placa V1.1, sigue funcionando igual: sólo cambia
> lo que va en las entradas de piezo.

---

## 1. Módulos

| # | Componente | Cant. | Buscar como | Notas |
|---|---|---|---|---|
| 1 | **ESP32-S3 DevKitC-1 N16R8** | 1 | `ESP32-S3-DevKitC-1 N16R8` | El cerebro. **Tiene que ser S3** — el ESP32 clásico no sirve. La PSRAM (`R8`) hace falta para los firmwares con samples e IA. Trae dos puertos USB-C |
| 2 | **DAC PCM5102A** | 1 | `GY-PCM5102 I2S DAC` | La salida de audio estéreo por I2S. Ojo: es PCM510**2**A |
| 3 | **IMU MPU6050** | 1 | `GY-521 MPU6050` | Acelerómetro + giroscopio, por I2C |
| 4 | **Micrófono INMP441** | 1 | `INMP441 I2S microphone module` | Micrófono I2S. Lo usan los firmwares de IA (asistente, sampler, compositor). Va montado en la placa desde la V2.0 |

## 2. Conectores

| # | Componente | Cant. | Buscar como | Notas |
|---|---|---|---|---|
| 5 | **Jack 6.3 mm hembra mono, montaje en PCB** | 4 | `6.35mm mono jack socket PCB` (huella NMJ4HFD2) | Entradas MIC1–MIC4: es por donde entran los piezos |
| 6 | **Conector DIN-5 hembra para PCB** | 1 | `DIN 5 pin female PCB socket MIDI` | Salida MIDI OUT |
| 7 | **Bornera de tornillo para PCB, 3 vías, paso 5.08 mm** | 3 | `KF301 3P 5.08mm` | Sensores externos EXT1 / EXT2 y salida a tira LED |
| 8 | **Bornera de tornillo para PCB, 2 vías, paso 5.08 mm** | 1 | `KF301 2P 5.08mm` | Entrada de 5 V |

> **El nombre del conector 7/8:** en español es *bornera* o *bloque terminal de tornillo para PCB*;
> en inglés, *PCB screw terminal block*. La placa V2.0 lleva borneras **KF301 de paso 5.08 mm**
> (la separación entre pines); con otro paso no entran en los agujeros.

## 3. Controles y luces

| # | Componente | Cant. | Buscar como | Notas |
|---|---|---|---|---|
| 9 | **Potenciómetro 1 kΩ lineal, montaje en PCB** | 4 | `potentiometer B1K vertical PCB 9mm` | **Lineal (B)**, no logarítmico. El valor no es crítico: 1 k, 10 k o 50 k funcionan igual como divisor hacia el ADC. Que sean todos iguales. Huella de 9 mm vertical (R09V) |
| 10 | **Switch de teclado mecánico (compatible MX)** | 5 | `mechanical keyboard switch MX` | Los 5 botones. Elige el tacto que te guste (clicky, táctil o lineal) |
| 11 | **Keycaps** | 5 | `MX keycaps` | Las tapas de los switches |
| 12 | **LED WS2812B SMD 6028** | 6 | `WS2812B 6028` | Los 6 LEDs de la placa. Son los índices 0–5, por eso los firmwares dibujan desde `START_LED = 6`. ⚠️ La huella de la V2.0 es **6028** (6.0 × 2.8 mm), no 3528: confirmar contra el LED que se compró |

## 4. Componentes discretos

Todas las resistencias son de **1/4 W axiales**. Los diodos y el electrolítico **tienen polaridad**;
las resistencias y los cerámicos no.

| # | Componente | Cant. | En la placa | Notas |
|---|---|---|---|---|
| 13 | **Resistencia 220 Ω** | 2 | R10, R11 | Circuito de salida MIDI |
| 14 | **Resistencia 1 MΩ** | 5 | R1–R5 | Pull-up de los 5 botones |
| 15 | **Resistencia 100 kΩ** | 4 | R6–R9 | Carga de cada entrada de piezo. **Nuevo en V2.0** (antes 1 MΩ) |
| 16 | **Diodo Schottky 1N5817** | 4 | D1–D4 | Protección de cada entrada de piezo. Encapsulado **DO-41** (axial). Buscar como `1N5817 DO-41`. La **franja** del cuerpo es el cátodo y va donde lo marca la serigrafía. **Nuevo en V2.0** |
| 17 | **Condensador cerámico 10 nF** | 4 | C2–C5 | Filtro de cada entrada de piezo. Código `103`, radial, paso 2.54 mm. Buscar como `10nF ceramic capacitor 103`. Sin polaridad. **Nuevo en V2.0** |
| 18 | **Condensador electrolítico 100 µF** | 1 | C1 | Desacoplo de la alimentación del MPU6050. Va en 3.3 V, así que sirve cualquiera de **6.3 V o más** (el original es de 16 V). Diámetro 5 mm, paso 2 mm. La pata larga (+) va al 3.3 V |

> **Por qué el piezo lleva diodo y condensador.** Un disco piezoeléctrico golpeado genera picos de
> decenas de voltios, de las dos polaridades. El ADC del ESP32-S3 sólo lee entre 0 y 3.3 V y no
> tolera tensión negativa. El **100 kΩ** descarga el piezo a masa, el **1N5817** recorta el semiciclo
> negativo (un Schottky conduce desde ~0.3 V, antes de que el pin sufra) y el **10 nF** estira el
> golpe unos milisegundos para que el ADC alcance a verlo aunque el `loop()` esté ocupado con el
> audio. Los tres van en paralelo entre la señal del piezo y GND. En la V1.1 sólo había la
> resistencia, y los golpes fuertes se perdían o llegaban recortados.

## 5. Pin headers

Los módulos **no se sueldan directo a la placa**: se montan sobre tiras hembra, así se pueden
sacar y reutilizar.

| # | Componente | Cant. | Para |
|---|---|---|---|
| 19 | Tira hembra 22 pines | 2 | ESP32-S3 DevKitC-1 (44 pines, 22 por lado) |
| 20 | Tira hembra 8 pines | 1 | MPU6050 |
| 21 | Tira hembra 6 pines | 1 | PCM5102A |
| 22 | Tira hembra 3 pines | 1 | PCM5102A |
| 23 | Tira hembra 4 pines | 1 | Conector OLED. Sólo si vas a poner la pantalla (ver opcionales) |

> El **INMP441** es la excepción: va soldado con sus propios pines (dos filas de tres) en el círculo
> que marca la serigrafía, junto al ESP32.

> Se compran como `2.54mm female pin header strip` y se cortan al largo necesario. Los módulos
> suelen venir con sus tiras **macho** incluidas; si no, agrega `2.54mm male pin header`.

## 6. Para que suene y funcione

| # | Componente | Cant. | Notas |
|---|---|---|---|
| 25 | Cable **USB-C de datos** | 1 | De datos, no de sólo carga. Alimenta y programa la placa |
| 26 | Salida de audio | — | Parlante amplificado, interfaz de audio, audífonos o entrada de línea del PC |

## 7. Opcionales (según lo que quieras hacer)

| Componente | Buscar como | Para qué |
|---|---|---|
| **Discos piezoeléctricos** con plug 6.3 mm | `piezo disc transducer 27mm` | Pads de percusión por impacto. Se conectan a MIC1–MIC4 |
| **Pantalla OLED 0.96" I2C (SSD1306, 4 pines)** | `0.96 OLED I2C SSD1306 4 pin` | Va en el conector OLED de la V2.0 (mismo bus I2C del MPU6050: SDA 21 / SCL 38). La usa `oled_video_techno` (video vertical con la pantalla de lado). Revisa que el orden de pines del módulo (GND / VCC / SCL / SDA) coincida con la serigrafía |
| **Tira LED WS2812B** | `WS2812B LED strip` | Visualizadores. El largo lo eliges tú (30, 60, 68, 144…) y se ajusta en el firmware |
| **LDR + resistencia 220 Ω** | `LDR 5528 photoresistor` | Sensor externo. Es lo que usa `laser_chimes` para detectar el corte de un láser |
| **Cable MIDI DIN-5** | `MIDI cable DIN 5 pin` | Para conectar la salida MIDI a un sinte o caja de ritmos externa |
| **Batería USB (power bank)** | — | Para tocar sin computador |
| **Caja de madera o impresa en 3D** | — | El PercuSynth de las fotos va montado en una caja de madera |

## 8. Herramientas (sólo si vas a soldar)

- Soldador de temperatura regulable y su soporte
- Estaño con núcleo de resina, y flux
- Esponja o lana de bronce para limpiar la punta
- Alicate de corte y pinza
- Malla desoldadora o chupa-estaño
- Multímetro — para revisar continuidad y cortos **antes** de conectar el USB
- Buena luz, y lupa si vas a soldar los LEDs SMD

---

## Los tres caminos para armarlo

| | PCB fabricada | Protoboard | Placa perforada |
|---|---|---|---|
| Soldadura | Sí | No | Sí |
| Tiempo hasta tenerlo | Lo que demore el envío | Inmediato | Días |
| Robustez | Alta | Baja (se sueltan los cables) | Media-alta |
| LEDs SMD 0–5 | Los trae | No existen | No existen |

**Si no usas la PCB:** los firmwares con luces empiezan a dibujar en `START_LED = 6` porque asumen
los 6 LEDs SMD de la placa. En un armado propio la tira empieza en el índice 0, así que cambia esa
constante (o suelda 6 LEDs de sacrificio al inicio de la tira).

También cambian los componentes que necesitas: en protoboard no hacen falta las borneras, los jacks
de 6.3 mm ni los LEDs SMD — los sensores se conectan con cables directo a los pines. Lo que **sí**
conviene mantener aunque no uses la PCB es el trío de cada piezo (100 kΩ + 1N5817 + 10 nF a GND):
sin él un golpe fuerte puede dañar el pin del ESP32.

## Pedir la PCB en JLCPCB

1. Descarga el repositorio (GitHub → `Code` → `Download ZIP`).
2. En `Hardware/` está `Gerber_Percu-synth_1-PCB_PCB_Percu-synth_V2.0.zip`. **Ese ZIP se sube tal
   cual, sin abrirlo.** (El `V1.1` sigue en la carpeta sólo como referencia de las placas antiguas;
   para fabricar usa la V2.0.)
3. En jlcpcb.com, *Add gerber file*.
4. Las opciones que importan: cantidad (el mínimo suele ser 5), color de máscara, espesor y acabado.
   El resto se deja como viene.
5. Elige el envío según tu país mirando el plazo real antes de pagar.

La placa mide **200 × 125 mm**.

---

## Pinout de referencia

Para armarlo sin PCB, esta es la única tabla que importa:

| Señal | Pin ESP32-S3 |
|---|---|
| I2S LCK (LRCK) → PCM5102A | 39 |
| I2S DIN (DATA) → PCM5102A | 40 |
| I2S BCK (BCLK) → PCM5102A | 41 |
| Botones 1–5 | 44, 42, 0, 45, 47 |
| Potenciómetros 1–4 | ADC 1, 2, 8, 10 |
| Piezos 1–4 (MIC1–MIC4) | ADC 4, 5, 6, 7 |
| Sensores externos A / B | ADC 3 / 9 |
| Datos LED WS2812 | 46 |
| MIDI DIN-5 TX | 43 |
| I2C SDA / SCL (MPU6050 y OLED) | 21 / 38 |
| INMP441 WS / SCK / SD | 11, 12, 13 |

⚠️ **BTN3 es el GPIO 0**, que además es el botón de boot: funciona como botón normal, pero no lo
dejes apretado al energizar.

---

*GC Lab Chile — PercuSynth. Lista al día con el esquemático V2.0 (2026-09-04). Los ⚠️ son datos por confirmar.*

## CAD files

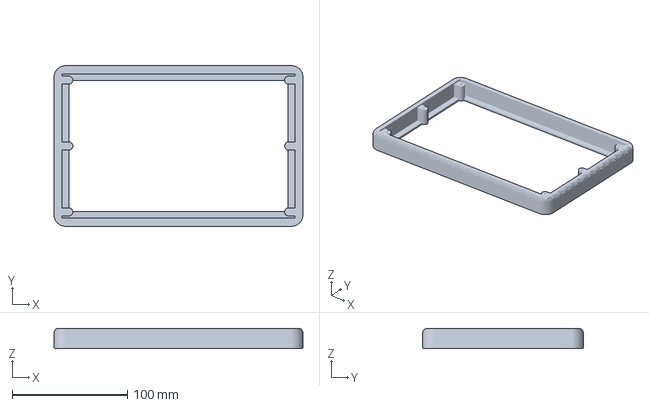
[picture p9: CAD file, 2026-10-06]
Hardware/base_3d/base_percusynth_v2.3mf
215.8 x 139.2 x 17.6 mm

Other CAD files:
Hardware/base_3d/base_percusynth_v2.stl

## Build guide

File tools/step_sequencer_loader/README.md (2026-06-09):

# step_sequencer_loader — Secuenciador + remote MIDI en vivo

Webapp con **doble personalidad**:

1. **Generador de firmware** — cargas 6 samples de drum kit, descargas el `.ino` listo para flashear con el secuenciador embebido.
2. **Control remoto en vivo** — una vez flasheado, te conectas al PercuSynth vía Web MIDI y editas el patrón, FX y transport en tiempo real. **El PercuSynth queda como MIDI CLOCK MASTER**, así que mientras editas desde la web también puedes enganchar un DAW como esclavo.

Hermana del firmware `firmwares/step_sequencer_midi/` — los dos son las dos mitades del mismo sistema.

## Cómo correrla

Doble-click sobre `index.html`. Requiere **Chrome o Edge** (Web MIDI no existe en Firefox/Safari).

```bash
# O servida por HTTP:
cd tools/step_sequencer_loader
python -m http.server 8000
```

## Cómo se comunica con la placa

**Web MIDI sobre USB** (no Web Serial). Cuando conectas el PercuSynth al PC aparece como dispositivo MIDI nativo.

| Dirección  | Canal | Mensaje | Significado |
|---|---|---|---|
| Web → ESP  | 16 | `NoteOn note=track*16+step vel` | Editar celda del patrón (vel 0 = off) |
| Web → ESP  | 16 | `NoteOn note=96..101 vel>0` | Mute toggle de tracks T0..T5 |
| Web → ESP  | 16 | `NoteOn note=120/121/122` | PLAY / STOP / RESET |
| Web → ESP  | 16 | `CC 20..30` | BPM, swing, pitch, HPF, vol, LPF, **delay**, **fill**, reverse, **beat-repeat**, **drop** |
| Web → ESP  | 10 | `NoteOn 36/38/42/46/49/51` | Trigger manual de track (GM drum) |
| ESP → Web  | - | `0xF8` Clock 24 PPQ | Sincronización |
| ESP → Web  | - | `0xFA / 0xFC` Start / Stop | Transport |
| ESP → Web  | 16 | `NoteOn note=100+step` | "Voy en este paso" → la webapp resalta |
| ESP → Web  | 16 | `CC echo` | Pot local cambió → webapp actualiza slider |

Toda la lógica MIDI completa está documentada en el header de [`firmwares/step_sequencer_midi/step_sequencer_midi.ino`](../../firmwares/step_sequencer_midi/step_sequencer_midi.ino).

## Flujo típico

### Primera vez (cargar samples)

1. Abrir `index.html` en Chrome.
2. Pestaña **SAMPLES & FIRMWARE** → cargar 6 samples (MP3/WAV/OGG) en los 6 slots, **o grabarlos con `● REC`** desde el micrófono del PC (tope 8 s, se normaliza y se hornea igual que un archivo).
   - **`✂` Recortar**: abre un editor con la onda en grande y dos manijas (inicio/fin) para dejar solo la parte útil. Botón **AUTO SILENCIO** recorta el silencio de los extremos, **▶ ESCUCHAR** prueba el recorte antes de aplicar.
3. **⬇ DESCARGAR .INO** → guarda `step_sequencer_midi.ino`.
4. Arduino IDE → ESP32S3 Dev Module → **USB Mode: USB-OTG (TinyUSB)** · **USB CDC On Boot: Disabled** · **Flash Mode: DIO** (no OPI) → upload.

### Sesión en vivo

1. Conectar el PercuSynth por USB → aparece como dispositivo MIDI.
2. **▶ HABILITAR WEB MIDI** → seleccionar el PercuSynth en INPUT y OUTPUT → **CONECTAR**.
3. **↑ PUSH PATRÓN** envía el patrón local al ESP (la primera conexión).
4. Click en las celdas de la grilla 6×16 → edita el patrón **mientras suena**.
5. Sliders BPM / SWING / PITCH / HPF / LPF / VOL / **DELAY** + toggles FILL / BEAT REP / REVERSE / DROP → cambian FX en vivo.
6. **PLAY** desde la web manda `0xFA` → el ESP arranca el clock master → un DAW conectado al mismo puerto MIDI también arranca. Sin hardware, la app igual anima los pasos con su reloj interno.

### Efectos

- **Swing** — shuffle real: retrasa las semicorcheas impares.
- **Delay** — eco sincronizado a 1/8 del BPM; una sola perilla controla mezcla + feedback.
- **Fill** — roll de caja por encima del patrón (para rellenos).
- **Beat Repeat** — repite el paso actual rápido (glitch), congelando el avance.
- **Reverse** — reproduce los samples al revés.
- **Drop** — silencia el master mientras se mantiene (builds/bajadas).

### Mientras tanto, el ESP es autónomo

- Los pots locales también editan FX (con histéresis para no pisarse con la web): POT0=BPM · POT1=LPF · POT2=DELAY · POT3=VOL.
- **BTN1 = PLAY/STOP · BTN2 = Fill (hold) · BTN3 = Beat Repeat (hold) · BTN4 = Reverse (toggle) · BTN5 = Drop (hold)**.
- Si desconectas el USB el patrón sigue sonando hasta que cortas la corriente.

## Limitaciones

- Web MIDI **solo en Chrome y Edge**.
- 6 tracks × 16 steps fijos.
- Los samples se hornean en el firmware → cambiar el kit = regenerar y re-flashear.
- Patrón se puede exportar/importar como `.json` para backup.

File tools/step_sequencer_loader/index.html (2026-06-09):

PERCUSYNTH STEP SEQUENCER · LIVE

desconectado

MIDI ▶ HABILITAR IN OUT CONECTAR ↑ PUSH PATRÓN

SECUENCIADOR SAMPLES & FIRMWARE

▶ PLAY ■ STOP ⟲ RESET CLEAR EJEMPLO RANDOM STEP —/16

PATRÓN · 6×16 — click on/off · click nombre mute

SÍNTESIS & FX — monitor en vivo (CC ch16)

BPM 120

SWING 0%

PITCH 1.00×

HPF 20Hz

LPF 12kHz

VOL 60%

DELAY off

FILL OFF

BEAT REP OFF

REVERSE OFF

DROP OFF

SAMPLES (carga MP3/WAV/OGG por pista)

Los samples se hornean en el firmware. Después de cargar todos, genera un nuevo .ino y flashea.

GENERAR FIRMWARE

⬇ DESCARGAR .INO ⬇ PATRÓN JSON ⬆ IMPORTAR JSON

⚠ Arduino IDE → Tools: Board ESP32S3 Dev Module · USB Mode USB-OTG (TinyUSB) · USB CDC On Boot Disabled · Flash Mode DIO (NO OPI) → Upload.

### RECORTAR SAMPLE

✕

Arrastra las manijas ◄ inicio y fin ► para dejar solo la parte útil.

INICIO 0.00s FIN 0.00s DURACIÓN 0.00s

AUTO SILENCIO ▶ ESCUCHAR RESET CANCELAR ✂ APLICAR

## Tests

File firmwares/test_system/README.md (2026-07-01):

# test_system — Monitor de sistema del PercuSynth

Firmware de **diagnóstico** que vuelca por el Monitor Serie el estado en vivo de **todos**
los componentes del PercuSynth en una sola pantalla, y permite lanzar auto-tests de
audio y luces escribiendo comandos. Úsalo para verificar una placa recién armada o
depurar una conexión sospechosa antes de cargar un firmware musical.

## Qué monitorea (cada ~250 ms)

| Bloque | Qué muestra |
|---|---|
| `IMU`  | WHO_AM_I (0x68 = OK) + aceleración (g), giro (°/s) y temperatura (°C) |
| `BTN`  | Estado de los 5 botones: `PUL` (pulsado) / `---` (suelto) + su GPIO |
| `POT`  | Lectura cruda `0..4095` + porcentaje de los 4 potenciómetros |
| `PZ` | Lectura cruda de los 4 piezos (golpéalos para ver el pico) |
| `EXT`  | Lectura cruda de los 2 sensores externos (A/B) |

## Comandos (escribe la letra + Enter en el Monitor Serie)

| Tecla | Acción |
|---|---|
| `a` | **Test de audio**: 3 beeps (440/660/880 Hz) por el DAC PCM5102 |
| `l` | **Test de LEDs**: barrido R/G/B por la tira WS2812 *(requiere `ENABLE_LED_TEST = 1`)* |
| `p` | Pausa / reanuda el volcado continuo (para leer con calma) |
| `h` | Ayuda |

## Flags de compilación (arriba del `.ino`)

```c
#define ENABLE_AUDIO_TEST 1   // test de tono I2S (solo core, sin libs externas)
#define ENABLE_LED_TEST   0   // test de tira WS2812 (REQUIERE instalar FastLED)
```

- El test de audio usa solo el core de ESP32 (`driver/i2s_std.h`), así que compila tal cual.
- El test de LEDs está **desactivado por defecto** para no exigir FastLED. Si lo activas,
  ajusta `NUM_LEDS` al largo real de tu tira.

## Arduino IDE — settings críticos

- **Board**: ESP32S3 Dev Module
- **USB CDC On Boot**: Enabled
- **Flash Mode**: **DIO** (necesario para que el audio I2S funcione en este hardware)
- **Monitor Serie**: 115200 baudios

## Pinout usado

| Componente | Pines |
|---|---|
| IMU MPU6050 (I2C) | SDA 21, SCL 38 (dir. 0x68) |
| Botones | BTN1→44, BTN2→42, BTN3→0, BTN4→45, BTN5→47 |
| Potenciómetros | POT1→GPIO1, POT2→GPIO2, POT3→GPIO8, POT4→GPIO10 |
| Piezos | PZ1→GPIO4, PZ2→GPIO5, PZ3→GPIO6, PZ4→GPIO7 |
| Sensores externos | EXT_A→GPIO3, EXT_B→GPIO9 |
| DAC PCM5102 (I2S) | LCK 39, DIN 40, BCK 41 |
| Tira LED WS2812 | DATA 46 |

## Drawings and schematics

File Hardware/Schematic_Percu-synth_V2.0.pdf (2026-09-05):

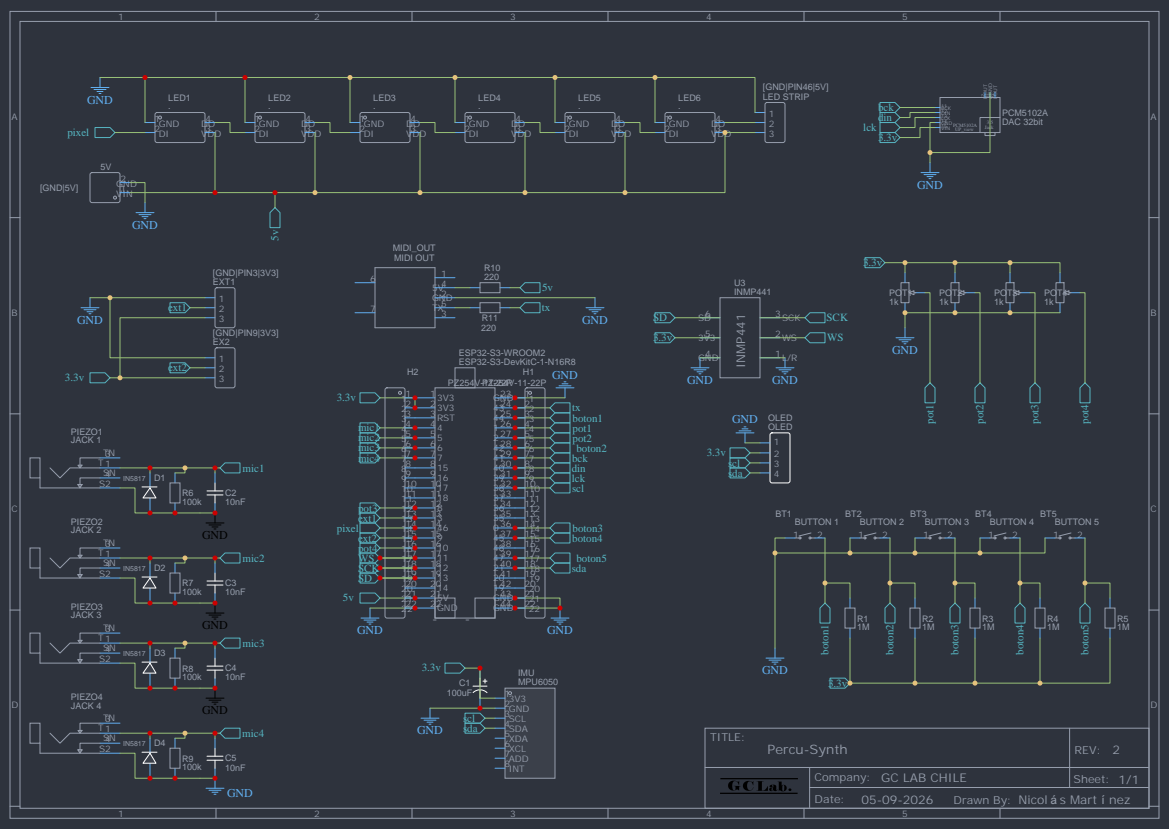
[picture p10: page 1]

Company: GC LAB CHILE

Drawn By: Nicol s Mart nez

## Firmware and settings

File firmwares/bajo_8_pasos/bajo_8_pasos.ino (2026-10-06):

// ==============================================================================================================================================
// PERCU-SYNTH — BAJO 8 PASOS (secuenciador de bajo en sierra, pentatónica menor) — GC Lab Chile
// ==============================================================================================================================================
// Desarrollado por: Gonzalo - GC Lab Chile, en conjunto con los participantes del taller abierto en Hive Espacios
// Licencia de Software: MIT License (https://opensource.org/licenses/MIT)
// Licencia de Hardware: CERN Open Hardware Licence v2 - Permissive (CERN-OHL-P)
//
// Puedes usar, modificar y distribuir este código y hardware, siempre que se mantenga
// la atribución a GC Lab Chile. Se entrega "tal cual", sin garantías de ningún tipo.
// ==============================================================================================================================================
// REPOSITORIO: https://github.com/GC-Lab-Gonzalo/Percu-Synth
// ==============================================================================================================================================
// HARDWARE (usado por este firmware)
// ==============================================================================================================================================
// - Microcontrolador ESP32-S3
// - DAC PCM5102 vía I2S — estéreo 44.1 kHz · 16-bit |LCK -> 39, DIN -> 40, BCK -> 41|
// - 6 LEDs WS2812 SMD internos de la placa |DATA -> 46| (índices 0..5 de la tira)
// - Tira WS2812 externa de 121 LEDs encadenada DESPUÉS de los 6 SMD, mismo pin |DATA -> 46|
//   (índices 6..126 · alimentación 5 V propia, GND común con la placa)
// - 5 Botones con pull-up |BTN1 -> 44, BTN2 -> 42, BTN3 -> 0, BTN4 -> 45, BTN5 -> 47|
// - 4 Potenciómetros analógicos |POT1 -> ADC1, POT2 -> ADC2, POT3 -> ADC8, POT4 -> ADC10|
// ==============================================================================================================================================
// ARDUINO IDE — settings críticos
// ==============================================================================================================================================
// - Board              : ESP32S3 Dev Module
// - USB CDC On Boot    : Enabled
// - Flash Mode         : DIO          (¡OPI rompe I2S!)
// - PSRAM              : OPI PSRAM    (no es obligatorio)
// ==============================================================================================================================================
// LIBRERÍAS REQUERIDAS
// ==============================================================================================================================================
// - ESP32 Arduino core ≥ 3.x (incluye driver/i2s_std.h)
// - FastLED (gestor de librerías de Arduino) — para los 6 LEDs de placa
// ==============================================================================================================================================
// DESCRIPCIÓN
// ==============================================================================================================================================
// Secuenciador de 8 pasos que toca un BAJO MONOFÓNICO lleno de armónicos:
//
//   · Dos sierras PolyBLEP (una desafinada +9 cents) + una cuadrada una octava abajo
//   · Saturación suave → filtro pasa-bajos resonante (SVF) con ENVOLVENTE DE FILTRO:
//     cada nota abre el filtro y se cierra con el decay → el "pluck" típico de bajo
//   · Envolvente de amplitud: ataque de 2 ms + decay exponencial (pot)
//   · Todas las notas en LA PENTATÓNICA MENOR (La · Do · Re · Mi · Sol), 2 octavas
//
// Como son 8 notas y hay 4 pots, los pots trabajan por PANELES. Al cambiar de panel
// los pots NO pisan nada: un parámetro sólo cambia cuando MUEVES su pot (desde ese
// momento la posición física del pot es el valor). Así saltar de panel nunca cambia
// las notas que ya dejaste.
//
// ARQUITECTURA: el audio corre en su propia tarea fijada al CORE 1 y los controles
// (botones, pots, LEDs) en una tarea en el CORE 0 a 1 kHz. La tarea de control sólo
// escribe pedidos (notas, parámetros, play) que el audio lee en el borde de un buffer
// o al empezar cada paso. Sin Serial: un print por USB CDC bloquea y vacía el DMA.
// ==============================================================================================================================================
// FUNCIONAMIENTO
// ==============================================================================================================================================
// - BTN1 → PLAY / STOP. Play arranca siempre desde el paso 1 y suena en el acto.
// - BTN2 → PANEL A : POT1..POT4 = nota de los pasos 1..4
// - BTN3 → PANEL B : POT1..POT4 = nota de los pasos 5..8
// - BTN4 → PANEL C : POT1 volumen · POT2 velocidad (60–200 BPM, semicorcheas) ·
//                    POT3 decay (30 ms – 1.2 s) · POT4 cutoff (50 Hz – 6 kHz)
// - BTN5 → OCTAVA siguiente (ciclo de 3: La1 · La2 · La3). Cambia también la nota que
//          está sonando.
//
// Notas: cada pot recorre 11 notas de la pentatónica menor (2 octavas). Con el pot
// al mínimo (< 3 % del recorrido) ese paso queda en SILENCIO.
//
// LEDs de la placa:
//   0..3 = panel A/B: los 4 pasos del panel (color = nota, apagado = silencio,
//          blanco = paso sonando) · panel C: nivel de cada parámetro
//   4    = panel activo (A cian · B violeta · C naranjo)
//   5    = octava (brillo) + pulso en cada paso mientras suena (fuerte en los pasos 1 y 5)
//
// Tira externa (121 LEDs): BALAS DE LUZ. Cada paso que suena dispara un pulso desde el
// inicio de la tira que avanza hacia el final con su estela. Color = paso (arcoíris de
// 8 colores) corrido un poco por la nota; los pasos 1 y 5 salen más brillantes y largos.
// Un paso en silencio no dispara. La velocidad sigue al tempo: siempre quedan 15 LEDs
// entre bala y bala, o sea la secuencia entera de 8 pasos cabe volando en la tira.
// ==============================================================================================================================================

#include <Arduino.h>
#include <driver/i2s_std.h>
#include <FastLED.h>
#include <math.h>

// ─── Tipos (arriba del todo para que el IDE de Arduino genere bien los prototipos) ───
struct EstadoSVF { float ic1, ic2; };
struct Bala {
  bool    viva;
  float   pos;        // posición de la punta en la tira (en LEDs, con decimales)
  uint8_t hue;        // color
  uint8_t brillo;     // brillo de la punta
  uint8_t largo;      // largo de la estela (LEDs)
};

// ─── I2S PCM5102 ───────────────────────────────────────────
#define I2S_LCK   39
#define I2S_DIN   40
#define I2S_BCK   41
#define SAMPLE_RATE     44100
#define BUFFER_SAMPLES  128
const float INV_SR = 1.0f / (float)SAMPLE_RATE;

// ─── LEDs WS2812: 6 SMD internos + tira externa encadenada en el mismo pin ──
#define LED_PIN        46
#define STATUS_LEDS     6                     // índices 0..5 = SMD de la placa (estado)
#define TIRA_LEDS     121                     // tira externa: índices 6..126
#define NUM_LEDS      (STATUS_LEDS + TIRA_LEDS)
#define LED_BRIGHT     200
#define LED_TYPE       WS2812
#define COLOR_ORDER    GRB
#define LED_MAX_MA    2000                    // tope de consumo de la tira (FastLED baja el brillo si se pasa)
const unsigned long LED_REFRESH_MS = 16;      // ~60 fps: las balas se mueven suaves
CRGB leds[NUM_LEDS];

// ─── Balas de luz (tira externa) ───────────────────────────
// Cada paso que suena dispara una bala desde el LED 0 de la tira hacia el final.
// La velocidad va atada al tempo: entre bala y bala quedan siempre ESPACIO_BALAS LEDs,
// así que la tira muestra la secuencia entera volando (8 pasos × 15 = 120 LEDs).
#define MAX_BALAS      16
const float   ESPACIO_BALAS = 15.0f;          // LEDs recorridos por paso
const uint8_t HUE_PASO[8] ={ 0, 28, 56, 96, 130, 160, 190, 225 };  // arcoíris por paso
Bala balas[MAX_BALAS];

// ─── Botones (INPUT_PULLUP) ────────────────────────────────
#define BTN1_PIN   44
#define BTN2_PIN   42
#define BTN3_PIN    0
#define BTN4_PIN   45
#define BTN5_PIN   47
const unsigned long DEBOUNCE_MS = 150;

// ─── Potenciómetros ────────────────────────────────────────
#define POT1   1    // ADC1
#define POT2   2    // ADC2
#define POT3   8    // ADC8
#define POT4  10    // ADC10
const uint8_t POT_PIN[4] = { POT1, POT2, POT3, POT4 };

// ==============================================================================================================================================
// ESCALA — La pentatónica menor, 2 octavas + la tónica de arriba = 11 notas por pot
// ==============================================================================================================================================
#define NUM_PASOS   8
#define NUM_NOTAS  11
const int8_t PENTA_MENOR[5] = { 0, 3, 5, 7, 10 };    // La · Do · Re · Mi · Sol
const float  FREC_BASE      = 55.0f;                 // La1
const float  ZONA_SILENCIO  = 0.03f;                 // pot bajo esto = paso en silencio
#define NUM_OCTAVAS 3                                // BTN5: La1 · La2 · La3

// nota (0..10) + octava → semitonos sobre La1
inline int notaASemitono(int nota, int octava) {
  return octava * 12 + (nota / 5) * 12 + PENTA_MENOR[nota % 5];
}

// ==============================================================================================================================================
// TIMBRE (fijo) — lo que no está en un pot se ajusta acá
// ==============================================================================================================================================
const float DESAFINE_CENTS = 9.0f;      // segunda sierra
const float NIVEL_SIERRAS  = 0.50f;     // cada sierra
const float NIVEL_SUB      = 0.32f;     // cuadrada una octava abajo (cuerpo)
const float DRIVE          = 1.25f;     // saturación suave antes del filtro
const float ENV_FILTRO_OCT = 3.2f;      // cuánto abre el filtro cada nota (octavas)
const float RES_MIN        = 0.9f;      // Q con el cutoff arriba
const float RES_MAX        = 2.6f;      // Q con el cutoff abajo (la resonancia va atada al corte)
const float FILTRO_TECHO   = 12000.0f;
const float TAU_SOLTAR     = 0.025f;    // paso en silencio / stop: cierre de 25 ms
const float ATAQUE_S       = 0.002f;    // ataque de amplitud
const float ATAQUE_FILTRO_S = 0.0015f;  // ataque de la envolvente de filtro (anti-clic)
const float MASTER         = 0.80f;

const float DRIVE_COMP = 1.0f / (0.75f + 0.25f * DRIVE);
const float SUAVIZADO  = 1.0f - expf(-1.0f / (0.012f * SAMPLE_RATE));   // pots → 12 ms

// ==============================================================================================================================================
// PEDIDOS ENTRE NÚCLEOS
// ==============================================================================================================================================
// control → audio : notaPaso[]  pVol  pVel  pDecay  pCorte  octava  tocando
// audio → control : pasoSonando  contadorPasos
// Son escrituras de 32 bits alineadas, atómicas en el S3: no hace falta mutex.
volatile int   notaPaso[NUM_PASOS] = { 0, 5, 0, 3,  0, 4, 2, 1 };  // patrón de arranque
volatile float pVol   = 0.70f;          // 0..1
volatile float pVel   = 0.43f;          // 0..1 → 60..200 BPM (0.43 ≈ 120)
volatile float pDecay = 0.40f;          // 0..1 → 30 ms .. 1.2 s
volatile float pCorte = 0.45f;          // 0..1 → 50 Hz .. 6 kHz
volatile int   octava = 0;              // 0..2
volatile bool  tocando = false;
volatile int      pasoSonando   = -1;   // −1 = detenido
volatile uint32_t contadorPasos = 0;    // sube en cada paso (latido de los LEDs)

// ─── Estado de la tarea de AUDIO ───────────────────────────
bool     aTocando    = false;
int      aOctava     = 0;
int      pasoAudio   = 0;               // próximo paso a disparar
uint32_t muestrasPaso = 0;              // muestras que faltan para el próximo paso
int      notaActual  = -1;              // nota que está sonando (para re-afinar al cambiar octava)

float frec = 110.0f;
float fase1 = 0.0f, fase2 = 0.37f, faseSub = 0.0f;
float razonDesafine = 1.0f;

float env = 0.0f;       bool atacando = false;   bool soltando = false;
float envF = 0.0f;      bool atacandoF = false;
float mulDecay = 0.999f, mulDecayF = 0.999f, mulSoltar = 0.999f;

float volS = 0.7f, corteS = 0.45f;      // parámetros suavizados por muestra
float svfG = 0.1f, svfK = 1.0f, svfA1 = 1.0f, svfA2 = 0.0f, svfA3 = 0.0f, compQ = 1.0f;
EstadoSVF svf = { 0.0f, 0.0f };
float dcX1 = 0.0f, dcY1 = 0.0f;

// ─── Estado de la tarea de CONTROL ─────────────────────────
#define PANEL_A 0
#define PANEL_B 1
#define PANEL_C 2
int   panel = PANEL_A;
float potEntrada[4];                    // lectura al entrar al panel
bool  potTomado[4];                     // true = el pot ya se movió y manda
int   ctlNota[NUM_PASOS];               // última nota cuantizada (histéresis)
const float UMBRAL_TOMA = 0.05f;        // cuánto hay que mover un pot para que tome el control

bool bNivel[5] = { HIGH, HIGH, HIGH, HIGH, HIGH };
unsigned long bTiempo[5] = { 0, 0, 0, 0, 0 };
const uint8_t BTN_PIN[5] = { BTN1_PIN, BTN2_PIN, BTN3_PIN, BTN4_PIN, BTN5_PIN };

float flashNivel = 0.0f;                // destello al cambiar panel / octava / play
float pulsoPaso  = 0.0f;

static i2s_chan_handle_t tx_chan;

// ─── Lectura de pot con sobre-muestreo (core 0: no le roba tiempo al audio) ──
float readPot(uint8_t pin) {
  uint32_t sum = 0;
  for (int i = 0; i < 8; i++) sum += analogRead(pin);
  return (float)(sum >> 3) / 4095.0f;
}

// ==============================================================================================================================================
// SÍNTESIS
// ==============================================================================================================================================

// ─── PolyBLEP: corrige el salto de la sierra → sin aliasing ──
inline float polyBlep(float t, float dt) {
  if (t < dt) { t /= dt; return t + t - t * t - 1.0f; }
  else if (t > 1.0f - dt) { t = (t - 1.0f) / dt; return t * t + t + t + 1.0f; }
  return 0.0f;
}

inline float sierra(float fase, float dt) {
  return (2.0f * fase - 1.0f) - polyBlep(fase, dt);
}

inline float cuadrada(float fase, float dt) {
  float p2 = fase + 0.5f; if (p2 >= 1.0f) p2 -= 1.0f;
  return (sierra(fase, dt) - sierra(p2, dt)) * 0.5f;
}

// ─── Saturación suave (aproximación racional de tanh) ──────
inline float softClip(float x) {
  if (x >  3.0f) x =  3.0f;
  if (x < -3.0f) x = -3.0f;
  return x * (27.0f + x * x) / (27.0f + 9.0f * x * x);
}

// ─── Mapeos de los parámetros del panel C (tarea de audio) ──
inline float bpmDe(float v)      { return 60.0f + v * 140.0f; }
inline float tauDecayDe(float v) { return 0.03f * powf(40.0f, v); }
inline float corteHzDe(float v)  { return 50.0f * powf(120.0f, v); }

// ─── Disparar un paso (tarea de audio) ─────────────────────
void dispararPaso(int i) {
  int n = notaPaso[i];
  pasoSonando = i;
  contadorPasos++;
  if (n < 0) {                          // paso en silencio: se cierra la nota anterior
    soltando = true;
    atacando = false;
    return;
  }
  notaActual = n;
  frec = FREC_BASE * powf(2.0f, (float)notaASemitono(n, aOctava) / 12.0f);
  // La fase NO se reinicia y el ataque sube desde donde esté la envolvente:
  // una nota encima de otra no produce saltos en la onda → sin clic.
  atacando  = true;
  soltando  = false;
  atacandoF = true;
}

// ─── Coeficientes del SVF (cada 8 muestras) ────────────────
void calcularFiltro() {
  float oct = ENV_FILTRO_OCT * envF;
  float fc = corteHzDe(corteS) * powf(2.0f, oct);
  if (fc > FILTRO_TECHO) fc = FILTRO_TECHO;
  if (fc < 20.0f) fc = 20.0f;

  float q = RES_MAX - (RES_MAX - RES_MIN) * corteS;
  svfG  = tanf((float)M_PI * fc * INV_SR);
  svfK  = 1.0f / q;
  svfA1 = 1.0f / (1.0f + svfG * (svfG + svfK));
  svfA2 = svfG * svfA1;
  svfA3 = svfG * svfA2;
  compQ = 1.0f / powf(q, 0.30f);
}

// SVF de Zavalishin (TPT): estable aunque el corte cambie rápido
inline float filtroLP(EstadoSVF &s, float x) {
  float v3 = x - s.ic2;
  float v1 = svfA1 * s.ic1 + svfA2 * v3;
  float v2 = s.ic2 + svfA2 * s.ic1 + svfA3 * v3;
  s.ic1 = 2.0f * v1 - s.ic1;
  s.ic2 = 2.0f * v2 - s.ic2;
  return v2;
}

// ==============================================================================================================================================
// LEDs (tarea de control)
// ==============================================================================================================================================
const uint8_t HUE_PANEL[3] = { 140, 195, 18 };   // A cian · B violeta · C naranjo

// ─── Tira externa: balas de luz ────────────────────────────
inline void pixelTira(int i, const CRGB &c) {       // i = 0..TIRA_LEDS-1 (suma, no pisa)
  if (i >= 0 && i < TIRA_LEDS) leds[STATUS_LEDS + i] += c;
}

// Dispara una bala desde el inicio de la tira. Color = paso (arcoíris) corrido por la
// nota; los pasos 1 y 5 salen más brillantes y con estela más larga.
void dispararBala(int paso, int nota) {
  int slot = 0;
  float masLejos = -1.0f;
  for (int i = 0; i < MAX_BALAS; i++) {
    if (!balas[i].viva) { slot = i; break; }
    if (balas[i].pos > masLejos) { masLejos = balas[i].pos; slot = i; }  // sin libres: la más lejana
  }
  bool fuerte = (paso == 0 || paso == 4);
  Bala &b = balas[slot];
  b.viva   = true;
  b.pos    = 0.0f;
  b.hue    = HUE_PASO[paso] + (uint8_t)(nota * 5);
  b.brillo = fuerte ? 255 : 170;
  b.largo  = fuerte ? 11 : 6;
}

// Mueve y dibuja todas las balas. La velocidad sale del tempo actual: ESPACIO_BALAS
// LEDs por paso, así la separación entre balas es la misma a cualquier velocidad.
void renderBalas(unsigned long dtMs) {
  for (int i = STATUS_LEDS; i < NUM_LEDS; i++) leds[i] = CRGB(0, 0, 0);
  if (dtMs > 60) dtMs = 60;
  float msPaso = 60000.0f / ((60.0f + pVel * 140.0f) * 4.0f);
  float avance = ESPACIO_BALAS * (float)dtMs / msPaso;

  for (int k = 0; k < MAX_BALAS; k++) {
    Bala &b = balas[k];
    if (!b.viva) continue;
    b.pos += avance;
    if (b.pos - (float)b.largo > (float)TIRA_LEDS) { b.viva = false; continue; }

    for (int j = 0; j <= b.largo; j++) {
      float x = b.pos - (float)j;
      if (x < 0.0f) break;
      float caida = 1.0f - (float)j / (float)(b.largo + 1);
      float v = (float)b.brillo * caida * caida;          // estela que se apaga cuadrática
      uint8_t sat = (j == 0) ? 90 : 255;                  // punta casi blanca, estela de color
      int   i0 = (int)x;
      float fr = x - (float)i0;                           // sub-píxel: avanza suave, sin saltos
      pixelTira(i0,     CHSV(b.hue, sat, (uint8_t)(v * (1.0f - fr))));
      pixelTira(i0 + 1, CHSV(b.hue, sat, (uint8_t)(v * fr)));
    }
  }
}

void renderLEDs() {
  unsigned long t = millis();
  static unsigned long ultimoFrame = 0;
  static uint32_t ultimoPaso = 0;
  if (t - ultimoFrame < LED_REFRESH_MS) return;
  unsigned long dtMs = t - ultimoFrame;
  ultimoFrame = t;

  int ps = pasoSonando;
  uint32_t cp = contadorPasos;
  if (cp != ultimoPaso) {
    ultimoPaso = cp;
    pulsoPaso = (ps == 0 || ps == 4) ? 1.0f : 0.45f;
    if (tocando && ps >= 0) {
      int n = notaPaso[ps];
      if (n >= 0) dispararBala(ps, n);             // paso en silencio = no hay bala
    }
  }
  renderBalas(dtMs);

  if (panel == PANEL_C) {
    const float val[4] = { pVol, pVel, pDecay, pCorte };
    const uint8_t hue[4] = { 96, 64, 170, 18 };
    for (int i = 0; i < 4; i++)
      leds[i] = CHSV(hue[i], 230, 10 + (uint8_t)(val[i] * 200.0f));
  } else {
    int base = (panel == PANEL_A) ? 0 : 4;
    for (int i = 0; i < 4; i++) {
      int n = notaPaso[base + i];
      if (n < 0) leds[i] = CRGB(0, 0, 0);
      else       leds[i] = CHSV((uint8_t)(n * 22), 240, 70);
      if (tocando && ps == base + i) leds[i] = CRGB(200, 200, 200);
    }
  }

  // LED 4 → panel activo
  leds[4] = CHSV(HUE_PANEL[panel], 255, 150);

  // LED 5 → octava + pulso de cada paso
  const uint8_t OCT_VAL[NUM_OCTAVAS] = { 40, 90, 160 };
  leds[5] = tocando ? CHSV(96, 220, OCT_VAL[octava]) : CHSV(0, 220, OCT_VAL[octava] / 3);
  if (tocando && pulsoPaso > 0.02f) {
    uint8_t p = (uint8_t)(pulsoPaso * 200.0f);
    leds[5] += CRGB(p, p, p);
  }
  pulsoPaso *= 0.6f;

  if (flashNivel > 0.02f) {
    uint8_t w = (uint8_t)(flashNivel * 140.0f);
    for (int i = 0; i < STATUS_LEDS; i++) leds[i] += CRGB(w, w, w);   // el destello no toca la tira
    flashNivel *= 0.55f;
  }

  FastLED.show();
}

// ==============================================================================================================================================
// CONTROLES (tarea de control)
// ==============================================================================================================================================

// Nota cuantizada con HISTÉRESIS: el ruido del ADC no hace saltar la nota en los bordes.
int cuantizarNota(int paso, float v) {
  if (v < ZONA_SILENCIO) return -1;
  float x = (v - ZONA_SILENCIO) / (1.0f - ZONA_SILENCIO);
  float f = x * (float)(NUM_NOTAS - 1);
  int cand = (int)(f + 0.5f);
  if (cand < 0) cand = 0;
  if (cand > NUM_NOTAS - 1) cand = NUM_NOTAS - 1;
  int cur = ctlNota[paso];
  if (cur >= 0 && cand != cur && fabsf(f - (float)cur) < 0.65f) cand = cur;
  return cand;
}

// Al entrar a un panel se anota dónde está cada pot; ninguno manda hasta que se mueva.
void entrarPanel(int p) {
  panel = p;
  for (int i = 0; i < 4; i++) {
    potEntrada[i] = readPot(POT_PIN[i]);
    potTomado[i]  = false;
  }
  flashNivel = 0.5f;
}
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
void loop() { vTaskDelay(1000 / portTICK_PERIOD_MS); }
#endif

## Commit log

2026-03-15 Initial commit: PercuSynth firmware, README y CLAUDE.md
    - Tres firmwares ESP32: drum machine, MIDI controller y sintetizador
    - README en español con descripción, pinout y estructura del proyecto
    - CLAUDE.md con guía de arquitectura para Claude Code
    - Imágenes: renders 3D y diagrama de pinout
2026-03-15 Reescribir README y agregar prompt para IA
    - README reenfocado: PercuSynth como laboratorio de experimentación STEAM,
    no limitado a 3 firmwares; percusión como excusa artística de aprendizaje
    - Mención del uso del pinout directamente con asistentes de IA
    - Referencia al proyecto hermano Proto-Synth v2
    - Nuevo archivo Documentos/PROMPT_IA.md: prompt listo para copiar/pegar
    en cualquier IA con contexto completo del hardware y estilo de código
2026-03-15 Agregar firmware test_leds y completar pinout
    - Nuevo firmware test_leds.ino: 6 modos de animación WS2812 (sólido,
    chase, rainbow, twinkle, pulso, meteor), LEDs 7-150 activos,
    botones cambian modo/dirección, POTs controlan brillo/color/velocidad/param
    - README y CLAUDE.md: pinout completo con pin 46 (LED WS2812), pin 43
    (MIDI DIN-5), I2C 21/38 (MPU6050) y sensores externos 3/9
2026-03-15 Fix BTN5 apagar: usar flag toggle en vez de clear puntual
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2026-05-20 Aplicar header proto-synth-v2 a firmwares + actualizar docs
    - Headers consistentes en los 6 firmwares hand-written (drum_machine_basic,
    MIDI_Drum, synth_basico, test_leds, drum_midi_leds) con bloques HARDWARE /
    ARDUINO IDE / LIBRERÍAS / DESCRIPCIÓN / FUNCIONAMIENTO al estilo de proto-synth-v2
    - README raíz reorganizado: quita refs muertas a synth_studio y serial_test,
    agrega step_sequencer_midi + dub_siren, clarifica que samples/ son firmwares
    auto-generados por las webapps
    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
2026-05-20 Agregar firmwares dub_siren y step_sequencer_midi
    - firmwares/dub_siren/: sintetizador sirena dub con 3 samples polifónicos +
    oscilador siren + LFO + delay tape con feedback. .ino generado por
    tools/dub_siren_generator/ con samples ya embebidos (Ahhh, cumbia nena,
    sabor). Plan completo de arquitectura en PLAN.md
    - firmwares/step_sequencer_midi/: sample sequencer 6×16 que actúa como
    MIDI Clock Master por USB. Pareja del tool step_sequencer_loader que lo
    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
2026-05-20 Agregar webapps de tools/: panel de control, loaders y secuenciador remoto
    5 webapps standalone (HTML + CSS + JS inline, sin build) que cumplen 3 roles:
    GENERADORES DE FIRMWARE (drag & drop audios → .ino con samples PROGMEM):
    - tools/loop_loader/: 3 loops + 6 hits con preview en navegador
    - tools/loops/bpm_mono_44100/: variante BPM-aware con tap-tempo y snap a compás
    - tools/dub_siren_generator/: dub siren con 3 samples + siren osc + delay
    FLASHEO DESDE EL NAVEGADOR (ESP Web Tools):
    - tools/percu_control/: panel universal con osciladores, mixer, ruido, drive,
    filtro, LFO y master + botón FLASH FW que instala firmware.bin al ESP32-S3
    CONTROL REMOTO EN VIVO (Web MIDI):
    - tools/step_se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
2026-05-20 Agregar biblioteca de samples generados + media (video, fotos, informe PDF)
    samples/: 5 firmwares .ino auto-generados por las webapps de tools/, con
    samples ya embebidos como PROGMEM. Sirven de "ejemplos vivos" para flashear
    directo y ver qué se puede armar:
    - Industrial / industrial_dos (bpm_mono_44100)
    - percusynth_samples / percusynth_samples2 (sample_loader)
    - percusynth_loop_player (loop_loader)
    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
2026-06-09 Actualiza repo: nuevos firmwares, herramientas, hardware y documento para IA
    Firmwares nuevos: trance_imu, trance_imu_leds, trance_midi_leds, impact_chimes, seismic_drone, matrix_midi_anyma y tests del IMU (test_imu/_led/_sound). Herramientas: video_synth y midi_sampler. Jueg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
2026-06-15 Agregar tool arp_matrix: arpegiador polifonico + matriz LED redonda + genera .ino
    Webapp standalone (tools/arp_matrix/index.html) estilo percu_control: arpegiador
    polifonico (6 patrones, 8 modos griegos, 4 octavas, rango 1-3 oct), 3 paneles de
    control (PRINCIPAL/ADSR/TIMBRE via combos), filtro resonante LPF/HPF/BPF + PWM + LFO
    + sub-osc, ruido como voz del arpegio, matriz LED 64x32 horizontal con LEDs redondos
    (NEXUS/LISSAJOUS/PLASMA/FRACTAL), Web Serial para espejar el PercuSynth y boton para
    generar el .ino con el mismo motor. Scheduler de audio con look-ahead (tempo estable).
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2026-06-16 Agregar firmware pads_imu: pads profundos polifonicos + arpegio
    Hermano ambient de trance_imu sin secuenciador: los 5 botones latchean
    acordes absolutos sostenidos (3 bancos: C/G/Am/F/Dm, C/Am/Em/F/G,
    C/Am/E7/F/G) como pads profundos estereo (AHR + LFO de movimiento).
    Capa opcional de arpegio sobre el acorde activo (Panel B). Filtro biquad
    resonante barrido por el IMU. Anti-glitch: LUT semitono->freq, robo de
    voz por menor amplitud, mas buffers DMA y guardia anti-denormal.
    Incluye README y Guia Express (HTML + PDF, marca GC Lab Chile).
    [pads_imu.ino]
2026-06-16 pads_imu: volumen del pad (Panel A) independiente del arpegio
    El POT2 del Panel A (volumen) ahora afecta SOLO a los acordes del pad.
    Las voces se mezclan en dos buses separados (pad y arpegio); g_volume se
    aplica solo al bus del pad, y el arpegio conserva su propio volumen
    (arpVol, POT1 del Panel B). Ademas se corrige el Gate del arpegio
    (reescalado a -6.5 = largo real de la nota) y se agrega tope ARP_MAX=8
    de voces del arpegio para evitar el desborde de polifonia que saturaba
    la CPU al subir el Gate. README y Guia Express (HTML+PDF) actualizados.
    [pads_imu.ino]
2026-06-17 pads_imu: variante con LEDs + Panel C en vivo, 5 bancos y arpegio mejorado
    Nuevo firmware pads_imu_leds: mismo motor que pads_imu + visualizador en
    los 6 LEDs SMD de la placa (paleta por panel, flash al cambiar de panel,
    barra VU de energia del pad, y un punto que corre con el arpegio). FastLED
    via RMT, render throttled tras el i2s_write (no choca con el audio).
    Cambios en ambos firmwares:
    - Panel C todo EN VIVO sin reiniciar el pad: BTN1/BTN5 cambian tipo de
    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
2026-09-11 oscilador_escalas: audio en el core 1, controles en el core 0
    El ruido al cambiar de onda con los cuatro osciladores sonando era falta de
    tiempo, no un problema de senal: el render de 128 muestras, 16 lecturas de
    ADC, el I2C del IMU y FastLED.show() iban todos en loop() y la vuelta se
    pasaba de los 2,9 ms del buffer, asi que el DMA sacaba ceros. Ahora el audio
    tiene su tarea fijada al core 1, y botones, pots, IMU y LEDs corren a 1 kHz
    en el core 0 dejando pedidos que el audio aplica en el borde de cada buffer.
    De paso, el tap tempo abre serie nueva cuando un intervalo se aparta mas del
    35 % del tempo en curso: antes la pausa entre dos series se promediaba como
    un pulso y arrastraba el tempo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
    [oscilador_escalas.ino]
2026-09-11 skill: las reglas de sintesis que salieron de drum_poder
    Que se satura y que no (solo lo que tiene una parcial fuerte), el ratio del
    modulador FM siempre sobre 2, transitorios con ruido filtrado y nunca con un
    seno, las tres bandas de un bombo con peso, un parche por instrumento, el
    presupuesto de decay por banda, lookahead en el limitador con el pasa-bajos
    del master despues, la normalizacion de la reverb de peines, el umbral de
    apagado de voz y por que los agudos molestos son un bug.
    Ademas queda anotado que el MIDI DIN-5 va por el GPIO 43, que es tambien el
    TX del Serial0: en un firmware con DIN-5 hay que imprimir solo por USB CDC.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
2026-10-06 Firmwares nuevos, industrial_matriz al día y documentación de todo
    - industrial_matriz: la fábrica industrial siempre en fase con la base (ciclos de 16 o 32
    pasos calculados desde el paso de la base; los de 10–24 se cortaban cada 4 compases y no
    calzaban) y oscilador continuo en el POT4 del menú: dos sierras con detune leve, pasa-bajos
    resonante con LFO de velocidad aleatoria, estéreo, chorus y delay ping-pong.
    - Firmwares nuevos: bajo_8_pasos (hecho con los participantes del taller abierto en Hive),
    bajo_8_pasos_fsr_clock, grabador_campo, la_partida, mezclador_pistas, trance_pistas,
    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
    [base_percusynth_v2.3mf, base_percusynth_v2.stl]
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

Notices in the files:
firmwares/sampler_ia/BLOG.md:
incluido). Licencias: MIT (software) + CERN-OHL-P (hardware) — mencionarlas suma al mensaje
